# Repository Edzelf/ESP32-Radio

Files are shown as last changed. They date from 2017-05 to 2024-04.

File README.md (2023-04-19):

# Please use the V2 version of the ESP32-Radio.
# See https://github.com/Edzelf/ESP32Radio-V2
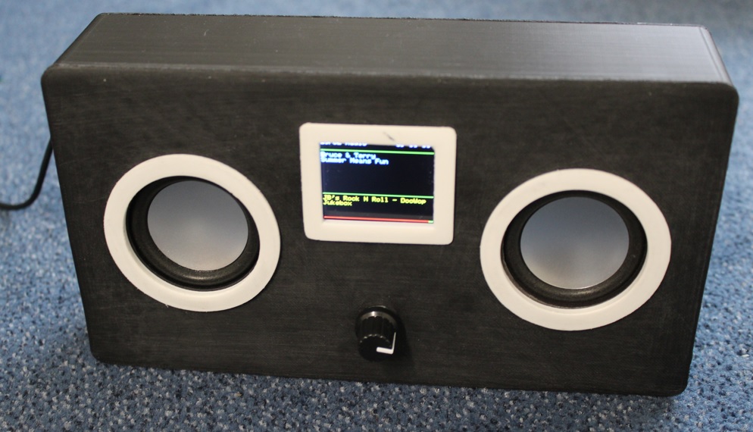
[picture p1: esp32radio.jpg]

Internet radio based on ESP32, VS1053 and a TFT screen.  Will compile in Arduino IDE.
See the review by Andreas Spiess at https://www.youtube.com/watch?v=hz65vfvbXMs.

Look for documentation and printdesign in the doc directory.

Features:
-	Can connect to thousands of Internet radio stations that broadcast MP3 or Ogg audio streams.
- Can connect to a standalone mp3 file on a server.
- Support for .m3u playlists.
- Can play mp3 tracks from SD card or USB stick (CH376).
-	Uses a minimal number of components; no Arduino required.
-	Handles bitrates up to 320 kbps.
-	Has a preset list of maximal 100 favorite radio stations in configuration file.
- Configuration (preferences) can be edited through web interface.
-	Can be controlled by a tablet or other device through a build-in webserver.
- Can be controlled over MQTT.
- Can be controlled over Serial Input.
- Can be controlled by IR.
-	Can be controlled by rotary switch encoder.
- Can be controlled by touch pins.
-	Up to 14 free input pins can be configured to control the radio.
-	The strongest available WiFi network is automatically selected.
-	Heavily commented source code, easy to add extra functionality.
-	Debug information through serial output.
-	Uses a 12 kB queue to provide smooth playback.
-	Software update over WiFi possible (OTA) through Arduino IDE or remote host.
-	Bass and treble control.
-	Saves volume, bass, treble and preset station over restart.
- Configuration also possible if no WiFi connection can be established.
- Can play iHeartRadio stations.
- Displays time of day on TFT.
- Optional display remaining battery capacity on screen.
- PCB available (see doc).
- 3D case available (see doc).

See documentation in doc/pdf-file.

Last changes:
- 28-jun-2021, Allow special characters in station name.
- 21-jun-2021, Display station name from preference if not in metadata.
- 29-apr-2021, Fixed SSD1309 bug.
- 25-apr-2021, Fixed SSD1309 bug, thanks to Juraj Liso.
- 19-feb-2021, More Oled models.
- 16-feb-2021, Give BBC stations some time to react. See issue 437.
- 15-feb-2021, Added earch page.
- 21-jan-2021, Added PlatformIO version.
- 14-oct-2020, Clear artist and song on display at new station connect.
- 18-oct-2020, Fixed LCD2004 error.
- 30-sep-2020, Ready for ch376msc library version 1.4.4.
- 14-jul-2020, Dynamic status display in web interface.
- 10-jul-2020, Support for USB drive (CH376).
- 23-mar-2020, Allow playlists  on SD card.
- 21-dec-2019, Check for right (VS1053) CHIP.
- 16-dec-2019, Better logging claimSPI for debug.
- 24-apr-2019, Better handling of gettim().
- 09-oct-2018, Bug fix xSemaphoreTake.
- 04-oct-2018, Fixed compile error OLED 64x128 display.
- 28-sep-2018, Support for NEXTION display.
- 06-aug-2018, Added playlistposition for MQTT.  Correction negative time offset. OTA update through remote host.
- 02-aug-2018, Added support for ILI9341 display.
- 01-aug-2018, Added debug info for timing of IR remote.
- 30-jul-2018, Added GPIO39 and inversed shutdown pin.  Thanks to fletche.
- 25-jul-2018, Correction touch pins.
- 15-jul-2018, Correction tftset().
- 25-may-2018, Limit read from stream to free queue space.
- 04-may-2018, Made handling of playlistdata more tolerant.
- 31-may-2018, Bugfix. Crashed if I2C was used, but no pins assigned.
- 30-may-2018, Bugfix. Assigned DRAM to global variables used in ISRs.
- 11-may-2018, Bugfix for incidental crash in rotary encoder function.
- 08-may-2018, Support for 1602 display (I2C).
- 30-apr-2018, Bugfix: crashed when no IR was configured.
- 25-apr-2018, Support for different display (OLED 128x64 for now).
- 20-apr-2018, Added (unfinished) diptrace printdesign.
- 16-apr-2018, Handle ID3 tags while playing from SD.
- 13-apr-2018, Guard against empty strings on TFT.
- 05-mar-2018, Improved interface for Rotary Encoder.
- 03-mar-2018, Correction bug IR pin number.
- 15-feb-2018, Correction writing wifi credentials to NVS.
- 13-feb-2018, Disable clock during write-back of preferences.
- 22-jan-2018, Added remaining battery capacity, default I/O pins.
- 02-jan-2018, Stop/resume is one command now.
- 15-dec-2017, Correction defaultprefs.h.
- 13-dec-2017, Correction LCD display.
- 08-dec-2017, Faster handling of config page, more items published by MQTT, added pin_shutdown.
- 01-dec-2017, Better handling of playlists.
- 30-nov-2017, Hide passwords in config screen.
- 27-nov-2017, Replaced ringbuffer by FreeRTOS queue, play function on second CPU,
               Included improved rotary switch routines supplied by fenyvesi,
               Better IR sensitivity.
- 11-nov-2017: Increases ringbuffer size. Print measured bitrate at "test"-command.
- 30-aug-2017: Limit number of retries foor MQTT connection. Added MDNS transponder.
- 28-aug-2017: Preferences for SPI bus, touch pins.
               Corrected bug in handling programmable pins.
               Handling of http redirections.
- 28-jul-2017: Added rotary swich encoder, flexible GPIO assignment.
- 19-jul-2017: Minor corrections.
- 18-jul-2017: Show time of day on TFT.
- 04-jul-2017: Correction MQTT subscription, keep playing during long oprerations.
- 03-jul-2017: Webinterface control page shows current settings.
- 30-jun-2017: Improved MP3 player.
- 28-jun-2017: Added IR interface.
- 31-may-2017: Experimental: play MP3 tracks from SD card.
- 26-may-2017: Correction Upper/Lower Case compare.
- 26-may-2017: Allow connection from single hidden AP.
- 23-may-2017: First release, derived from ESP8266 version.

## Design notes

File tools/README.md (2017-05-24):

- Esp32_radio_init.ino is a tool to set preferences like WiFi networks to the ESP32.
- prefbug.ino          is a tool to test the NVS library.

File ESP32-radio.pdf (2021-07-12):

### ESP32-radio

This document describes the realization of an Internet radio based on an ESP32 WiFi module.
The ESP32 is the successor of the ESP8266. For the ESP8266 an Internet radio was build and now the software is ported to the ESP32. The Internet radio described here uses the ESP32 as well as a VS1053 module to decode the MP3 stream. A 1.8 TFT color display to give some information about the radio station that’s playing. This display has also a SD card slot. Mp3 tracks on an SD card can be played by the ESP32-radio. Other types of display are also supported, including NEXTION.

### Features:

- Can connect to thousands of Internet radio stations that broadcast MP3 audio streams.
- Can connect to a standalone mp3-file on a server.
- mp3 playlists supported.
- Can play MP3 files from SD card or USB flash drive.
- Uses a minimal number of components.
- Has a preset list of a maximum of 100 favorite radio stations as preferences in flash.
- Can be controlled by a tablet or other device through the built-in webserver.
- Can be controlled by MQTT commands. Status info is published by using MQTT.
- Can be controlled by commands on the serial input.
- Can be controlled by IR.
- Can be controlled by rotary switch encoder.
- Up to 14 input ports can be configured as control buttons like volume, skip to the next/previous/first/favorite preset station.
- I/O pins for TFT, VS1053, IR and rotary encoder can be configured in preferences.
- The strongest available WiFi network is automatically selected. Passwords are kept as preferences in flash. Heavily commented source code, easy to add extra functionality.
- Debug information through serial output.
- 2

nd processor is used for smooth playback.
- Update of software over WiFi (OTA) through Arduino IDE or remote server.
- Parameters like WiFi information and presets can be edited in the web interface.
- Plays iHeartRadio streams.
- Preset, volume, bass and treble settings are saved in preferences.
- Displays time of day on TFT.
- Optional displays remaining battery charge.
- Bit-rates up to 320 kbps.
- Control of TFT back-light.
- PCB available.
- 3D printable box available.

### Software:

The software for the radio is supplied as an Arduino sketch that can be compiled for the ESP32 using the Arduino IDE version 1.8.5. No Arduino is required in this project.
The following libraries are used:
- WiFi – for establishing the communication with WiFI, part of ESP32 core library
- SPI – for communication with VS1053 and TFT display, part of ESP32 core library
- WiFiMulti - to select the strongest WiFi network
- Adafruit_ST7735– driver for the TFT screen (if configurated).
This driver works also for the red ST7735 display.
- ArduinoOTA for software update over WiFi.
- PubSubClient to handle MQTT messages, see:
https://github.com/knolleary/pubsubclient
- SD and FS for reading from SD card.
- The map with the ESP32-radio sketch must also contain the supplied headerfiles “index_html.h”, “favicon_ico.h”, “radio_css.h”, “config_html.h”, "defaultprefs.h", "mp3play_html.h" and “about_html.h”. These files are included for the webinterface in PROGMEM.
Furthermore the files “Dummytft.h”, “LCD1602”, “SSD1306.h”, “bluetft.h”, “ILI9341.h”, “NEXTION.h” must be included in this map for the different LCD/OLED displays.

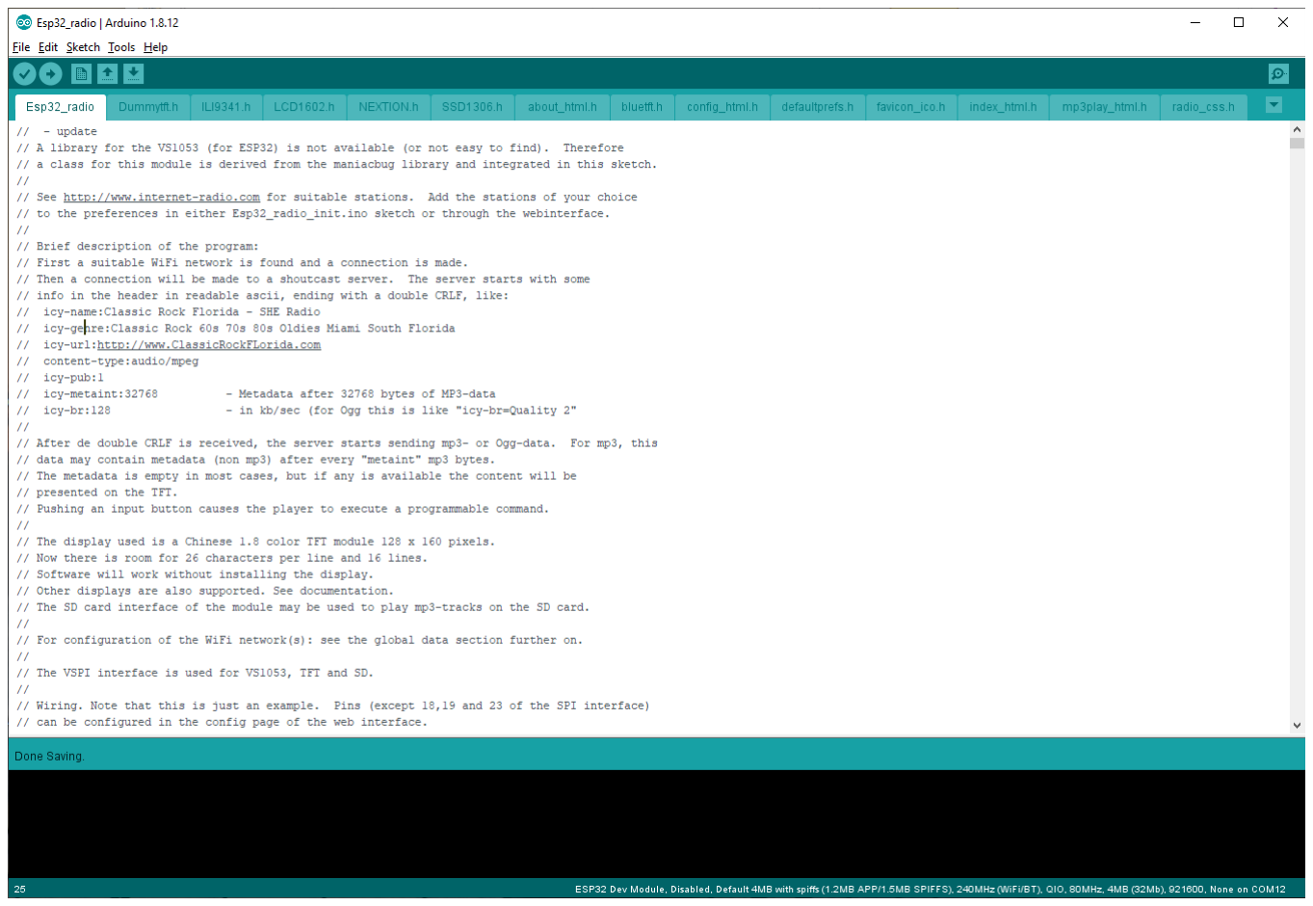
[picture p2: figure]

Preferences
Preferences for ESP32-Radio are kept in Flash memory (NVS).
You may change the contents of NVS with the “Config”-button in the web interface. An example of the contents is:
bat0 | = 2178 | # ADC for 0% battery capacity left
bat100 = 3256 | # ACD for 100% battery capacity
clk_dst = 1
clk_offset = -1
clk_server = pool.ntp.org
fs = USB
gpio_00 = uppreset = 1
gpio_12 = upvolume = 2
gpio_13 = downvolume = 2
ir_40BF = upvolume = 2
ir_C03F = downvolume = 2
mqttbroker = none
mqttpasswd = none
mqttport = 1883
mqttuser = carol
pin_enc_clk = 25 | # GPIO rotary encoder CLK
pin_enc_dt = 26 | # GPIO rotary encoder DT
pin_enc_sw = 27 | # GPIO rotary encoder SW
pin_ir = 35 | # GPIO IR receiver VS1838B
pin_sd_cs = 21 | # GPIO SD card CS
pin_tft_cs = 15 | # GPIO TFT CS
pin_tft_dc = 2 | # GPIO TFT DC
pin_vs_cs = 5 | # GPIO VS1053 CS
pin_vs_dcs = 16 | # GPIO VS1053 DCS
pin_vs_dreq = 4 | # GPIO VS1053 DREQ
preset = 4
preset_000 = 109.206.96.34:8100 | # 0 - NAXI LOVE RADIO, Belgrade, Serbia
preset_001 = airspectrum.cdnstream1.com:8114/1648_128 # 1 - Easy Hits Florida 128k preset_002 = airspectrum.cdnstream1.com:8142/1303_128 # 2 - CLASSIC ROCK MIAMI 256k preset_003 = airspectrum.cdnstream1.com:8000/1261_192 # 3 - Magic Oldies Florida
preset_004 = airspectrum.cdnstream1.com:8008/1604_128 # 4 - Magic 60s Florida 60s Classic Rock
preset_005 = 198.58.98.83:8258/stream | # 5 - Classic Rock Florida HD
preset_006 = icecast.omroep.nl:80/radio1-bb-mp3 | # 6 - Radio 1, NL
preset_007 = icecast.omroep.nl:80/radio2-bb-mp3 | # 7 - Radio 2, NL
preset_008 = skonto.ls.lv:8002/mp3 | # 8 - Skonto 128k
preset_009 = 94.23.66.155:8106 | # 9 - *ILR CHILL and GROOVE
preset_010 = ihr/IHR_IEDM | # 10 - iHeartRadio IHR_IEDM
preset_011 = ihr/IHR_TRAN | # 11 - iHeartRadio IHR_TRAN
toneha = 0
tonehf = 0
tonela = 0
tonelf = 0
volume = 72
wifi_00 = ADSL-11_plus/xxxxxx wifi_01 = NETGEAR-11/xxxxxx
wifi_02 = ADSL-11/xxxxxx

Not that the size of the NVS is limited to 20 kB.
Lines starting with “#” are comment lines and are ignored. Comments per line (after “#”) will also be ignored, except for the “preset_” lines. The comments on the “preset_” lines are used to identify the presets in the web interface. The maximum line length is 150 characters.
Note that the preset numbers ranges from 000 to 199. The range can be extended by the definition of MAXPRESETS. Note that there is also a limit on the NVS space. If the highest numbered station is reached, the next station will be 00 again. URLs with mp3 files or mp3 playlists (.m3u) are allowed.
Presets starting with "ihr/" are iHeartRadio stations.

Prteferences like "pin_ir", " pin_enc_clk", " pin_enc_dt", " pin_enc_sw", " pin_tft_cs", " pin_tft_dc", " pin_sd_cs", " pin_vs_cs", "pin_vs_dcs" and " pin_vs_dreq" specify the GPIO pins that are wired to the various devices. For a

FEATERBOARD you have to change some settings, especially for TFT and SD card. The pins for SPI default to SCK=18, MISO=19 and MOSI=23, but they may be configured by “pin_spi_sck”, “pin_spi_miso” and “pin_spi_mosi” respectively.
For an I2C display (OLED, LCD1602, LCD2004) there must be definitions for " pin_tft_scl" and " pin_tft_sda".
Remove the lines if a device is not connected.

“pin_shutdown” is the pin that will be set if the radio is not playing or the volume is set to zero. This output-pin can be used to shut down the amplifier.
“pin_shutdownx” has the same function. The output signal is inversed: the pin will be LOW to shut down the amplifier.

"pin_tft_bl" is the pin that controls the back light of a TFT display. The BL is disbled after some time if there is no activity. This helps to reduce power when running on batteries.
"pin_tft_blx" has the same function. The output signal is inversed (LOW to enable the BL pin).

The "gpio_" lines specify input pins and the command that is executed if the input pin goes from HIGH to LOW.

The "touch_" lines specify the GPIO input pins for this signal and the command that is executed if the input pin is activated.

The "ir_XXXX" lines specify IR-codes and the command that is executed if the IR-code is received. The code part is a hexadecimal number in upper-case characters.

The "clk_" lines are used for the display of the current time on the TFT. Please change the values for your timezone. The values in the example are valid for the Netherlands.

The “fs” line specifies the file system for MP3 player mode. The file system can be USB or SD for USB drive and SD card respectively. Note that the sketch must be compiled for USB or SD card support. See the defines for SDCARD and/or CH376.

The “bat0” and “bat100” lines are for displaying the remaining battery capacity on the display. See the details at the paragraph with optional features.

The preferences can be edited in the web interface. Changes will in some cases be effective after restart of the Espradio. If the list of preferences is empty (first start), you may use the default button. The list will show some default values which can be edited.

Using Winamp to find out the correct preset line for a station.

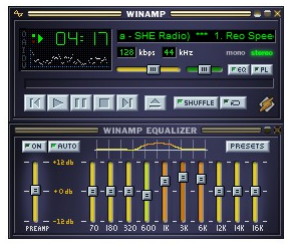
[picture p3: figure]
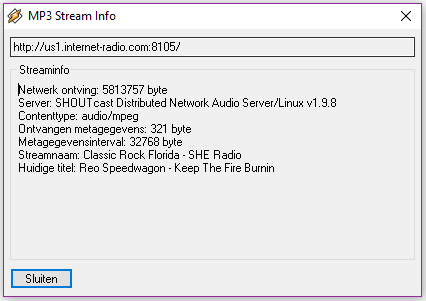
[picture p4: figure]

Press Alt-3 in the main window (left picture). You will see info for the playing station (right picture). The top line (with “http”) will contain the information for the preset, in this example:

“us1.internet-radio.com:8105”. The complete line for this station in the preferences would be:

preset_05 = us1.internet-radio.com:8105 | # 5 - Classic Rock Florida - SHE Radio

Optional features:

Digital control through input pins:
Normally the radio is controlled by the web interface. However, free digital inputs (GPIO) may be connected to buttons to control the radio. Their function can be programmed using the web interface.

You can assign commands to the digital inputs by adding lines in the configuration (Webinterface, "Config" page). Examples:

gpio_00 = uppreset = 1
gpio_12 = upvolume = 2
gpio_13 = downvolume = 2
gpio_14 = stop
gpio_17 = resume
gpio_21 = station = icecast.omroep.nl:80/radio1-bb-mp3

In this example the ESP32-Radio will execute the command "uppreset=1" if GPIO0 will go from HIGH to LOW. The commands are equal to the commands that are handled by the serial input or by the MQTT interface.

The same format can be used for the touch-inputs:

touch_04 = uppreset = 1
touch_13 = upvolume = 2
In this example the ESP32-Radio will execute the command "uppreset=1" if TOUCH0 (GPIO04) will be activated. The commands are equal to the commands that are handled by the serial input or by the MQTT interface.

IR Interface.
The radio can be controlled by an IR remote control like this:

To use this interface, the "out" pin of a VS1838B receiver must be connected to a GPIO pin of the ESP32:

Add the assigned GPIO pin to the preferences through the config page in the web interface. Example:
pin_ir = 35 | # GPIO Pin number for IR receiver VS1838B

VCC is connected to 3.3 Volt. A 220 µF capacitor should be connected between VCC and GND.
The software will read the raw code of the IR transmitter, making it possible to use virtually any remote control to be used. I tested it with the 21 button remote as well as with an LG TV remote.
To assign functions to the buttons, watch the debug log output while pressing a button. For example, press the +volume button. You will see something like:
D: IR code 807F received, but not found in preferences!
Now add the command:
ir_807F = upvolume = 2
to the preferences in the config page of the web interface. Likewise you can assign functions to all buttons, for example:
ir_8A31 = uppreset = 1
ir_719A = station = us1.internet-radio.com:8105
ir_1F6B = mute

Display remaining battery capacity:
The remaining battery capacity is computed by measuring the battery voltage on ping GPIO36 (ADC0).
The battery voltage must be supplied to ADC0 through a resistor voltage divider. The maximum voltage fort his input is 1.0 volt. I used 100 kΩ and 22 kΩ fort his purpose.
Furthermore you need to specify ADC value for both the full and the empty voltages. These values must be in the preferences like:
bat0 | = 2178 | # ADC for 0% battery capacity left
bat100 = 2690 | # ACD for 100% battery capacity

To calibrate the settings you may use the “TEST” command in the serial monitor. This will display the current reading of the ADC0 pin. Do this for a fully charge battery and for an (almost) empty one.
Note that it will take about 6 seconds before the reading is stable. This is a result of a filter in the measurement of the ADC.

The remaining capacity is displayed as a green/red bar near the top of the display.

### Hardware:

The radio is built with the following widely available hardware:
- An ESP-32 module. This is basically an ESP32 on a small print. I used a DOIT ESP32 Development Board. See figure 1 below. The ESP32 is running on 160 MHz. On Aliexpress: this. (https://www.aliexpress.com/item/Elecrow-Official-DOIT-ESP32S-esp32-Development-Board-WiFi-Bluetooth-Dual-Core-CPU-Low-Power-Consumption-DIY/32804562215.html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)
- A VS1053 module. See figure 2.
- A 1.8 inch color TFT display 160x128. Optional, see figure 3 and 4. On Aliexpress: this (https://www.aliexpress.com/item/1-8-Serial-128X160-SPI-TFT-LCD-Module-Display-PCB-Adapter-Power-IC-SD-Socket-R179/32602828489.html) or this. (https://www.aliexpress.com/item/Smart-Electronics-1-8-Inch-128-160-Serial-SPI-TFT-LCD-Module-Display-PCB-Adapter-Power/32597366825.html)
- A 1.44 inch color TFT display 128x128. Optional, see figure 9. On Aliexpress: this. (https://www.aliexpress.com/item/Replace-5110-LCD-1-44-Red-Serial-128X128-SPI-Color-TFT-LCD-Display-Module/32852197696.html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)
- An OLED 128x64 display. Optional, see figure 7. On Aliexpress: this. (https://www.aliexpress.com/item/1pcs-SAMIORE-ROBOT-0-96-white-blue-yellow-0-96-inch-128X64-OLED-Display-Module-0/32640136921.html)
- An 1602 LCD display with I2C backpack. Optional, see figure 8.
- An 2004 LCD display with I2C backpack. Optional, see figure 13.
- A NEXTION display. Optional, see figure 10. Tested with a NX3224T024_011.
- Two small speakers.
- A Class D stereo amplifier to drive the speakers. Best quality if powered by a separate power source.
- A rotary encoder switch. Optional, see figure 4.
- A IR receiver. Optional, see figure 6.
- Two audio transformers. Optional, see figure 11.
- Optional CH376 drive for USB stick, see figure 12.
Fig. 1 | Fig. 2 | Fig. 3

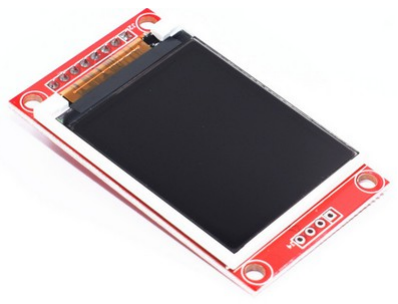
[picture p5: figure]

Fig. 4 | Fig. 5

Fig. 6

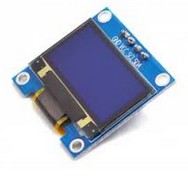
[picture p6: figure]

Fig. 7

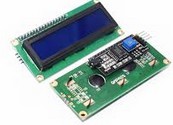
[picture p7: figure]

F

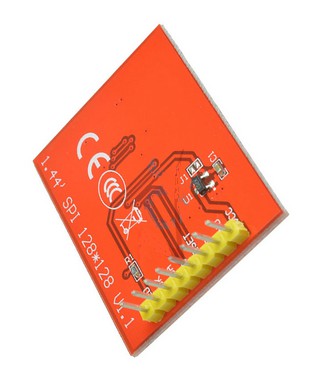
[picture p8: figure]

fig. 8 | Fig. 9

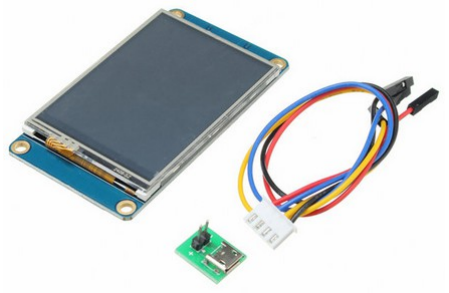
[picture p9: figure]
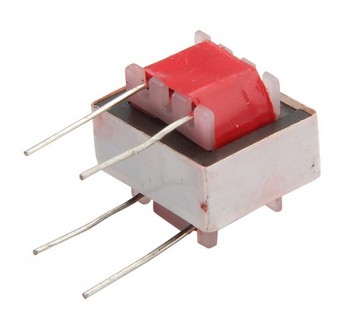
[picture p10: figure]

Fig. 10 | Fig. 11

Fig. 13

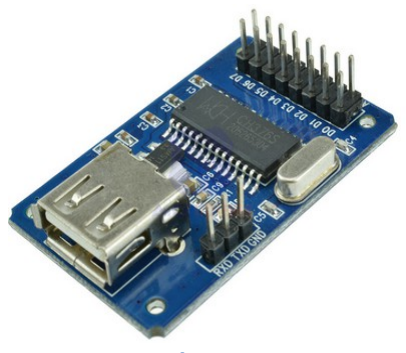
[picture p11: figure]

Fig. 12

Here is a picture of the radio in a test configuration. Only the VS1053 is connected.

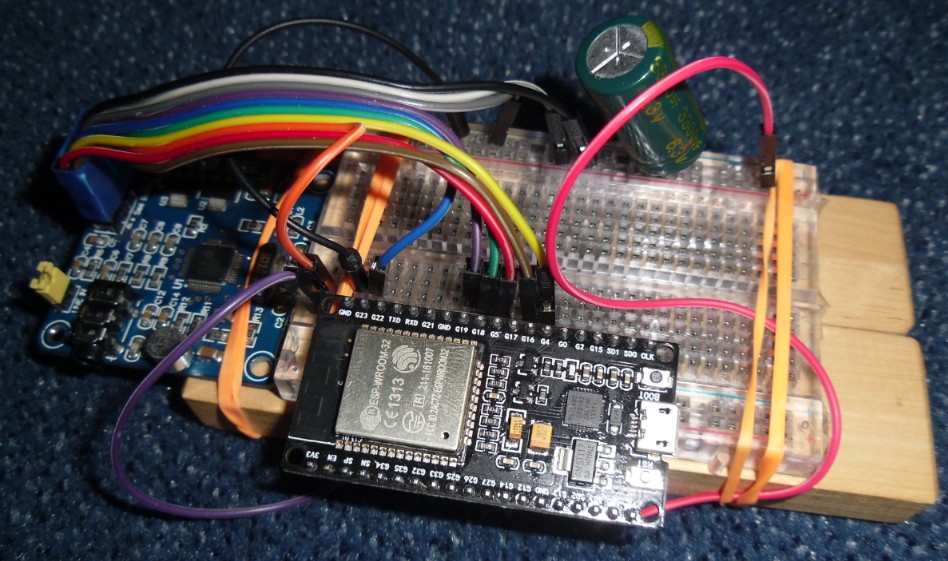
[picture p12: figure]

The module is not very breadboard friendly. The (hanging over) +5 Volt of the ESP32 is wired to the 5Volt rail of the breadboard. The big capacitor (3300 µF) is added to allow powering the module from USB. Without it, the USB has insufficient power to drive the ESP32.

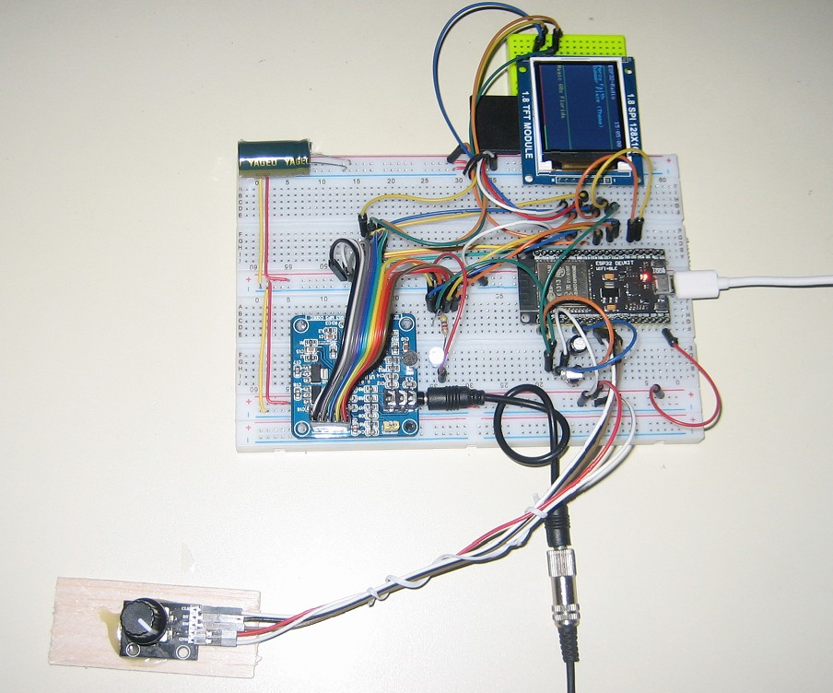
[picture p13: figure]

Another prototype. This time with SD-card, TFT, IR and rotary switch.

The radio may be powered by a 5 V adapter. The radio will function on single LiPo cell as well, so I added a small charge circuit powered by the 5 V input. The amplifier uses a separate LiPo cell to minimize noise caused by the ESP32. The TFT and VS1053 work on 3.8 to 5 Volt.

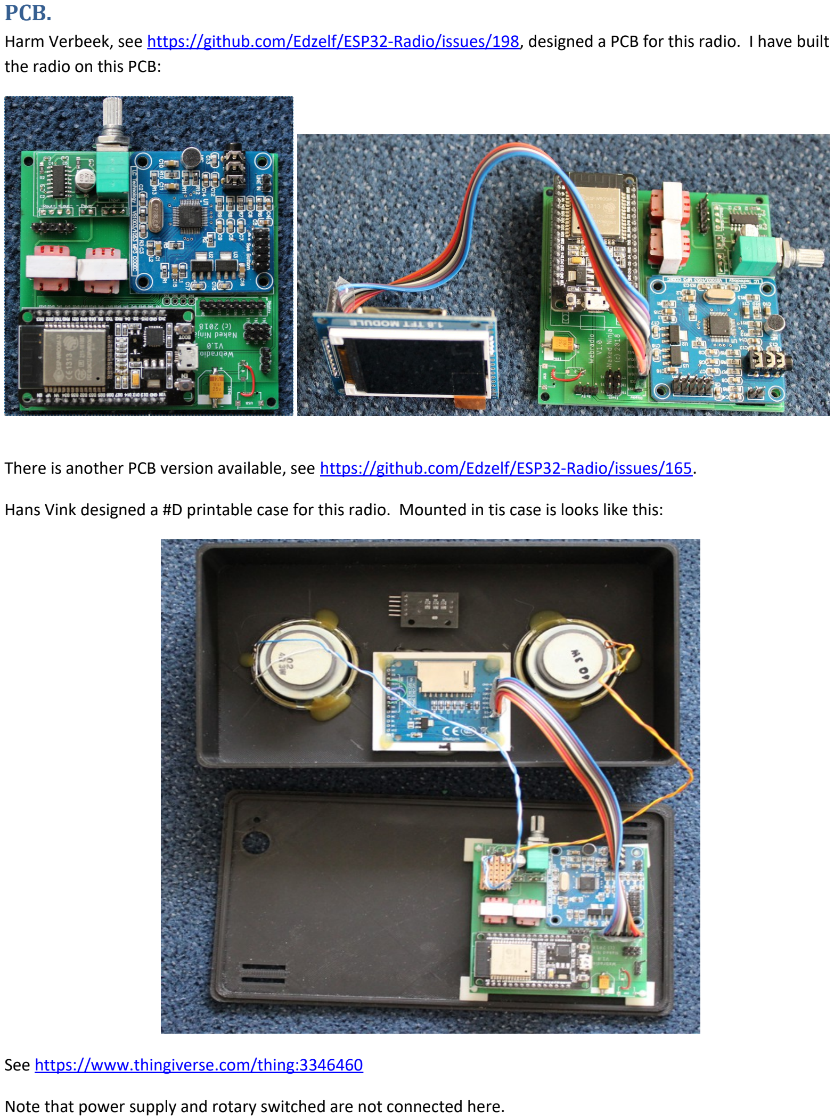
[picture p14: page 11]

PCB.
Harm Verbeek, see https://github.com/Edzelf/ESP32-Radio/issues/198, designed a PCB for this radio. I have built the radio on this PCB:

There is another PCB version available, see https://github.com/Edzelf/ESP32-Radio/issues/165.

Hans Vink designed a #D printable case for this radio. Mounted in tis case is looks like this:

See https://www.thingiverse.com/thing:3346460

Note that power supply and rotary switched are not connected here.

And playing:

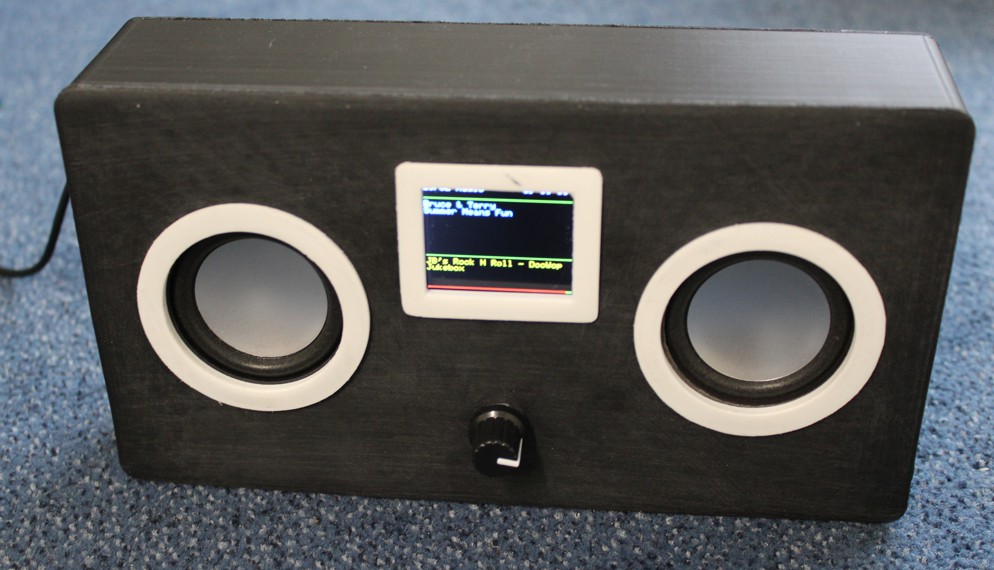
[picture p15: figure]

### Wiring:

The logic wiring in the table below. The analog amplifier and the speakers are not included.

Note that the GPIO pins are just an example. The assignment of GPIO pins is defined in the preferences that can be edited in the "config" page of the web interface.

ESP32dev Signal Wired to LCD | Wired to VS1053 | SDCARD | Wired to the rest
GPIO16 | | - | pin 1 XDCS | - | -
GPIO5 | | - | pin 2 XCS | - | -
GPIO4 | | - | pin 4 DREQ | - | -
GPIO2 | | pin 3 D/C or A0 | - | - | -
GPIO22 | | - | - | CS | -
GPIO21 | RXD2 | - | - | - | TX of NEXTION (if in use)
GPIO17 | TXD2 | - | - | - | RX of NEXTION (if in use)
GPIO18 | SCK | pin 5 CLK or SCK | pin 5 SCK | CLK | -
GPIO19 | MISO | - | pin 7 MISO | MISO | -
GPIO23 | MOSI | pin 4 DIN or SDA | pin 6 MOSI | MOSI | -
GPIO15 | | pin 2 CS | - | - | -
GPI03 | RXD0 | - | - | - | Reserved serial input
GPIO1 | TXD0 | - | - | - | Reserved serial output
GPIO34 | - | - | - | - | Optional pull-up resistor
GPIO35 | - | - | - | - | Infrared receiver VS1838B
GPIO25 | - | - | - | - | Rotary encoder CLK
GPIO26 | - | - | - | - | Rotary encoder DT
GPIO27 | - | - | - | - | Rotary encoder SW
GND | - | pin 8 GND | pin 8 GND | | Power supply GND
VCC 5 V - | pin 7 BL | - | Power supply
VCC 5 V - | pin 6 VCC | pin 9 5V | Power supply
EN | - | pin 1 RST | pin 3 XRST | | -
The wiring of the 1.8 inch TFT module is on the right side of the board.
If you use the SD-card on this module, you can wire MOSI and CLK (SPI signals) on the connector on the left side:

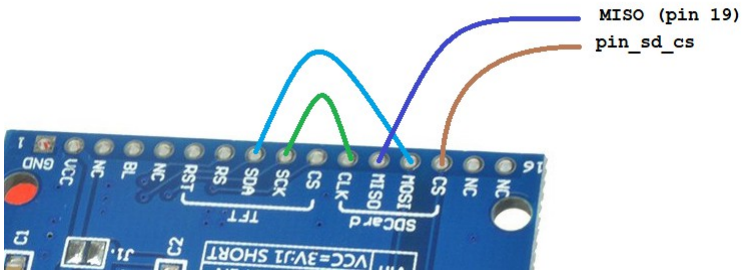
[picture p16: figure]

In this case, only 2 extra wires are needed for using the SD feature: The MISO signal (pin GPIO19 of the ESP32) and the Chip Select. CS in this example is pin GPIO21, but it can be defined by “pin_sd_cs” in the configuration page of the web interface.

If you want to connect an USB drive, you have to wire the CH376 module as follows:

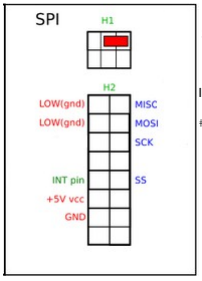
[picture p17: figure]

MISO, MOSI and SCK: wire to the SPI bus.
SS is the select pin, wire to the pin defined by “ch376_cs_pin”.
INT is the interrupt pin, wire to the pin defined by “ch376_int_pin”.

In the sketch you have to define “CH376” near line 166, like:

#define CH376 // For CXH376 support (reading files from USB stick)

Amplifier and power circuit.
The amplifier is a class D stereo amplifier. If the power is shared with the power supply of the radio, you will hear much noise. So I used a separate LiPo battery (Batt 2) for the amplifier.

During operation only Batt 1 will be charged. If the radio is switched off, both batteries will be recharged by the LiPo charger. S1a, S1b and S1c is a triple On-On switch.

Note that there may be high currents in the “off”-position if one of the batteries fully discharged. Use protected batteries only!

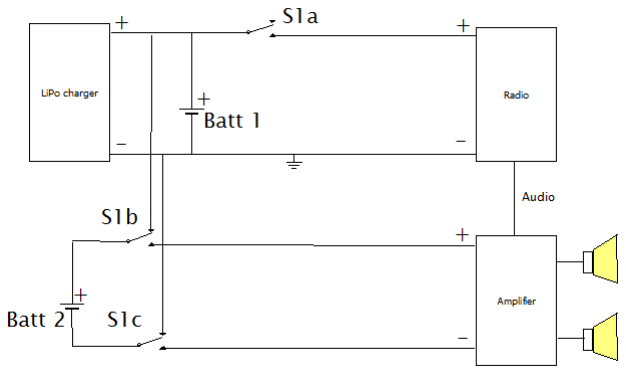
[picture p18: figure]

A better approach is to use 2 small audio transformers (Fout: Bron van verwijzing niet gevonden) to isolate the output of the VS1053 from the power circuit. This is used on the PCB made by Harm Verbeek.

Backlight control circuit.

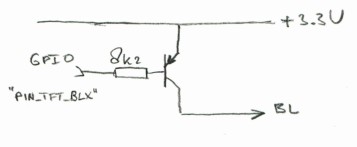
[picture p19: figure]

Web interface.
The web interface is simple and can be adapted to your needs. The basic idea is to have a html page with embedded javascript that displays an interface to the radio. Command to the radio can be sent to the http server on the ESP32. The IP address of the webserver will be displayed on the TFT during startup. The webpages are defined in
PROGMEM.

### Capabilities of the webserver:

Let’s assume that the IP of the ESP32-radio is 192.168.2.12. From your browser you can show a simple root page by entering the following URL: http://192.168.2.12. This will display the index_html.h page from the PROGMEM as well as favicon_ico.h.

If your computer is configured for mDNS, you can also use http://ESP32Radio.local (http://esp-radio.local/) in your browser.

The following simple web interface will be displayed:

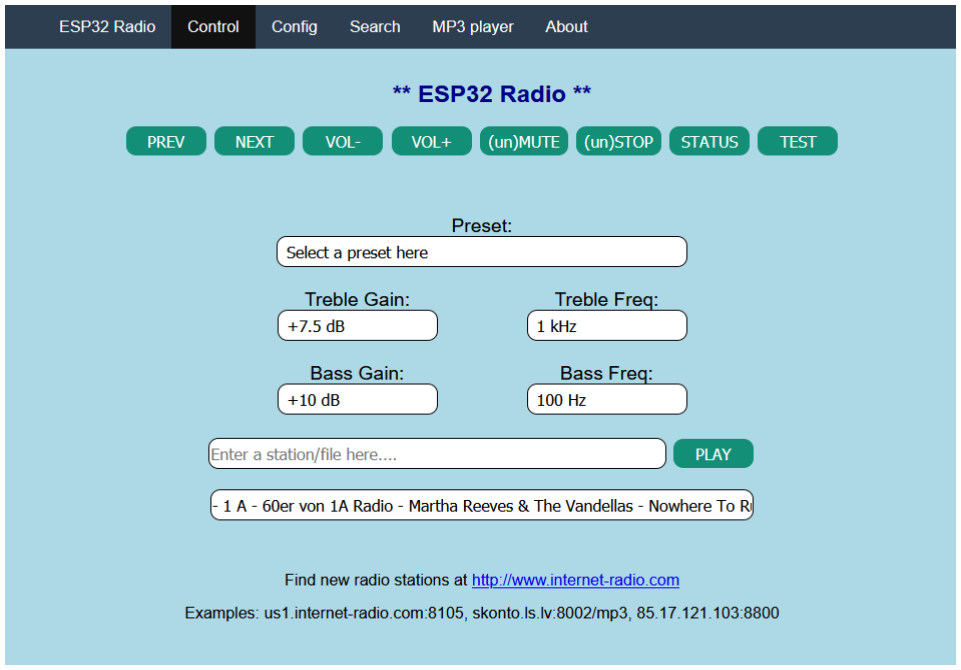
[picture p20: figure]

Clicking on one of the available buttons will control the ESP32-radio. The reply of the webserver will be visible in the status box below the buttons. A click will be translated into a command to the ESP32-radio in the form:

http://192.168.2.12/?<parameter>=<value>

For example: http://192.168.2.12/?upvolume=2

The “STATUS” and “TEST” buttons give some info about the playing stream/file. The “Search” menu option can be used to discover stations. The list of stations is maintained by Community Radio Browser. See https://www.radio-browser.info. (https://www.radio-browser.info/)

Not all functions are available as buttons in the web interface shown above. Commands may also come from MQTT or serial input. Not all commands are meaningful on MQTT or serial input. Working commands are:

preset | = 12 | Select start preset to connect to
preset_00 = <mp3 stream> | Specify station for a preset 00-max *)
volume | = 95 | Percentage between 0 and 100
upvolume | = 2 | Add percentage to current volume
downvolume = 2 | Subtract percentage from current volume
toneha | = <0..15> | Setting treble gain
tonehf | = <0..15> | Setting treble frequency
tonela | = <0..15> | Setting bass gain
tonelf | = <0..15> | Setting treble frequency
station | = <mp3 stream> | Select new station (will not be saved)
station | = <URL>.mp3 | Play standalone .mp3 file (not saved)
station | = <URL>.m3u | Select playlist (will not be saved)
stop | | Stop playing
resume | | Resume playing
mute | | Mute/unmute the music (toggle)
wifi_00 | = mySSID/mypassword | Set WiFi SSID and password *)
mqttbroker = mybroker.com | Set MQTT broker to use *)
mqttprefix = XP93g | Set MQTT broker to use
mqttport | = 1883 | Set MQTT port to use, default 1883 *)
mqttuser | = myuser | Set MQTT user for authentication *)
mqttpasswd = mypassword | Set MQTT password for authentication *)
clk_server = pool.ntp.org | Time server to be used *)
clk_offset = <-11..+14> | Offset with respect to UTC in hours *)
clk_dst | = <1..2> | Offset during dst in hours *)
mp3track | = <nodeID> | Play track from SD card, nodeID 0 = random
settings | | Returns setting like presets and tone
status | | Show current URL to play
test | | For test purposes
debug | = 0 or 1 | Switch debugging on or off
reset | | Restart the ESP32
bat0 | = 2318 | ADC value for an empty battery
bat100 | = 2916 | ADC value for a fully charged battery
fs | = USB or SD | Select local filesystem for MP# player mode.

Commands marked with "*)" are sensible during power-up only.

Station may also be of the form “skonto.ls.lv:8002/mp3”. The default port is 80.
Station may also point to an mp3 playlist. Example: “www.rockantenne.de/webradio/rockantenne.m3u”.
Station may be an .mp3-file on a remote server. Example: "www.stephaniequinn.com/Music/Rondeau.mp3". Station may also point to a local .mp3-file on SD card. Example: “localhost/friendly.mp3”.
It is allowed to have multiple (max 100) “preset_” lines. The number after the “_” will be used as the preset number. The comment part (after the “#”) will be shown in the web interface.

It is also allowed to have multiple “wifi_” lines. The strongest Wifi access point will be used.

### Configuration

The "Config" button will bring up a second screen. Here you can edit the preferences. The available Wifi networks are listed as well. The config screen will be shown automatically if the ESP32 cannot connect to one of the WiFi stations specified in the preferences. In that case the ESP32 will act as an accesspoint with the name “ESP32Radio”. You have to connect to this AP with password “ESP32Radio”. Then the ESP32-radio can be reached at http://192.168.4.1.
The configuration screen will be displayed and you have the opportunity to edit the preferences. A "default" button is available to fill the editbox with some example data. For a quick start, just fill in you WiFi network name and password and click "Save". Restart the radio afterwards.
Note that passwords are hidden in this screen to give some protection against abuses. You may however change them here. If unchanged, the original values are preserved.

After changing the contents of this page, it must be saved to the preferences by clicking the “Save” button. Changes will have effect on the next restart of the ESP-radio, so click the “Restart” button.

The “Update”-button can be used to get the latest version of the software by downloading it from http:smallenburg.nl/Arduino/ Esp32_radio.ino.bin.

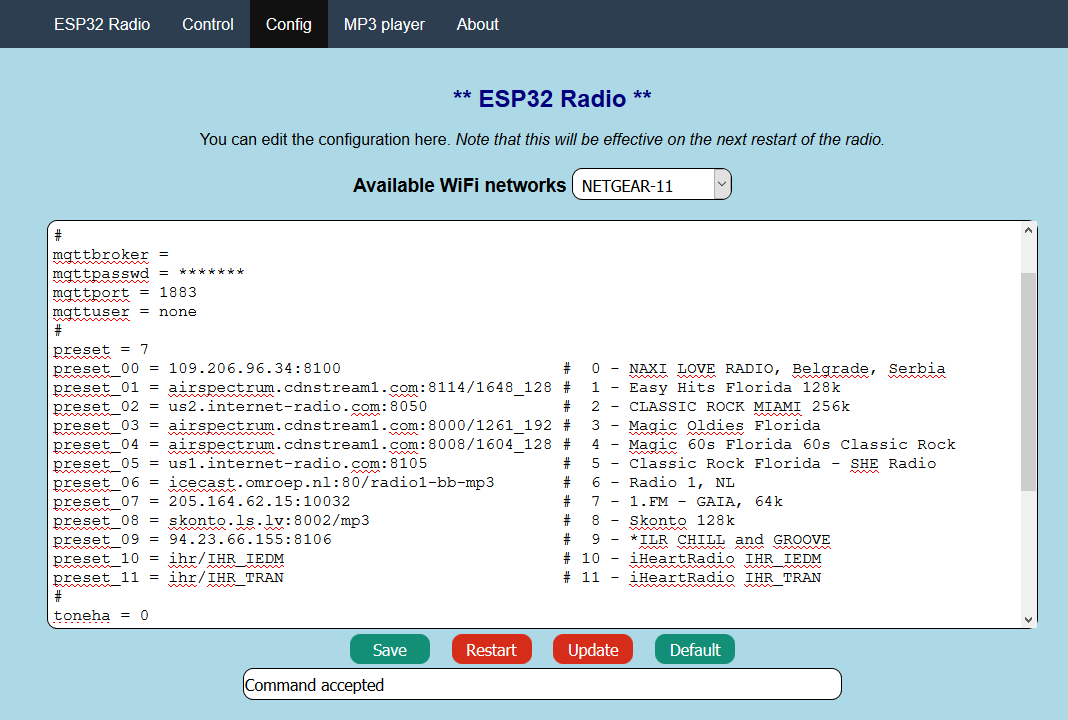
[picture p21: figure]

It may take some time to fill this screen.

MP3 player
ESP32-Radio can also be used as an mp3 player if an SD card interface is available. The screen will look like this:

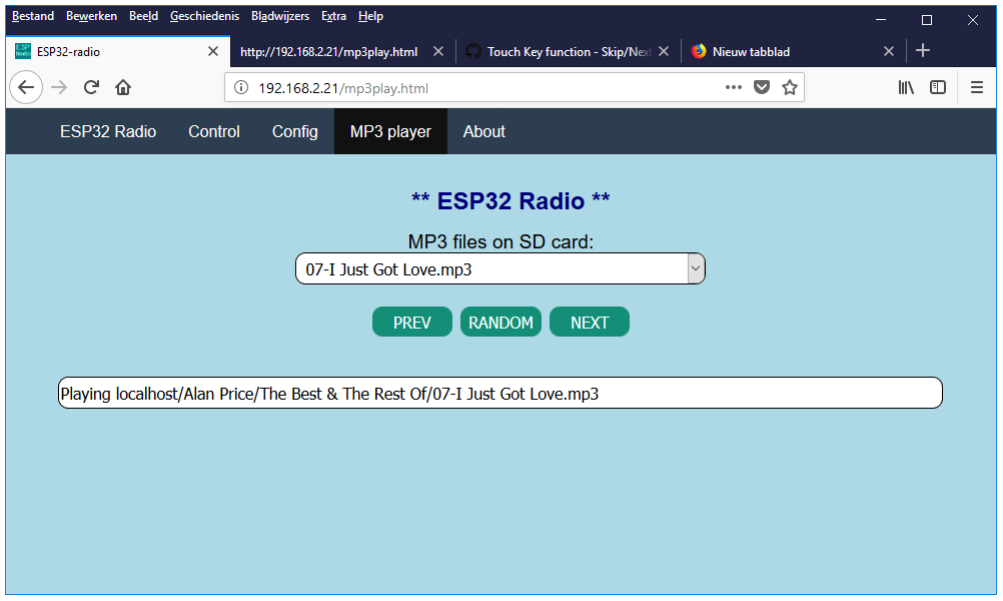
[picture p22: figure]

When this page is called for the first time, a search for all tracks on the SD card will be executed. This may take some time. All found tracks will be available in the drop-down list on the screen. You may pick a track and it will play. When the track has finished, the next track in the drop-down list will be played automatically.

The “PREV” and “NEXT” buttons will select the previous or next track to be played respectively. You may also click the "RANDOM" button and a random track will be played. If the track has finished a new random song will be selected. In “RANDOM” mode, the “PREV” and “NEXT” buttons will also select a random track.

It may take some time to fill this page because the directories on the SD card are searched for MP3 tracks.

Playlist.
You may use playlists for the MP3 player as well. Playlists have the “.m3u” extension and4 can reside on every sub-directory of the SD card. An example of a playlist (“playlist1.m3u” in the rootdirectory) with tracks pointing to subdirectories (MAP0, MAP4) may look like:

#EXTM3U

#EXTINF:124,01bachfugue.mp3 MAP0/bachfugue.mp3

#EXTINF:177,02gtr-nylon22.mp3 MAP0/gtr-nylon22.mp3

#EXTINF:207,03harpsi-cs.mp3 MAP0/harpsi-cs.mp3

#EXTINF:100,01viola2.mp3

MAP4/viola2.mp3
#EXTINF:101,02violin.mp3

MAP4/violin.mp3
#EXTINF:102.03vln-lin-cs.mp3 MAP4/vln-lin-cs.mp3

A preset to this playlist could be:

preset_008 = /localhost/playlist1.m3u
You may also start this playlist by entering “localhost/playlist1.m3u” in the “Play” box of the web interface.

Rotary encoder interface.
The rotary encoder switch can control some essential functions of the ESP32-radio. The "GND"- and "+"-pins must be connected to ground and 3.3 Volt pins of the ESP32 DEV module.

The default function is volume control. Turning the knob will result in lower or higher volume. Pressing the knob will mute/unmute the signal. The text “Mute” or “Unmute” will be shown on the TFT during 4 seconds.

A double click selects the preset-mode. Rotation of the switch will select one of the preset stations. The preset will be shown on the TFT. Once a preset is selected, you can activate this preset by a single click.
Without rotation, the next preset is selected.

A triple click will select the mp3-player (SD card required). Rotation of the switch will select one of the tracks on the SD card. The track will be displayed on the TFT. Once a track is selected, you can activate it by a single click. Without rotation, the next track is selected.
After the triple click the player stops, as reading filenames will overload the SD card I/O.

A long click ( longer than 1 second ) will start playing random tracks from SD card.

After an inactivity of 4 seconds the rotary encoder will return to its default function (VOLUME).

Supported displays.
The preferred display is a 1.8 inch TFT with 160x128 pixels. Other displays may also be used:
1. No display. Edit the sketch (around line 123), so that “DUMMYTFT” is defined and all other display types are commented out.
2. The preferred display 160x128 pixels. Define “BLUETFT” and comment out the other types.
3. An ILI9341 display, default 320x240 pixels. Define “ILI9341” and comment out the other types.
4. A 128x128 1.44 inch display. Edit bluetft.h (around line 58), use “INITR_144GREENTAB” and set dsp_getwidth() to 128.
5. A 128x64 OLED. Define “”OLED” and comment out the other types.
6. AN LCD 1602 display with I2C backpack. Define “LCD1602I2C” and comment out the other types. Note that this display is limited as it has only 32 characters.
7. AN LCD 2004 display with I2C backpack. Define “LCD2004I2C” and comment out the other types. Note that this display is limited as it has only 80 characters.
8. A NEXTON model NX#@@$T024_11 display connected to GPIO 16 and 17.

The OLED, 2004 and 1602 displays use the serial I2C bus. There must be definitions for this in the preferences, for example:

pin_tft_scl = 13 | # GPIO Pin number for SCL
pin_tft_sda = 14 | # GPIO Pin number for SDA

Th I2C address of the 2004 and 1602 displays is defined in the corresponding module.

MQTT interface.
The MQTT interface can handle the same commands as the web interface.
As publish command on a Linux system may look like:

$ mosquitto_pub -h broker.hivemq.com -t espradio -m volume=80

Note that broker.hivemq.com is heavily used, this may cause some delay. If you use your own broker the reaction on commands will be much better.
Remove the lines starting with “mqtt” if no MQTT is required or set mqttbroker to "none".

You can use an MQTT client like https://kamilfb.github.io/mqtt-spy/ to view the MQTT interface.

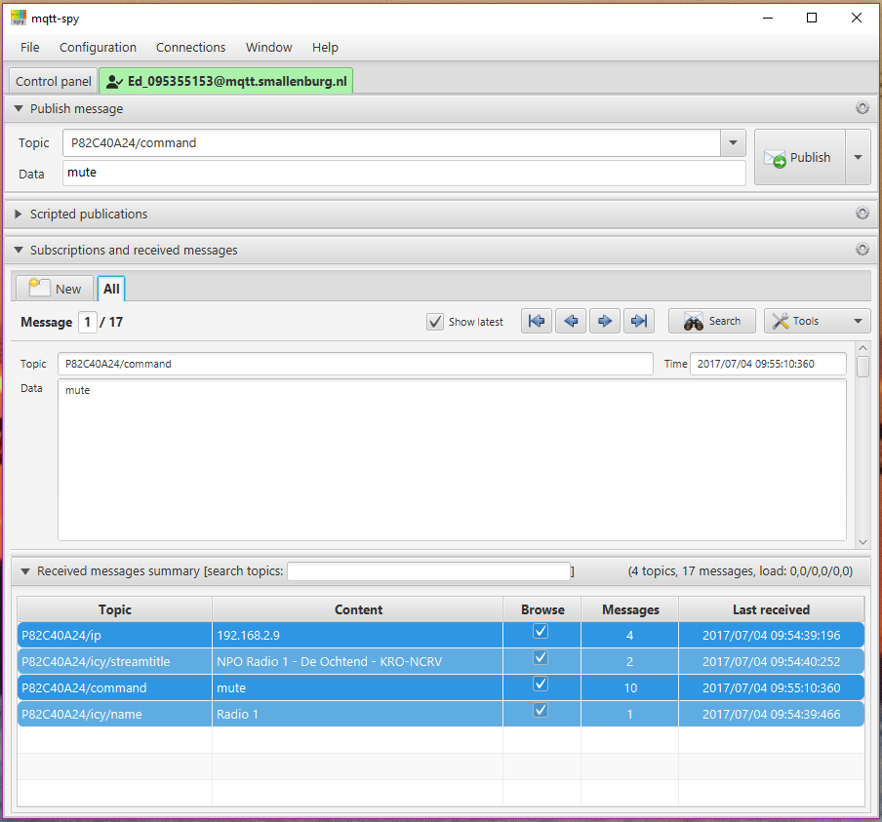
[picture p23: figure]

Subscribe to “P82C40A24/ip” and you will see the IP-address of your radio. You will see the IP address of your radio or the IP address of a different user. So be sure to use unique names for your topics. This can be accomplished by specifying a unique prefix in the preferences, see below.
The parameters in preferences for this example are:

# MQTT broker, credentials and topic to subscribe

mqttbroker = broker.hivemq.com | # Broker to connect with
mqttprefix = P82C40A24 | # Prefix for pub/sub. Default is part of MAC-address.
mqttport = 1883 | # Portnumber (1883 is default)
mqttuser = none | # (No) username for broker
mqttpasswd = none | # (No) password for broker

In this example I published the command “mute” to the radio. The radio published the IP-address 192.168.2.8 to the broker (once every 10 minutes).

MQTT PUB topics.
In this version 7 topics will be published to MQTT and can be subscribed to by an MQTT client:
prefix/ip | The IP-address of the ESP32-Radio
prefix/icy/name | The name of the station
prefix/icy/streamtitle | The name of the stream
prefix/nowplaying | Track information
prefix/preset | Preset currently plaing
prefix/volume | Current volume setting
prefix/playing | 1 if playing, 0 if stopped

Command to control the ESP32-Radio can be published to "prefix/command".

Alternative way of configuration.
An extra sketch "Esp32_radio_init" is supplied as an alternative to initialize the preferences (in Non-Voltile Storage of the ESP32). Just change lines 39 and 40 (the specs for WiFi networks) to match your network(s).

Upload and run the sketch once and then load the ESP32-Radio.

OTA update through remote server.
The software can be update by uploading the compiled project to the ESP32. There is also a build-in feature to load the latest version of the software from a remote server. The software for the NEXTION (if in use) will also be updated.

The update can be initiated by the “update”-command through the serial interface or the webinterface.

The update will fail if there is no new version available or if no connection can be made to the server.

The radio connects to the host “smallenburg.nl” and download the file “/Arduino/Esp32_radio/firmware.bin” and “/Arduino/ESP32-Radio.tft”. The binary file is flashed to the ESP32 and the NEXTION and will start the new version. The process may take some 2 to 3 minutes.

Compiler/upload output.

> Executing task in folder ESP32-Radio: C:\Users\hp\.platformio\penv\Scripts\platformio.exe run --target upload <

Processing esp32doit-devkit-v1 (platform: espressif32; board: esp32doit-devkit-v1; framework: arduino)
----------------------------Verbose mode can be enabled via `-v, --verbose` option CONFIGURATION: https://docs.platformio.org/page/boards/espressif32/esp32doit-devkit-v1.html PLATFORM: Espressif 32 (3.3.0) > DOIT ESP32 DEVKIT V1
HARDWARE: ESP32 240MHz, 320KB RAM, 4MB Flash
DEBUG: Current (esp-prog) External (esp-prog, iot-bus-jtag, jlink, minimodule, olimex-arm-usb-ocd, olimex-arm-usb-ocd-h, olimex-arm-usb-tiny-h, olimex-jtag-tiny, tumpa)
PACKAGES:
- framework-arduinoespressif32 3.10006.210326 (1.0.6)
- tool-esptoolpy 1.30100.210531 (3.1.0)
- tool-mkspiffs 2.230.0 (2.30)
- toolchain-xtensa32 2.50200.97 (5.2.0)
LDF: Library Dependency Finder -> http://bit.ly/configure-pio-ldf LDF Modes: Finder ~ chain, Compatibility ~ soft
Found 33 compatible libraries
Scanning dependencies...
Dependency Graph
|-- <Wire> 1.0.1
|-- <SD(esp32)> 1.0.5
| | |-- <FS> 1.0
| | |-- <SPI> 1.0
|-- <PubSubClient> 2.8.0
|-- <Adafruit ST7735 and ST7789 Library> 1.6.0
| | |-- <Adafruit GFX Library> 1.10.4
| | | | |-- <SPI> 1.0
| | | | |-- <Adafruit BusIO> 1.7.1
| | | | | | |-- <Wire> 1.0.1
| | | | | | |-- <SPI> 1.0
| | | | |-- <Wire> 1.0.1
| | |-- <SPI> 1.0
|-- <Adafruit BusIO> 1.7.1
| | |-- <Wire> 1.0.1
| | |-- <SPI> 1.0
|-- <Adafruit GFX Library> 1.10.4
| | |-- <SPI> 1.0
| | |-- <Adafruit BusIO> 1.7.1
| | | | |-- <Wire> 1.0.1
| | | | |-- <SPI> 1.0
| | |-- <Wire> 1.0.1
|-- <Ch376msc> 1.4.4
| |-- <SPI> 1.0
|-- <FS> 1.0
|-- <SPI> 1.0
|-- <ArduinoOTA> 1.0
| | |-- <Update> 1.0
| | |-- <WiFi> 1.0
| | |-- <ESPmDNS> 1.0
| | | | |-- <WiFi> 1.0
|-- <ESPmDNS> 1.0
| |-- <WiFi> 1.0
|-- <Update> 1.0
|-- <WiFi> 1.0
Building in release mode
Compiling .pio\build\esp32doit-devkit-v1\src\main.cpp.o Generating partitions .pio\build\esp32doit-devkit-v1\partitions.bin Compiling .pio\build\esp32doit-devkit-v1\lib674\Wire\Wire.cpp.o Compiling .pio\build\esp32doit-devkit-v1\lib5dd\FS\FS.cpp.o Compiling .pio\build\esp32doit-devkit-v1\lib5dd\FS\vfs_api.cpp.o Compiling .pio\build\esp32doit-devkit-v1\libb0c\SPI\SPI.cpp.o Compiling .pio\build\esp32doit-devkit-v1\lib4d3\SD\SD.cpp.o Compiling .pio\build\esp32doit-devkit-v1\lib4d3\SD\sd_diskio.cpp.o
Archiving .pio\build\esp32doit-devkit-v1\libb0c\libSPI.a
Compiling .pio\build\esp32doit-devkit-v1\lib4d3\SD\sd_diskio_crc.c.o
Compiling .pio\build\esp32doit-devkit-v1\lib19e\PubSubClient\PubSubClient.cpp.o
Compiling .pio\build\esp32doit-devkit-v1\lib297\Adafruit BusIO\Adafruit_BusIO_Register.cpp.o Archiving .pio\build\esp32doit-devkit-v1\lib674\libWire.a
Compiling .pio\build\esp32doit-devkit-v1\lib297\Adafruit BusIO\Adafruit_I2CDevice.cpp.o

Compiling .pio\build\esp32doit-devkit-v1\lib297\Adafruit BusIO\Adafruit_SPIDevice.cpp.o Archiving .pio\build\esp32doit-devkit-v1\lib5dd\libFS.a
Compiling .pio\build\esp32doit-devkit-v1\lib0ed\Adafruit GFX Library\Adafruit_GFX.cpp.o Compiling .pio\build\esp32doit-devkit-v1\lib0ed\Adafruit GFX Library\Adafruit_GrayOLED.cpp.o Archiving .pio\build\esp32doit-devkit-v1\lib4d3\libSD.a
Compiling .pio\build\esp32doit-devkit-v1\lib0ed\Adafruit GFX Library\Adafruit_SPITFT.cpp.o Compiling .pio\build\esp32doit-devkit-v1\lib0ed\Adafruit GFX Library\glcdfont.c.o Archiving .pio\build\esp32doit-devkit-v1\lib19e\libPubSubClient.a
Compiling .pio\build\esp32doit-devkit-v1\lib81f\Adafruit ST7735 and ST7789 Library\Adafruit_ST7735.cpp.o
Compiling .pio\build\esp32doit-devkit-v1\lib81f\Adafruit ST7735 and ST7789 Library\Adafruit_ST7789.cpp.o
Compiling .pio\build\esp32doit-devkit-v1\lib81f\Adafruit ST7735 and ST7789 Library\Adafruit_ST77xx.cpp.o
Archiving .pio\build\esp32doit-devkit-v1\lib297\libAdafruit BusIO.a Compiling .pio\build\esp32doit-devkit-v1\libb1e\Ch376msc\API.cpp.o Compiling .pio\build\esp32doit-devkit-v1\libb1e\Ch376msc\Ch376msc.cpp.o Compiling .pio\build\esp32doit-devkit-v1\libb1e\Ch376msc\Comm.cpp.o Compiling .pio\build\esp32doit-devkit-v1\libb1e\Ch376msc\Read.cpp.o
Compiling .pio\build\esp32doit-devkit-v1\libb1e\Ch376msc\SetGet.cpp.o
Compiling .pio\build\esp32doit-devkit-v1\libb1e\Ch376msc\Write.cpp.o
Archiving .pio\build\esp32doit-devkit-v1\lib81f\libAdafruit ST7735 and ST7789 Library.a Compiling .pio\build\esp32doit-devkit-v1\lib1b7\Update\HttpsOTAUpdate.cpp.o
Archiving .pio\build\esp32doit-devkit-v1\lib0ed\libAdafruit GFX Library.a
Compiling .pio\build\esp32doit-devkit-v1\lib1b7\Update\Updater.cpp.o
Compiling .pio\build\esp32doit-devkit-v1\lib160\WiFi\ETH.cpp.o
Compiling .pio\build\esp32doit-devkit-v1\lib160\WiFi\WiFi.cpp.o Compiling .pio\build\esp32doit-devkit-v1\lib160\WiFi\WiFiAP.cpp.o Compiling .pio\build\esp32doit-devkit-v1\lib160\WiFi\WiFiClient.cpp.o Compiling .pio\build\esp32doit-devkit-v1\lib160\WiFi\WiFiGeneric.cpp.o Archiving .pio\build\esp32doit-devkit-v1\libb1e\libCh376msc.a Compiling .pio\build\esp32doit-devkit-v1\lib160\WiFi\WiFiMulti.cpp.o Compiling .pio\build\esp32doit-devkit-v1\lib160\WiFi\WiFiSTA.cpp.o Archiving .pio\build\esp32doit-devkit-v1\lib1b7\libUpdate.a Compiling .pio\build\esp32doit-devkit-v1\lib160\WiFi\WiFiScan.cpp.o Compiling .pio\build\esp32doit-devkit-v1\lib160\WiFi\WiFiServer.cpp.o Compiling .pio\build\esp32doit-devkit-v1\lib160\WiFi\WiFiUdp.cpp.o Compiling .pio\build\esp32doit-devkit-v1\libbf8\ESPmDNS\ESPmDNS.cpp.o Compiling .pio\build\esp32doit-devkit-v1\lib8b7\ArduinoOTA\ArduinoOTA.cpp.o Archiving .pio\build\esp32doit-devkit-v1\libFrameworkArduinoVariant.a
Compiling .pio\build\esp32doit-devkit-v1\FrameworkArduino\Esp.cpp.o
Compiling .pio\build\esp32doit-devkit-v1\FrameworkArduino\FunctionalInterrupt.cpp.o Compiling .pio\build\esp32doit-devkit-v1\FrameworkArduino\HardwareSerial.cpp.o Compiling .pio\build\esp32doit-devkit-v1\FrameworkArduino\IPAddress.cpp.o Compiling .pio\build\esp32doit-devkit-v1\FrameworkArduino\IPv6Address.cpp.o Archiving .pio\build\esp32doit-devkit-v1\lib160\libWiFi.a
Compiling .pio\build\esp32doit-devkit-v1\FrameworkArduino\MD5Builder.cpp.o Compiling .pio\build\esp32doit-devkit-v1\FrameworkArduino\Print.cpp.o Archiving .pio\build\esp32doit-devkit-v1\libbf8\libESPmDNS.a
Compiling .pio\build\esp32doit-devkit-v1\FrameworkArduino\Stream.cpp.o Compiling .pio\build\esp32doit-devkit-v1\FrameworkArduino\StreamString.cpp.o Compiling .pio\build\esp32doit-devkit-v1\FrameworkArduino\WMath.cpp.o Archiving .pio\build\esp32doit-devkit-v1\lib8b7\libArduinoOTA.a
Compiling .pio\build\esp32doit-devkit-v1\FrameworkArduino\WString.cpp.o Compiling .pio\build\esp32doit-devkit-v1\FrameworkArduino\base64.cpp.o Compiling .pio\build\esp32doit-devkit-v1\FrameworkArduino\cbuf.cpp.o Compiling .pio\build\esp32doit-devkit-v1\FrameworkArduino\esp32-hal-adc.c.o Compiling .pio\build\esp32doit-devkit-v1\FrameworkArduino\esp32-hal-bt.c.o Compiling .pio\build\esp32doit-devkit-v1\FrameworkArduino\esp32-hal-cpu.c.o Compiling .pio\build\esp32doit-devkit-v1\FrameworkArduino\esp32-hal-dac.c.o Compiling .pio\build\esp32doit-devkit-v1\FrameworkArduino\esp32-hal-gpio.c.o Compiling .pio\build\esp32doit-devkit-v1\FrameworkArduino\esp32-hal-i2c.c.o Compiling .pio\build\esp32doit-devkit-v1\FrameworkArduino\esp32-hal-ledc.c.o Compiling .pio\build\esp32doit-devkit-v1\FrameworkArduino\esp32-hal-log.c.o Compiling .pio\build\esp32doit-devkit-v1\FrameworkArduino\esp32-hal-matrix.c.o Compiling .pio\build\esp32doit-devkit-v1\FrameworkArduino\esp32-hal-misc.c.o Compiling .pio\build\esp32doit-devkit-v1\FrameworkArduino\esp32-hal-psram.c.o Compiling .pio\build\esp32doit-devkit-v1\FrameworkArduino\esp32-hal-rmt.c.o Compiling .pio\build\esp32doit-devkit-v1\FrameworkArduino\esp32-hal-sigmadelta.c.o Compiling .pio\build\esp32doit-devkit-v1\FrameworkArduino\esp32-hal-spi.c.o Compiling .pio\build\esp32doit-devkit-v1\FrameworkArduino\esp32-hal-time.c.o Compiling .pio\build\esp32doit-devkit-v1\FrameworkArduino\esp32-hal-timer.c.o Compiling .pio\build\esp32doit-devkit-v1\FrameworkArduino\esp32-hal-touch.c.o Compiling .pio\build\esp32doit-devkit-v1\FrameworkArduino\esp32-hal-uart.c.o Compiling .pio\build\esp32doit-devkit-v1\FrameworkArduino\libb64\cdecode.c.o

C:\users\hp\.platformio\packages\framework-arduinoespressif32\cores\esp32\esp32-hal-spi.c: In function 'spiTransferBytesNL': C:\users\hp\.platformio\packages\framework-arduinoespressif32\cores\esp32\esp32-hal-spi.c:922:39: warning: initialization from incompatible pointer type [-Wincompatible-pointer-types]
uint8_t * last_out8 = &result[c_longs-1]; ^
C:\users\hp\.platformio\packages\framework-arduinoespressif32\cores\esp32\esp32-hal-spi.c:923:40: warning: initialization from incompatible pointer type [-Wincompatible-pointer-types]
uint8_t * last_data8 = &last_data; ^
Compiling .pio\build\esp32doit-devkit-v1\FrameworkArduino\libb64\cencode.c.o Compiling .pio\build\esp32doit-devkit-v1\FrameworkArduino\main.cpp.o Compiling .pio\build\esp32doit-devkit-v1\FrameworkArduino\stdlib_noniso.c.o Compiling .pio\build\esp32doit-devkit-v1\FrameworkArduino\wiring_pulse.c.o Compiling .pio\build\esp32doit-devkit-v1\FrameworkArduino\wiring_shift.c.o Archiving .pio\build\esp32doit-devkit-v1\libFrameworkArduino.a
Linking .pio\build\esp32doit-devkit-v1\firmware.elf
Retrieving maximum program size .pio\build\esp32doit-devkit-v1\firmware.elf Checking size .pio\build\esp32doit-devkit-v1\firmware.elf
Advanced Memory Usage is available via "PlatformIO Home > Project Inspect"
RAM: | [== | ] 18.6% (used 61092 bytes from 327680 bytes)
Flash: [======= | ] 66.5% (used 871018 bytes from 1310720 bytes)
Building .pio\build\esp32doit-devkit-v1\firmware.bin
esptool.py v3.1
Merged 1 ELF section
Configuring upload protocol...
AVAILABLE: esp-prog, espota, esptool, iot-bus-jtag, jlink, minimodule, olimex-arm-usb-ocd, olimex-arm-usb-ocd-h, olimex-arm-usb-tiny-h, olimex-jtag-tiny, tumpa
CURRENT: upload_protocol = esptool
Looking for upload port...
Use manually specified: COM4
Uploading .pio\build\esp32doit-devkit-v1\firmware.bin esptool.py v3.1
Serial port COM4
Connecting....
Chip is ESP32-D0WDQ6 (revision 1)
Features: WiFi, BT, Dual Core, 240MHz, VRef calibration in efuse, Coding Scheme None Crystal is 40MHz
MAC: 24:0a:c4:ae:84:48
Uploading stub...
Running stub...
Stub running...
Changing baud rate to 460800 Changed.
Configuring flash size...
Auto-detected Flash size: 4MB
Flash will be erased from 0x00001000 to 0x00005fff... Flash will be erased from 0x00008000 to 0x00008fff... Flash will be erased from 0x0000e000 to 0x0000ffff... Flash will be erased from 0x00010000 to 0x000e4fff...
Compressed 17104 bytes to 11191...
Writing at 0x00001000... (100 %)
Wrote 17104 bytes (11191 compressed) at 0x00001000 in 0.5 seconds (effective 260.5 kbit/s)... Hash of data verified.
Compressed 3072 bytes to 128...
Writing at 0x00008000... (100 %)
Wrote 3072 bytes (128 compressed) at 0x00008000 in 0.1 seconds (effective 365.0 kbit/s)... Hash of data verified.
Compressed 8192 bytes to 47...
Writing at 0x0000e000... (100 %)
Wrote 8192 bytes (47 compressed) at 0x0000e000 in 0.1 seconds (effective 552.0 kbit/s)... Hash of data verified.
Compressed 871120 bytes to 494819...
Writing at 0x0001c678... (6 %)
Writing at 0x00028a04... (9 %) Writing at 0x0003528e... (12 %) Writing at 0x0004b4fe... (16 %) Writing at 0x00050f18... (19 %) Writing at 0x00056b08... (22 %) Writing at 0x0005c483... (25 %) Writing at 0x00061f04... (29 %) Writing at 0x0006715a... (32 %) . . .

Writing at 0x000d7581... (93 %)
Writing at 0x000dd645... (96 %)
Writing at 0x000e3377... (100 %)
Wrote 871120 bytes (494819 compressed) at 0x00010000 in 12.0 seconds (effective 580.1 kbit/s)... Hash of data verified.

Leaving...
Hard resetting via RTS pin...
======================================= [SUCCESS] Took 42.10 seconds =======================================
Terminal will be reused by tasks, press any key to close it.

Debug (serial 115200 Baud) output.
This is an example of the debug output.

ets Jun 8 2016 00:22:57
rst:0x1 (POWERON_RESET),boot:0x13 (SPI_FAST_FLASH_BOOT)
configsip: 0, SPIWP:0xee
clk_drv:0x00,q_drv:0x00,d_drv:0x00,cs0_drv:0x00,hd_drv:0x00,wp_drv:0x00 mode:DIO, clock div:2
load:0x3fff0018,len:4
load:0x3fff001c,len:1044
load:0x40078000,len:10124
load:0x40080400,len:5828
entry 0x400806a8

D: Starting ESP32-radio running on CPU 1 at 240 MHz. Version Mon, 28 Jun 2021 12:40:00 GMT. Free memory 302164 D: Display type is BLUETFT
D: Partition nvs found, 20480 bytes
D: Read 51 keys from NVS
D: pin_ir set to 35
D: pin_enc_clk set to -1
D: pin_enc_dt set to -1
D: pin_enc_sw set to -1
D: pin_tft_cs set to 15
D: pin_tft_dc set to 2
D: pin_tft_scl set to 13
D: pin_tft_sda set to 14
D: pin_tft_bl set to -1
D: pin_tft_blx set to -1
D: pin_sd_cs set to 21
D: pin_ch376_cs set to 32
D: pin_ch376_int set to 33 D: pin_vs_cs set to 5
D: pin_vs_dcs set to 16
D: pin_vs_dreq set to 4
D: pin_shutdown set to -1
D: pin_shutdownx set to -1 D: pin_spi_sck set to 18
D: pin_spi_miso set to 19
D: pin_spi_mosi set to 23
D: GPIO0 is HIGH
D: GPIO2 is LOW, probably no PULL-UP D: GPIO4 is HIGH
D: GPIO5 is HIGH
D: GPIO12 is HIGH
D: GPIO13 is HIGH
D: GPIO14 is HIGH
D: GPIO15 is HIGH
D: GPIO16 is HIGH
D: GPIO17 is HIGH
D: GPIO18 is HIGH
D: GPIO19 is HIGH
D: GPIO21 is HIGH
D: GPIO22 is HIGH
D: GPIO23 is HIGH
D: GPIO25 is HIGH
D: GPIO26 is HIGH
D: GPIO27 is HIGH
D: GPIO32 is HIGH
D: GPIO33 is HIGH
D: GPIO34 is LOW, probably no PULL-UP D: GPIO35 is LOW, probably no PULL-UP D: GPIO39 is LOW, probably no PULL-UP
D: gpio_00 will execute uppreset = 1
D: gpio_12 will execute upvolume = 2
D: gpio_34 will execute station = icecast.omroep.nl:80/radio1-bb-mp3 D: Enable pin 35 for IR
D: Start display
D: Create list with acceptable WiFi networks
D: Added ADSL-11 to list of networks
D: Added SSID to list of networks
D: End adding networks
D: Scan Networks
D: Scan completed
D: Number of available networks: 7
D: 1 - ADSL-11 | Signal: -38 dBm, Encryption WPA2_PSK, Acceptable
D: 2 - ESP_A43E4F | Signal: -56 dBm, Encryption OPEN,
D: 3 - NETGEAR-11 | Signal: -64 dBm, Encryption WPA2_PSK,
D: 4 - Ziggo8571367 | Signal: -81 dBm, Encryption WPA2_PSK,
D: 5 - ADSL-11 | Signal: -81 dBm, Encryption WPA2_PSK, Acceptable
D: 6 - Ziggo | Signal: -83 dBm, Encryption ????,
D: 7 - ADSL-11 | Signal: -89 dBm, Encryption WPA_WPA2_PSK, Acceptable
D: End of list
D: Command: clk_dst with parameter 1
D: Command: clk_offset with parameter 1
D: Command: clk_server with parameter pool.ntp.org D: Command: gpio_00 with parameter uppreset = 1

D: Command: gpio_12 with parameter upvolume = 2
D: Command: gpio_13 with parameter downvolume = 2
D: Command: gpio_34 with parameter station = icecast.omroep.nl:80/radio1-bb-mp3 D: Command: ir_40bf with parameter upvolume = 2
D: Command: ir_c03f with parameter downvolume = 2
D: Command: lstmods with parameter Sun, 25 Apr 2021 12:45:21 GMT
D: Command: mqqprefix with parameter none
D: Command: mqttbroker with parameter none
D: Command: mqttpasswd with parameter *******
D: Command: mqttport with parameter 1883
D: Command: mqttuser with parameter none
D: Command: pin_ch376_cs with parameter 32 D: Command: pin_ch376_int with parameter 33 D: Command: pin_ir with parameter 35
D: Command: pin_sd_cs with parameter 21
D: Command: pin_tft_cs with parameter 15 D: Command: pin_tft_dc with parameter 2 D: Command: pin_tft_scl with parameter 13 D: Command: pin_tft_sda with parameter 14 D: Command: pin_vs_cs with parameter 5 D: Command: pin_vs_dcs with parameter 16
D: Command: pin_vs_dreq with parameter 4
D: Command: preset with parameter 16
D: Command: preset_000 with parameter 109.206.96.34:8100
D: Command: preset_001 with parameter airspectrum.cdnstream1.com:8114/1648_128 D: Command: preset_002 with parameter airspectrum.cdnstream1.com:8142/1303_128 D: Command: preset_003 with parameter airspectrum.cdnstream1.com:8000/1261_192 D: Command: preset_004 with parameter airspectrum.cdnstream1.com:8008/1604_128 D: Command: preset_005 with parameter us1.internet-radio.com:8105
D: Command: preset_006 with parameter icecast.omroep.nl:80/radio1-bb-mp3
D: Command: preset_007 with parameter icecast.omroep.nl:80/radio5-bb-mp3
D: Command: preset_008 with parameter icecast.omroep.nl:80/radio2-bb-mp3
D: Command: preset_009 with parameter streaming.hotmix-radio.net/hotmixradio-90-128.mp3
D: Command: preset_010 with parameter streams.radiobob.de/bob-80srock/mp3-192/streams.radiobob.de
D: Command: preset_011 with parameter wdr-edge-101d-dus-dtag-cdn.cast.addradio.de/wdr/diemaus/live/mp3/high D: Command: preset_012 with parameter stream.laut.fm/kinderlieder-123
D: Command: preset_013 with parameter bbcwssc.ic.llnwd.net/stream/bbcwssc_mp1_ws-eieuk
D: Command: preset_014 with parameter metafiles.gl-systemhaus.de/hr/hr1_2.m3u
D: Command: preset_015 with parameter cbcmp3.ic.llnwd.net/stream/cbcmp3_M-7QMTL0_MTL D: Command: preset_016 with parameter streamer.radio.co/sa7bf61271/listen
D: Command: toneha with parameter 5
D: Command: tonehf with parameter 1
D: Command: tonela with parameter 8
D: Command: tonelf with parameter 11
D: Command: volume with parameter 96
D: Slow SPI, Testing VS1053 read/write registers...
D: Fast SPI, Testing VS1053 read/write registers again... D: endFillByte is 0
D: Connect to WiFi
D: Connected to ADSL-11
D: IP = 192.168.2.25
D: Start server for commands
D: Network found. Starting mqtt and OTA D: MDNS responder started
D: Rotary encoder is disabled (-1/-1/-1) D: Sync TOD
D: Sync TOD, new value is 09:02:23
D: STOP requested
D: New preset/file requested (16/0) from streamer.radio.co/sa7bf61271/listen D: New station request
D: Connect to new host streamer.radio.co/sa7bf61271/listen
D: Connect to streamer.radio.co on port 80, extension /sa7bf61271/listen
D: Song stopped correctly after 0 msec
D: Connected to server
D: Switch to HEADER
D: Headerline: Content-Type: audio/mpeg
D: audio/mpeg seen.
D: Headerline: icy-br:192
D: Headerline: ice-audio-info: channels=2;samplerate=44100;bitrate=192 D: Headerline: icy-br:192
D: Headerline: icy-name:JB&#39;s Rock N Roll - DooWop Jukebox
D: Headerline: icy-pub:1
D: Headerline: icy-url:http://www.jbs-rocknroll-doowop-jukebox.com D: Headerline: Server: streamer-gravelines.radio.co
D: Headerline: Cache-Control: no-cache, no-store
D: Headerline: Access-Control-Allow-Origin: *
D: Headerline: Access-Control-Allow-Headers: Origin, Accept, X-Requested-With, Content-Type D: l-Allow-Headers: Origin, Accept, X-Requested-With, Content-Type seen.
D: Headerline: Access-Control-Allow-Methods: GET, OPTIONS, HEAD
D: Headerline: Connection: Close
D: Headerline: Expires: Mon, 26 Jul 1997 05:00:00 GMT
D: Headerline: icy-metaint:16000
D: Switch to DATA, bitrate is 192, metaint is 16000 D: Duration mp3loop 79
D: Metadata block 48 bytes
D: Streamtitle found, 45 bytes
D: StreamTitle='The Passions - I Only Want You';

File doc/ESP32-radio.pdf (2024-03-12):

# ESP32-radio V2.0

This document describes the realization of an Internet radio based on an ESP32 WiFi module.
For the ESP32 an Internet radio was build in 2017 using a VS1053 mp3 decoder. Now the software is updated to support I2S output. The latest version also supports SPDIF (Toslink) output.
A 1.8 TFT color display to give some information about the radio station that’s playing. Other types of display are also supported, including NEXTION.

In the simplest configuration, you can build an Internet radio with only 2 components.

## 1 Features:

- Can connect to thousands of Internet radio stations that broadcast MP3 or AAC audio streams.
- Output to VS1053, SPDIF, I2S¹⁾
- MP3 playlists supported.
- Uses a minimal number of components.
- Has a preset list of a maximum of 100 favorite radio stations as preferences in flash.
- Can be controlled by a tablet or other device through the built-in webserver.
- Can be controlled by MQTT commands. Status info is published by using MQTT.
- Can be controlled by commands on the serial input.
- Can be controlled by IR.
- Can be controlled by rotary switch encoder.
- Up to 14 input ports can be configured as control buttons like volume, skip to the next/previous/first/favorite preset station.
- I/O pins for TFT, VS1053, I2S, IR and rotary encoder can be configured in preferences.
- The strongest available WiFi network is automatically selected. Passwords are kept as preferences in flash. Heavily commented source code, easy to add extra functionality.
- Debug information through serial output.
- 2

nd processor is used for smooth playback.
- Update of software over WiFi (OTA) through PlatformIO IDE.
- Parameters like WiFi information and presets can be edited in the web interface.
- Preset, volume, bass and treble settings are saved in preferences.
- Displays time of day on TFT.
- Optional displays remaining battery charge.
- Bit-rates up to 320 kbps.
- Control of TFT back-light.
- PCB available through PCBWay.
- 3D printable box available.
1.1 Restrictions for I2S/SPDIF and internal DAC output.
1.1.1 | Restrictions for SPDIF output.

An external amplifier with SPDIF (Toslink) input is required. For headphone output only, you may use a simple spdif to analog converter.
1.1.2 | Restrictions for I2S output.

There is no tone control for I2S output. You have to use analog controls on the external amplifier.
1.1.3 | Restrictions for DAC output.

There is no tone control for internal DAC . You have to use analog controls on the external amplifier. The internal DAC uses only 8 bits for the digital to analog conversion. This effects the sound quality.

1 See restrictions for I2S output ESP32 Radio V2 -- page 1

1.2 Bluetooth output.

If I2S output is enabled and you are using a PCM5102 converter, you can connect a “Bluetooth 5.0 4.2 Receiver Transmitter”. See here. (https://www.aliexpress.com/item/4000305451750.html) Due to technical limits, it is not possible to use the internal ESP bluetooth.

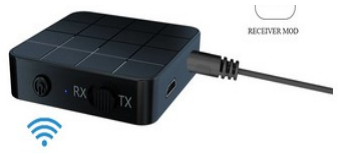
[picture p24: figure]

## 2 Software:

The software for the radio is supplied as a PlatformIO project using the Arduino platform. The following libraries are used:

- Wire - knolleary/PubSubClient@^2.8 - adafruit/Adafruit BusIO@^1.9.3 - adafruit/Adafruit GFX Library@^1.10.4 - adafruit/Adafruit ILI9341@^1.5.9 - adafruit/Adafruit ST7735 and ST7789 Library@^1.7.5 - me-no-dev/AsyncTCP@1.1.1 - me-no-dev/ESP Async WebServer@^1.2.3 - yveaux/AC101@^0.0.1 - djuseeq/Ch376msc @ ^1.4.4knolleary/PubSubClient@^2.8.0

The data directory of the project contains the files for the web interface: index.html, favicon.ico, style.css, search.html, config.html, defaultprefs.txt, (no)mp3play.html and about.html.
The directory structure of the project is developed for PlatformIO. If you want to build the project using the Arduino IDE, you should follow the instructions in chapter 17 of this document.

2.1 Configuration in config.h.

In order tor enable or disable various features the config.h file can be edited before compiling.
You can set a fixed WiFi network to simplify the initial setup, define the MP3 decoder, the display and the type of the rotary encoder.

### 2.2 Preferences

Preferences for ESP32-Radio are kept in Flash memory (NVS).
You may change the contents of NVS with the “Config”-button in the web interface. An example of the

### contents is:

bat0 | = 2178 | # ADC for 0% battery capacity left
bat100 = 3256 | # ACD for 100% battery capacity
clk_dst = 1 | # Offset during daylight saving time (hours)
clk_offset = 1 | # Offset with respect to UTC in hours
clk_server = pool.ntp.org | # Time server to be used
gpio_00 = uppreset = 1
gpio_12 = upvolume = 2
gpio_13 = downvolume = 2
gpio_14 = stop
gpio_17 = resume
ir_40BF = upvolume = 2
ir_C03F = downvolume = 2
mqttbroker = none
mqttpasswd = none
mqttport = 1883
mqttprefix = none
mqttuser = none
pin_i2s_bck = 27 | # I2S (UDA1334, PCM5102)
pin_i2s_din = 25
pin_i2s_lck = 26
pin_i2s_spdif = 15 | # SP/DIF output
preset = 9
preset_00 = 109.206.96.34:8100 | # 0 - NAXI LOVE RADIO, Belgrade, Serbia
preset_01 = airspectrum.cdnstream1.com:8114/1648_128 # 1 - Easy Hits Florida 128k
preset_02 = us2.internet-radio.com:8050 | # 2 - CLASSIC ROCK MIAMI 256k
preset_03 = airspectrum.cdnstream1.com:8000/1261_192 # 3 - Magic Oldies Florida
preset_04 = airspectrum.cdnstream1.com:8008/1604_128 # 4 - Magic 60s Florida 60s Classic Rock
preset_05 = us1.internet-radio.com:8105 | # 5 - Classic Rock Florida - SHE Radio
preset_06 = icecast.omroep.nl:80/radio1-bb-mp3 | # 6 - Radio 1, NL, 192k
preset_07 = 205.164.62.15:10032 | # 7 - 1.FM - GAIA, 64k
preset_08 = www.doowopradio.com:8000 | # 8 - Doo-Wop Radio, 96k
preset_09 = server-27.stream-server.nl:8192/stream | # 9 - 192 Radio Nederland, 320k
toneha = 0
tonehf = 0
tonela = 0
tonelf = 0
volume = 42
wifi_00 = ADSL-11/DEADC0DE11
wifi_01 = SSID2/PASSWD2

Note that the size of the NVS is limited to 20 kB.
Lines starting with “#” are comment lines and are ignored. Comments per line (after “#”) will also be ignored, except for the “preset_” lines. The comments on the “preset_” lines are used to identify the presets in the web interface.
The maximum line length is 150 characters.
Note that the preset numbers ranges from 000 to 199. The range can be extended by the definition of MAXPRESETS. Note that there is also a limit on the NVS space. If the highest numbered station is reached, the next station will be 00 again. URLs with mp3 files or mp3 playlists (.m3u) are allowed.

Preferences in the form "pin_xxxx" specify pin numbers for the various interfaces. For a FEATERBOARD you have to change some settings, especially for the display. The pins for SPI default to SCK=18, MISO=19 and MOSI=23, but they may be configured by “pin_spi_xxx” commands.

### The complete list of configurable interface pins is:

Configuration name | Function
pin_ir | Pin for IR sensor (VS1838B)
pin_enc_clk | Rotary encoder CLK pin
pin_enc_dt | Rotary encoder DT pin
pin_enc_up | ZIPPY B5 side switch up
pin_enc_dwn | ZIPPY B5 side switch down
pin_enc_sw | Rotary encoder switch down
pin_tft_cs | Display SPI version CS pin
pin_tft_dc | Display SPI version DC pin
pin_tft_scl | Display I2C version SCL. For OLED, LCD1602, LCD2004
pin_tft_sda | Display I2C version SDA For OLED, LCD1602, LCD2004
pin_tft_bl | Display back-light. The BL is disabled after some time if there is no activity. This helps to reduce power when running on batteries.
pin_tft_blx | Display back-light (inversed logic)
pin_nxt_rx | NEXTION (input from NEXTION)
pin_nxt_tx | NEXTION (output to NEXTION)
pin_sd_cs | SD card select
pin_sd_detect | SD detect inserted card (LOW is inserted)
pin_vs_cs | VS1053 CS pin
pin_vs_dcs | VS1053 DCS pin
pin_vs_dreq | VS1053 DREQ pin
pin_shutdown | Amplifier shutdown pin. Pin will be set if the radio is not playing or the volume is set to zero. This output-pin can be used to shut down the amplifier.
pin_shutdownx | Amplifier shutdown pin (inversed logic)
pin_i2s_bck | I2S BCK signal for I2S devices
pin_i2s_lck | I2S L(R)CK signal for I2S devices
pin_i2s_din | I2S DIN signal for I2S devices
pin_i2s_spdif | SP/DIF signal
pin_spi_sck | SPI bus SCK pin, default pin 18
pin_spi_miso | SPI bus MISO pin, default pin 19
pin_spi_mosi | SPI bus MOSI pin, default pin 16
pin_eth_mdc | For boards with Ethernet, MDC signal, default pin 23
pin_eth_mdio | For boards with Ethernet, MDIO signal, default pin 18
pin_eth_power | For boards with Ethernet, POWER signal, default pin 16

The "gpio_" lines specify input pins and the command that is executed if the input pin goes from HIGH to LOW.

The "touch_" lines specify the GPIO input pins for this signal and the command that is executed if the input pin is activated.

The "ir_XXXX" lines specify IR-codes and the command that is executed if the IR-code is received. The code part is a hexadecimal number in upper-case characters.

The "clk_" lines are used for the display of the current time on the TFT. Please change the values for your timezone. The values in the example are valid for the Netherlands.

The “bat0” and “bat100” lines are for displaying the remaining battery capacity on the display. See the details at the paragraph with optional features.

The preferences can be edited in the web interface. Changes will in some cases be effective after restart of the Esp-radio. If the list of preferences is empty (first start), you may use the default button. The list will show some default values which can be edited.

2.3 Using Winamp to find out the correct preset line for a station.

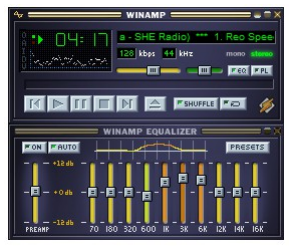
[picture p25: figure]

Press Alt-3 in the main window (left picture). You will see info for the playing station (right picture).
The top line (with “http”) will contain the information for the preset, in this example:
“us1.internet-radio.com:8105”. Remove the “http...”-part. The complete line for this station in the preferences would be:
preset_05 = us1.internet-radio.com:8105 | # 5 - Classic Rock Florida - SHE Radio

## Optional features:

2.3.1 | Digital control through input pins:
Normally the radio is controlled by the web interface. However, free digital inputs (GPIO) may be connected to buttons to control the radio. Their function can be programmed using the web interface.

You can assign commands to the digital inputs by adding lines in the configuration (Webinterface, "Config"

### page). Examples:

| gpio_00 = uppreset = 1 gpio_12 = upvolume = 2 gpio_13 = downvolume = 2 gpio_21 = station = icecast.omroep.nl:80/radio1-bb-mp3

In this example the ESP32-Radio will execute the command "uppreset=1" if GPIO0 will go from HIGH to LOW. The commands are equal to the commands that are handled by the serial input or by the MQTT interface.
The same format can be used for the touch-inputs:
| touch_04 = uppreset = 1 touch_13 = upvolume = 2

In this example the ESP32-Radio will execute the command "uppreset=1" if TOUCH0 (GPIO04) will be activated. The commands are equal to the commands that are handled by the serial input or by the MQTT interface.
2.3.2 | IR Interface.

### The radio can be controlled by an IR remote control like this:

To use this interface, the "out" pin of a VS1838B receiver must be connected to a GPIO pin of the ESP32:

Add the assigned GPIO pin to the preferences through the config page in the web interface. Example:
pin_ir = 35 | # GPIO Pin number for IR receiver VS1838B

VCC is connected to 3.3 Volt. A 220 µF capacitor should be connected between VCC and GND.
The software will read the raw code of the IR transmitter, making it possible to use virtually any remote control to be used. I tested it with the 21 button remote as well as with an LG TV remote.
To assign functions to the buttons, watch the debug log output while pressing a button. For example, press the

### +volume button. You will see something like:

D: IR code 807F received, but not found in preferences!

### Now add the command:

ir_807F = upvolume = 2
to the preferences in the config page of the web interface. Likewise you can assign functions to all buttons, for

### example:

ir_8A31 = uppreset = 1
ir_719A = station = us1.internet-radio.com:8105
ir_1F6B = mute
ir_661A = sleep

2.3.3 | | Display remaining battery capacity:

The remaining battery capacity is computed by measuring the battery voltage on ping GPIO36 (ADC0).
The battery voltage must be supplied to ADC0 through a resistor voltage divider. The maximum voltage fort his input is 1.0 volt. I used 100 kΩ and 22 kΩ fort his purpose.
Furthermore you need to specify ADC value for both the full and the empty voltages. These values must be in the preferences like:
bat0 | = 2178 | # ADC for 0% battery capacity left
bat100 = 2690 | # ACD for 100% battery capacity
To calibrate the settings you may use the “TEST” command in the serial monitor. This will display the current reading of the ADC0 pin. Do this for a fully charge battery and for an (almost) empty one.
Note that it will take about 6 seconds before the reading is stable. This is a result of a filter in the measurement of the ADC.

The remaining capacity is displayed as a green/red bar near the top of the display.

## 3 Hardware:

### The radio is built with the following widely available hardware:

- An ESP-32 module. This is basically an ESP32 on a small print. I used a DOIT ESP32 Development Board. See figure 1 below. The ESP32 is running on 160 MHz. On Aliexpress: this. (https://www.aliexpress.com/item/Elecrow-Official-DOIT-ESP32S-esp32-Development-Board-WiFi-Bluetooth-Dual-Core-CPU-Low-Power-Consumption-DIY/32804562215.html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)
- An optional VS1053 module. See figure 2.
- An optional PCM5102, 1334A or similar I2S to analog module. See figure 14.
- An optional SP/DIF transmitter. See figure 15.
- A 1.8 inch color TFT display 160x128. Optional, see figure 3 and 4. On Aliexpress: this (https://www.aliexpress.com/item/1-8-Serial-128X160-SPI-TFT-LCD-Module-Display-PCB-Adapter-Power-IC-SD-Socket-R179/32602828489.html) or this. (https://www.aliexpress.com/item/Smart-Electronics-1-8-Inch-128-160-Serial-SPI-TFT-LCD-Module-Display-PCB-Adapter-Power/32597366825.html)
- A 1.44 inch color TFT display 128x128. Optional, see figure 9. On Aliexpress: this. (https://www.aliexpress.com/item/Replace-5110-LCD-1-44-Red-Serial-128X128-SPI-Color-TFT-LCD-Display-Module/32852197696.html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)
- An OLED 128x64 display. Optional, see figure 7. On Aliexpress: this. (https://www.aliexpress.com/item/1pcs-SAMIORE-ROBOT-0-96-white-blue-yellow-0-96-inch-128X64-OLED-Display-Module-0/32640136921.html)
- An 1602 LCD display with I2C backpack. Optional, see figure 8.
- An 2004 LCD display with I2C backpack. Optional, see figure 13.
- A NEXTION display. Optional, see figure 10. Tested with a NX3224T024_011.
- Two small speakers.
- A Class D stereo amplifier to drive the speakers. Best quality if powered by a separate power source.
- A rotary encoder switch. Optional, see figure 5.
- A ZIPPY B5 side switch. Optional. This switch may replace the rotary decoder. Define “ZIPPYB5” in config.h and define “pin_enc_dwn” and “pin_enc_sw” in the config page of the webinterface. See figure 12.
- A IR receiver. Optional, see figure 6.
- Two audio transformers. Optional, see figure 11.
Fig. 1 | Fig. 2 | Fig. 3


Fig. 4 | Fig. 5

Fig. 6


Fig. 7 | Ffig. 8 | Fig. 9


Fig. 10 | Fig. 11
Fig. 12

Fig. 13


Fig. 14 | Fig. 15

Here is a picture of the radio in a test configuration with software MP3 decoding. Only the PCM5102 is connected. There is also a PAM8303 mounted under the ESP32-board to test internal DAC output.
Tip: connect the SCK pin of the PCM5102 to ground. This will protect against heavy noise.


4 PCB.

You can order a PCB for this radio here. (https://www.pcbway.com/project/shareproject/W652317AS2P1_Gerber_ESP32_Radio_PCB_ESP32_Radio_fab8a6d9.html)


Hans Vink designed a 3D printable case for this radio. See https://www.thingiverse.com/thing:3346460

It looks like this:


4.1 Another model.

Print and case by Simeon Kartalov from Bulgaria. It has headphone output and uses a Zippy B5 side switch for the rotary encoder.


## 5 Wiring:

The logic wiring in the table below. The analog amplifier and the speakers are not included.
Note that the GPIO pins are just an example. The assignment of GPIO pins is defined in the preferences that can be edited in the "config" page of the web interface.
ESP32dev Signal Wired to LCD | Wired to VS1053 | Wired to the rest
GPIO16 | | - | pin 1 XDCS | -
GPIO5 | | - | pin 2 XCS | -
GPIO4 | | - | pin 4 DREQ | -
GPIO2 | | pin 3 D/C or A0 | - | -
GPIO22 | | - | - | -
GPIO21 | RXD2 | - | - | TX of NEXTION (if in use)
GPIO17 | TXD2 | - | - | RX of NEXTION (if in use)
GPIO18 | SCK | pin 5 CLK or SCK | pin 5 SCK | -
GPIO19 | MISO | - | pin 7 MISO | -
GPIO23 | MOSI | pin 4 DIN or SDA | pin 6 MOSI | -
GPIO15 | | pin 2 CS | - | -
GPI03 | RXD0 | - | - | Reserved serial input
GPIO1 | TXD0 | - | - | Reserved serial output
GPIO34 | - | - | - | Optional pull-up resistor
GPIO35 | - | - | - | Infrared receiver VS1838B
GPIO25 | - | - | - | Rotary encoder CLK
GPIO26 | - | - | - | Rotary encoder DT
GPIO27 | - | - | - | Rotary encoder SW
GND | - | pin 8 GND | pin 8 GND | Power supply GND
VCC 5 V - | pin 7 BL | - | Power supply
VCC 5 V - | pin 6 VCC | pin 9 5V | Power supply
EN | - | pin 1 RST | pin 3 XRST | -

6 Uploading firmware and data.

Find out what COM-poort is used by the USB to Serial convertor on the ESP32 board. That should be visible in the Windows device manager. In PlatformIO, edit the COM port settings. Example for COM9:

monitor_port | = COM9
upload_port | = COM9
Then open a terminal in PlatformIO with this button:

Flash the firmware with PlatformIO. Use this command in the terminal:
pio run -t upload

Now upload the filesystem for the web interface from the data directory with the command: pio run -t uploadfs
Your data directory should look like this:


Start in PlatformIO the serial monitor with the button:

Press reset on the ESP32.
In the serial output you see lines like this:
D: Connect to WiFi
D: WiFi Failed! Trying to setup AP with name ESP32Radio and password ESP32Radio.
D: IP = 192.168.4.1
Connect to the access point “ESP32Radio” on your Windows machine. Password is “ESP32Radio”. Open in your web browser “http://192.168.4.1”. You should see the home page of the radio.
Go to the config tab and do some configuration.

7 Amplifier and power circuit (VS1053 version).

The amplifier is a class D stereo amplifier. If the power is shared with the power supply of the radio, you will hear much noise. So I used a separate LiPo battery (Batt 2) for the amplifier.
During operation only Batt 1 will be charged. If the radio is switched off, both batteries will be recharged by the LiPo charger. S1a, S1b and S1c is a triple On-On switch.
Note that there may be high currents in the “off”-position if one of the batteries fully discharged. Use protected batteries only!


A better approach is to use 2 small audio transformers to isolate the output of the VS1053 from the power circuit. This is used on the PCB mentioned before.
8 Backlight control circuit.


9 SD card.

As soon as a new SD is detected in the (optional) SD card slot, the radio starts to index all MP3 tracks on the card. The tracks (compressed filenames) are stored in a file called “tracklist.dat” on the card. If the tracklist is already on the card, no new file will be generated, but the tracks in the file are read in order to count the number of available tracks.
If you add new tracks to the card, you should remove the file “tracklist.dat” in the rot directory of the SD card. The next time you insert the card into the radio, a new index will be generated.
You may choose a tracktitle in the MP3-player page of the webinterface.
10 Web interface.

The web interface is simple and can be adapted to your needs. The basic idea is to have a html page with embedded javascript that displays an interface to the radio. Command to the radio can be sent to the http server on the ESP32. The IP address of the webserver will be displayed on the TFT during startup. The webpages are defined in the data directory.

### 10.1 Capabilities of the webserver:

Let’s assume that the IP of the ESP32-radio is 192.168.2.12. From your browser you can show a simple root page by entering the following URL: http://192.168.2.12. This will display the index.html page from the ESP32 as well as favicon.ico.
If your computer is configured for mDNS, you can also use http://ESP32Radio.local (http://esp-radio.local/) in your browser.
The following simple web interface will be displayed (VS1053 version):


Clicking on one of the available buttons will control the ESP32-radio. The reply of the webserver will be visible in the status box below the buttons. A click will be translated into a command to the ESP32-radio in the form: http://192.168.2.12/?<parameter>=<value>
For example: http://192.168.2.12/?upvolume=2

The “STATUS” and “TEST” buttons give some info about the playing stream/file. The “Search” menu option can be used to discover stations. The list of stations is maintained by Community Radio Browser. See https://www.radio-browser.info.

The “SLEEP” button puts the ESP32 into sleep mode. Only the reset button can wake-up the radio; a reset is necessary.

Not all functions are available as buttons in the web interface shown above. Commands may also come from MQTT or serial input. Not all commands are meaningful on MQTT or serial input. Working commands are:

preset | = 12 | Select start preset to connect to
preset_00 = <mp3 stream> | Specify station for a preset 00-max *)
volume | = 95 | Percentage between 0 and 100
upvolume | = 2 | Add percentage to current volume
downvolume = 2 | Subtract percentage from current volume
toneha | = <0..15> | Setting treble gain
tonehf | = <0..15> | Setting treble frequency
tonela | = <0..15> | Setting bass gain
tonelf | = <0..15> | Setting treble frequency
station | = <mp3 stream> | Select new station (will not be saved)
station | = <URL>.mp3 | Play standalone .mp3 file (not saved)
station | = <URL>.m3u | Select playlist (will not be saved)
(un)mute | | Mute/unmute the music
wifi_00 | = mySSID/mypassword | Set WiFi SSID and password *)
mqttbroker = mybroker.com | Set MQTT broker to use *)
mqttprefix = XP93g | Set MQTT broker to use
mqttport | = 1883 | Set MQTT port to use, default 1883 *)
mqttuser | = myuser | Set MQTT user for authentication *)
mqttpasswd = mypassword | Set MQTT password for authentication *)
mqttrefresh | | Request to refresh all MQTT items
clk_server = pool.ntp.org | Time server to be used *)
clk_offset = <-11..+14> | Offset with respect to UTC in hours *)
clk_dst | = <1..2> | Offset during dst in hours *)
sleep | | Put radio into deep sleep mode. Wake-up by reset only.
settings | | Returns setting like presets and tone
status | | Show current URL to play
test | | For test purposes
debug | = 0 or 1 | Switch debugging on or off
reset | | Restart the ESP32
bat0 | = 2318 | ADC value for an empty battery
bat100 | = 2916 | ADC value for a fully charged battery

Commands marked with "*)" are sensible during power-up only.

Station may also be of the form “skonto.ls.lv:8002/mp3”. The default port is 80.
Station may also point to an mp3 playlist. Example: “stream.laut.fm/radioparty.m3u”.
Station may be an .mp3-file on a remote server. Example: "samples-files.com/samples/Audio/mp3/sample-file-1.mp3".
It is allowed to have multiple (max 200) “preset_” lines. The number after the “_” will be used as the preset number. The comment part (after the “#”) will be shown in the web interface.

It is also allowed to have multiple “wifi_” lines. The strongest WiFi access point will be used.

## 11 Configuration

The "Config" button will bring up a second screen. Here you can edit the preferences. The config screen will be shown automatically if the ESP32 cannot connect to one of the WiFi stations specified in the preferences. In that case the ESP32 will act as an access point with the name “ESP32-Radio”. You have to connect to this AP with password “ESP32-Radio”. Then the ESP32-radio can be reached at http://192.168.4.1.
The configuration screen will be displayed and you have the opportunity to edit the preferences. A "default" button is available to fill the edit-box with some example data. For a quick start, just fill in you WiFi network name and password and click "Save". Restart the radio “Restart” button.

After changing the contents of this page, it must be saved to the preferences by clicking the “Save” button. Changes will have effect on the next restart of the ESP-radio, so click the “Restart” button.


12 Rotary encoder interface.

The rotary encoder switch can control some essential functions of the ESP32-radio. The "GND"- pin must be connected to ground. Some encoders have a “VCC” pin. In that case, connect it to the 3.3 Volt pin of the ESP32 DEV module.
12.1 Rotary encoder volume control.

The default function is volume control. Turning the knob will result in lower or higher volume. Pressing the knob will mute/unmute the signal. The text “Mute” or “Unmute” will be shown on the TFT during 4 seconds.
12.2 Rotary encoder preset mode.

A double click selects the preset-mode. Rotation of the switch will select one of the preset stations. The preset will be shown on the TFT. Once a preset is selected, you can activate this preset by a single click.
Without rotation, the next preset is selected.
After an inactivity of 4 seconds the rotary encoder will return to its default function (VOLUME).
12.3 Rotary encoder SD track select.

A triple click will select SD mode. Rotate to scroll through the list of tracks and press the knob to play the track.
12.4 Rotary encoder stop player.

A long click will stop the radio/mp3player.

13 Supported displays.

The preferred display is a 1.8 inch TFT with 160x128 pixels. Other displays may also be used:
- No display. Edit the config.h file (around line 35), so that “DUMMYTFT” is defined and all other display types are commented out.
- The preferred display 160x128 pixels. Define “BLUETFT” and comment out the other types.
- An ILI9341 display, default 320x240 pixels. Define “ILI9341” and comment out the other types.
- A 128x128 1.44 inch display. Edit bluetft.h (around line 58), use “INITR_144GREENTAB” and set dsp_getwidth() to 128.
- A ST7789 240 x 240 display. Define “ST7789 “ and comment out the other types.
- A 128x64 OLED. Define “”OLED” and comment out the other types.
- An LCD 1602 display with I2C backpack. Define “LCD1602I2C” and comment out the other types. Note that this display is limited as it has only 32 characters.
- An LCD 2004 display with I2C backpack. Define “LCD2004I2C” and comment out the other types. Note that this display is limited as it has only 80 characters.
- A NEXTON model NX#@@$T024_11 display connected to GPIO 16 and 17.

The OLED, 2004 and 1602 displays use the serial I2C bus. There must be definitions for this in the preferences, for example:

pin_tft_scl = 13 | # GPIO Pin number for SCL
pin_tft_sda = 14 | # GPIO Pin number for SDA

Th I2C address of the 2004 and 1602 displays is defined in the corresponding module.

14 Wired (ethernet) version.

A wired version of the radio is also possible. For testing I used a WT32-ETH01 module that has a built-in LAN8720 ethernet controller. The number of free pins is therefore limited. With the VS1053 and the BLUETFT display I used the following pin setting in the configuration page of the web interface:

pin_vs_cs = 2 | # GPIO VS1053 CS
pin_vs_dcs = 12 | # GPIO VS1053 DCS
pin_vs_dreq = 4 | # GPIO VS1053 DREQ
pin_spi_sck = 5 | # GPIO SPI SCK
pin_spi_miso = 33 | # GPIO SPI MISO
pin_spi_mosi = 17 | # GPIO SPI MOSI
pin_tft_cs = 15 | # GPIO BLUETFT CS
pin_tft_dc = 14 | # GPIO BLUETFT A0

This module has also been tested with I2S output. The pins used above for the VS1053 were used for the 3 I2S signals.

15 AI Thinker Audio kit V2.1.

This board has an I2S DAC on-board and there are speaker outputs as well as an output for headphones.
The number of free GPIOs is limited. The internal DAC is a AC101. Note that later versions of this board may have a different DAC. The software works for the AC101 only!
GPIOs that are used internally are 2, 4, 13, 14, 15, 25, 26, 27, 32, 33, 34.
GPIOs that are free and available at the 12 pin header are 21, 22, 19, 23, 18, 5.
If you want to use the KEYs, only 21 and 22 are free.
Since there are only a few GPIO pins are available, the best option for the human interface is probably a NEXTION display. For testing I used “pin_nxt_rx = 18” and “pin_nxt_tx = 5” in de config page of the web interface.

### The GPIO configuration in the web interface should contain the following lines:

pin_i2s_bck = 27 | # AI GPIO Pin for I2S "BCK"
pin_i2s_din = 25 | # AI GPIO Pin for I2S "DIN"
pin_i2s_lck = 26 | # AI GPIO Pin for I2S "L(R)CK"
pin_nxt_rx = 18 | # NEXTION serial input
pin_nxt_tx = 5 | # NEXTION serial output
pin_sd_cs = 13 | # AI GPIO Pin for Chip select SD card
pin_sd_detect = 34 | # AI GPIO Pin for CD inserted
pin_spi_miso = 2 | # AI GPIO Pin for SPI MISO
pin_spi_mosi = 15 | # AI GPIO Pin for SPI MOSI
pin_spi_sck = 14 | # AI GPIO Pin for SPI SCK

### Before compilation, change the config.h file like this:

### Section “..MP3/AAC decoder”:

#define | DEC_HELIX_AI | // Software decoder for AI Audio kip (AC101)

### Section “..display..”:

#define | NEXTION | // Nextion display

16 MQTT interface.

The MQTT interface can handle the same commands as the web interface.
As publish command on a Linux system may look like:
$ mosquitto_pub -h broker.hivemq.com -t espradio -m volume=80
Note that broker.hivemq.com is heavily used, this may cause some delay. If you use your own broker the reaction on commands will be much better.
Remove the lines starting with “mqtt” if no MQTT is required or set mqttbroker to "none".
You can use an MQTT client like https://kamilfb.github.io/mqtt-spy/ to view the MQTT interface.


Subscribe to “P82C40A24/ip” and you will see the IP-address of your radio. You will see the IP address of your radio or the IP address of a different user. So be sure to use unique names for your topics. This can be accomplished by specifying a unique prefix in the preferences, see below.
The parameters in preferences for this example are:

# MQTT broker, credentials and topic to subscribe

mqttbroker = broker.hivemq.com | # Broker to connect with
mqttprefix = P82C40A24 | # Prefix for pub/sub. Default is part of MAC-address.
mqttport = 1883 | # Portnumber (1883 is default)
mqttuser = none | # (No) username for broker
mqttpasswd = none | # (No) password for broker

In this example I published the command “mute” to the radio. The radio published the IP-address 192.168.2.8 to the broker (once every 10 minutes).
16.1.1 MQTT PUB topics.

In this version 7 topics will be published to MQTT and can be subscribed to by an MQTT client:
prefix/ip | The IP-address of the ESP32-Radio
prefix/icy/name | The name of the station
prefix/icy/streamtitle | The name of the stream

prefix/nowplaying | Track information
prefix/preset | Preset currently plaing
prefix/volume | Current volume setting
prefix/playing | 1 if playing, 0 if stopped

Command to control the ESP32-Radio can be published to "prefix/command".
16.1.2 Alternative way of configuration.

An extra sketch "Esp32_radio_init.ino" is supplied as an alternative to initialize the preferences (in Non-Voltile Storage of the ESP32). Just change lines 39 and 40 (the specs for WiFi networks) to match your network(s).
Upload and run the sketch once and then load the ESP32-Radio.

17 Compiling with Arduino IDE.

The preferred way to compile this project is to using PlatformIO. For the ArduinoIDE (version 2.3.2), some extra steps must be taken:
- Download the project from github (https://github.com/Edzelf/ESP32Radio-V2/archive/refs/heads/main.zip). Store the zip file in any directory.
- Go to this directory and unzip the zip file. This will produce a directory with the name “ESP32Radio-V2-main”.
- Rename “ESP32Radio-V2-main” to “ESP32Radio”. That will be your work directory. Got to this directory. It will look like this:


- Remove ”doc”, ”tools”, ”ESP32-Radio.code-workspace”, ”LICENCE”, ”platformio.ini” and ”README.md”
- Move the 3 files in “src” to your work directory. And remove the (now empty) “src” directory.
- Move all files from “include” to your work directory and remove the “include” directory.
- Edit the file config.h to meet your configuration (display, codec, ..). Edit your WiFi credentials in “FIXEDWIFI” and uncomment this line.
- Move the files in “lib/codecs/src” to your work directory. If you use VS1053, you may skip the aac* and mp3* files.
- Depending on your type of display, move the files in “lib/ILI9341/src” to your work directory,
or move the files in “lib/LCD1602/src” to your work directory,
or move the files in “lib/LCD2004/src” to your work directory,
or move the files in “lib/NEXTION/src” to your work directory,
or move the files in “lib/bluetft/src” to your work directory,
or move the files in “lib/dummytft/src” to your work directory, or move the files in “lib/OLED/src” to your work directory,
or move the files in “lib/ST7789/src” to your work directory.
- Remove the “lib” directory if you want to save some diskspace.
- Rename the file “main.cpp” to “ESP32Radio.ino”.
- Your work directory will now contain “data”, “nextion”, the source files and maybe “lib”.
- Start the Arduino IDE by double clicking “ESP32Radio.ino”.
- Connect the USB serial port of your ESP32 to your computer.
- You may need to install “esp32 by Espressif” in the “BOARDS MANAGER”.
- Select the right board (ESP32 Dev Module) in Tools->Board and set the right Port.
- Enable debug output in Tools->Core Debug Level. Set it to “Info”.
- You can now verify the sketch. You probably have to install some libraries.

Some of the libraries used (depends on configuration):

WiFi at version 2.0.0
PubSubClient at version 2.8
ESPmDNS at version 2.0.0
SPI at version 2.0.0
ArduinoOTA at version 2.0.0
Update at version 2.0.0
ESPAsyncWebServer-master at version 1.2.0 FS at version 2.0.0
AsyncTCP-master at version 1.0.3
SPIFFS at version 2.0.0
Adafruit_ST7735_and_ST7789_Library at version 1.7.4

Adafruit_GFX_Library at version 1.10.12 Adafruit_BusIO at version 1.9.3
Wire at version 2.0.0

18 Compiler/upload output.

18.1 Software upload.

Processing esp32 (platform: espressif32; board: esp32doit-devkit-v1; framework: arduino) ----------------------------------------------------------------------------------------------------Verbose mode can be enabled via `-v, --verbose` option
CONFIGURATION: https://docs.platformio.org/page/boards/espressif32/esp32doit-devkit-v1.html PLATFORM: Espressif 32 (3.5.0) > DOIT ESP32 DEVKIT V1
HARDWARE: ESP32 240MHz, 320KB RAM, 4MB Flash
DEBUG: Current (esp-prog) External (esp-prog, iot-bus-jtag, jlink, minimodule, olimex-arm-usb-ocd, olimex-arm-usb-ocd-h, olimex-arm-usb-tiny-h, olimex-jtag-tiny, tumpa)
PACKAGES:
- framework-arduinoespressif32 3.10006.210326 (1.0.6)
- tool-esptoolpy 1.30100.210531 (3.1.0)
- tool-mkspiffs 2.230.0 (2.30)
- toolchain-xtensa32 2.50200.97 (5.2.0)
LDF: Library Dependency Finder -> https://bit.ly/configure-pio-ldf LDF Modes: Finder ~ chain, Compatibility ~ soft
Found 46 compatible libraries
Scanning dependencies...
Dependency Graph
|-- <Wire> 1.0.1
|-- <SD(esp32)> 1.0.5
| | |-- <FS> 1.0
| | |-- <SPI> 1.0
|-- <PubSubClient> 2.8.0
|-- <Adafruit BusIO> 1.11.3
| | |-- <Wire> 1.0.1
| | |-- <SPI> 1.0
|-- <Adafruit GFX Library> 1.10.14
| | |-- <SPI> 1.0
| | |-- <Adafruit BusIO> 1.11.3
| | | | |-- <Wire> 1.0.1
| | | | |-- <SPI> 1.0
| | |-- <Wire> 1.0.1
|-- <Adafruit ILI9341> 1.5.10
| | |-- <Adafruit GFX Library> 1.10.14
| | | | |-- <SPI> 1.0
| | | | |-- <Adafruit BusIO> 1.11.3
| | | | | | |-- <Wire> 1.0.1
| | | | | | |-- <SPI> 1.0
| | | | |-- <Wire> 1.0.1
| | |-- <SPI> 1.0
|-- <Adafruit ST7735 and ST7789 Library> 1.9.3
| | |-- <Adafruit GFX Library> 1.10.14
| | | | |-- <SPI> 1.0
| | | | |-- <Adafruit BusIO> 1.11.3
| | | | | | |-- <Wire> 1.0.1
| | | | | | |-- <SPI> 1.0
| | | | |-- <Wire> 1.0.1
| | |-- <SPI> 1.0
|-- <ESP Async WebServer> 1.2.3
| | |-- <AsyncTCP> 1.1.1
| | |-- <FS> 1.0
| | |-- <WiFi> 1.0
|-- <AsyncTCP> 1.1.1
|-- <codecs>
| |-- <SPI> 1.0
|-- <bluetft>
| | |-- <Adafruit ST7735 and ST7789 Library> 1.9.3
| | | | |-- <Adafruit GFX Library> 1.10.14
| | | | | | |-- <SPI> 1.0
| | | | | | |-- <Adafruit BusIO> 1.11.3
| | | | | | | | |-- <Wire> 1.0.1
| | | | | | | | |-- <SPI> 1.0
| | | | | | |-- <Wire> 1.0.1
| | | | |-- <SPI> 1.0
|-- <dummytft>
|-- <ILI9341>
| | |-- <Adafruit ILI9341> 1.5.10
| | | | |-- <Adafruit GFX Library> 1.10.14
| | | | | | |-- <SPI> 1.0
| | | | | | |-- <Adafruit BusIO> 1.11.3

| | | | | | | | |-- <Wire> 1.0.1
| | | | | | | | |-- <SPI> 1.0
| | | | | | |-- <Wire> 1.0.1
| | | | |-- <SPI> 1.0
|-- <LCD1602>
|-- <LCD2004>
|-- <NEXTION>
|-- <OLED>
|-- <ST7789>
| | |-- <Adafruit ST7735 and ST7789 Library> 1.9.3
| | | | |-- <Adafruit GFX Library> 1.10.14
| | | | | | |-- <SPI> 1.0
| | | | | | |-- <Adafruit BusIO> 1.11.3
| | | | | | | | |-- <Wire> 1.0.1
| | | | | | | | |-- <SPI> 1.0
| | | | | | |-- <Wire> 1.0.1
| | | | |-- <SPI> 1.0
|-- <ArduinoOTA> 1.0
| | |-- <Update> 1.0
| | |-- <WiFi> 1.0
| | |-- <ESPmDNS> 1.0
| | | | |-- <WiFi> 1.0
|-- <ESPmDNS> 1.0
| |-- <WiFi> 1.0
|-- <SPI> 1.0
|-- <SPIFFS> 1.0
| |-- <FS> 1.0
|-- <WiFi> 1.0
|-- <FS> 1.0
Building in release mode
Compiling .pio\build\esp32\src\main.cpp.o
Linking .pio\build\esp32\firmware.elf
Retrieving maximum program size .pio\build\esp32\firmware.elf
Checking size .pio\build\esp32\firmware.elf
Advanced Memory Usage is available via "PlatformIO Home > Project Inspect"
RAM: | | [== | | ] 18.0% (used 58932 bytes from 327680 bytes)
Flash: [========= ] 85.5% (used 1120346 bytes from 1310720 bytes) Building .pio\build\esp32\firmware.bin
esptool.py v3.1
Merged 1 ELF section
Configuring upload protocol...
AVAILABLE: esp-prog, espota, esptool, iot-bus-jtag, jlink, minimodule, olimex-arm-usb-ocd, olimex-arm-usb-ocd-h, olimex-arm-usb-tiny-h, olimex-jtag-tiny, tumpa
CURRENT: upload_protocol = esptool
Looking for upload port...
Use manually specified: COM3
Uploading .pio\build\esp32\firmware.bin esptool.py v3.1
Serial port COM3
Connecting........_____....._____....
Chip is ESP32-D0WDQ6 (revision 1)
Features: WiFi, BT, Dual Core, 240MHz, VRef calibration in efuse, Coding Scheme None Crystal is 40MHz
MAC: cc:50:e3:95:88:90
Uploading stub...
Running stub...
Stub running...
Changing baud rate to 460800 Changed.
Configuring flash size...
Auto-detected Flash size: 4MB
Flash will be erased from 0x00001000 to 0x00005fff... Flash will be erased from 0x00008000 to 0x00008fff... Flash will be erased from 0x0000e000 to 0x0000ffff... Flash will be erased from 0x00010000 to 0x00121fff...
Compressed 17104 bytes to 11191...
Writing at 0x00001000... (100 %)
Wrote 17104 bytes (11191 compressed) at 0x00001000 in 0.6 seconds (effective 234.7 kbit/s)... Hash of data verified.
Compressed 3072 bytes to 128...
Writing at 0x00008000... (100 %)
Wrote 3072 bytes (128 compressed) at 0x00008000 in 0.1 seconds (effective 394.0 kbit/s)... Hash of data verified.
Compressed 8192 bytes to 47...
Writing at 0x0000e000... (100 %)
Wrote 8192 bytes (47 compressed) at 0x0000e000 in 0.1 seconds (effective 478.3 kbit/s)...

Hash of data verified.
Compressed 1120448 bytes to 644211... Writing at 0x00010000... (2 %) Writing at 0x0001a3c4... (5 %) Writing at 0x00027b54... (7 %) Writing at 0x00032214... (10 %) ..
Writing at 0x00113ca2... (95 %)
Writing at 0x00119941... (97 %)
Writing at 0x0011f4c0... (100 %)
Wrote 1120448 bytes (644211 compressed) at 0x00010000 in 15.5 seconds (effective 576.9 kbit/s)... Hash of data verified.

Leaving...
Hard resetting via RTS pin...
18.2 Filesystem upload.

PS D:\docs\PlatformIO\Projects\ESP32-Radio> pio run -t uploadfs
Processing esp32doit-devkit-v1 (platform: espressif32; board: esp32doit-devkit-v1; framework: arduino) -----------------------------------------------------------------------------------------------------------------------------Verbose mode can be enabled via `-v, --verbose` option
CONFIGURATION: https://docs.platformio.org/page/boards/espressif32/esp32doit-devkit-v1.html
PLATFORM: Espressif 32 (3.3.2) > DOIT ESP32 DEVKIT V1
HARDWARE: ESP32 240MHz, 320KB RAM, 4MB Flash
DEBUG: Current (esp-prog) External (esp-prog, iot-bus-jtag, jlink, minimodule, olimex-arm-usb-ocd, olimex-arm-usb-ocd-h, olimex-arm-usb-tiny-h, olimex-jtag-tiny, tumpa)
PACKAGES:
- framework-arduinoespressif32 3.10006.210326 (1.0.6)
- tool-esptoolpy 1.30100.210531 (3.1.0)
- tool-mkspiffs 2.230.0 (2.30)
- toolchain-xtensa32 2.50200.97 (5.2.0)
LDF: Library Dependency Finder -> http://bit.ly/configure-pio-ldf LDF Modes: Finder ~ chain, Compatibility ~ soft
Found 47 compatible libraries
Scanning dependencies...
Dependency Graph
|-- <Wire> 1.0.1
|-- <SD(esp32)> 1.0.5
| | |-- <FS> 1.0
| | |-- <SPI> 1.0
|-- <PubSubClient> 2.8.0
|-- <Adafruit ST7735 and ST7789 Library> 1.7.4
| | |-- <Adafruit GFX Library> 1.10.12
| | | | |-- <SPI> 1.0
| | | | |-- <Adafruit BusIO> 1.9.3
| | | | | | |-- <Wire> 1.0.1
| | | | | | |-- <SPI> 1.0
| | | | |-- <Wire> 1.0.1
| | |-- <SPI> 1.0
|-- <Adafruit BusIO> 1.9.3
| | |-- <Wire> 1.0.1
| | |-- <SPI> 1.0
|-- <Adafruit GFX Library> 1.10.12
| | |-- <SPI> 1.0
| | |-- <Adafruit BusIO> 1.9.3
| | | | |-- <Wire> 1.0.1
| | | | |-- <SPI> 1.0
| | |-- <Wire> 1.0.1
|-- <Adafruit ILI9341> 1.5.9
| | |-- <Adafruit GFX Library> 1.10.12
| | | | |-- <SPI> 1.0
| | | | |-- <Adafruit BusIO> 1.9.3
| | | | | | |-- <Wire> 1.0.1
| | | | | | |-- <SPI> 1.0
| | | | |-- <Wire> 1.0.1
| | |-- <SPI> 1.0
|-- <ESP Async WebServer> 1.2.3
| | |-- <AsyncTCP> 1.1.1
| | |-- <FS> 1.0
| | |-- <WiFi> 1.0
|-- <AsyncTCP> 1.1.1
|-- <codecs>
| |-- <SPI> 1.0
|-- <bluetft>
| | |-- <Adafruit ST7735 and ST7789 Library> 1.7.4
| | | | |-- <Adafruit GFX Library> 1.10.12
| | | | | | |-- <SPI> 1.0
| | | | | | |-- <Adafruit BusIO> 1.9.3
| | | | | | | | |-- <Wire> 1.0.1
| | | | | | | | |-- <SPI> 1.0
| | | | | | |-- <Wire> 1.0.1

| | | | |-- <SPI> 1.0
|-- <dummytft>
|-- <ILI9341>
| | |-- <Adafruit ILI9341> 1.5.9
| | | | |-- <Adafruit GFX Library> 1.10.12
| | | | | | |-- <SPI> 1.0
| | | | | | |-- <Adafruit BusIO> 1.9.3
| | | | | | | | |-- <Wire> 1.0.1
| | | | | | | | |-- <SPI> 1.0
| | | | | | |-- <Wire> 1.0.1
| | | | |-- <SPI> 1.0
|-- <LCD1602>
|-- <LCD2004>
|-- <NEXTION>
|-- <ArduinoOTA> 1.0
| | |-- <Update> 1.0
| | |-- <WiFi> 1.0
| | |-- <ESPmDNS> 1.0
| | | | |-- <WiFi> 1.0
|-- <ESPmDNS> 1.0
| |-- <WiFi> 1.0
|-- <SPI> 1.0
|-- <SPIFFS> 1.0
| |-- <FS> 1.0
|-- <WiFi> 1.0
Building in release mode
Building SPIFFS image from 'data' directory to .pio\build\esp32doit-devkit-v1\spiffs.bin /about.html
/config.html
/defaultprefs.txt
/favicon.ico
/index.html
/search.html
/style.css
Looking for upload port...
Use manually specified: COM4
Uploading .pio\build\esp32doit-devkit-v1\spiffs.bin esptool.py v3.1
Serial port COM4
Connecting....
Chip is ESP32-D0WDQ6 (revision 1)
Features: WiFi, BT, Dual Core, 240MHz, VRef calibration in efuse, Coding Scheme None Crystal is 40MHz
MAC: 24:6f:28:b0:7b:e0
Uploading stub...
Running stub...
Stub running...
Changing baud rate to 460800 Changed.
Configuring flash size...
Auto-detected Flash size: 4MB
Flash will be erased from 0x00290000 to 0x003fffff...
Compressed 1507328 bytes to 12150...
Writing at 0x00290000... (100 %)
Wrote 1507328 bytes (12150 compressed) at 0x00290000 in 8.0 seconds (effective 1505.9 kbit/s)... Hash of data verified.

Leaving...
Hard resetting via RTS pin...

19 Debug (serial 115200 Baud) output.

This is an example of the debug output. Note that the debug level (CORE_DEBUG_LEVEL in platformio.ini) is set to 5.

rst:0xc (SW_CPU_RESET),boot:0x13 (SPI_FAST_FLASH_BOOT)
configsip: 0, SPIWP:0xee
clk_drv:0x00,q_drv:0x00,d_drv:0x00,cs0_drv:0x00,hd_drv:0x00,wp_drv:0x00 mode:DIO, clock div:2
load:0x3fff0030,len:1184
load:0x40078000,len:13232
load:0x40080400,len:3028
entry 0x400805e4
[ 34][D][esp32-hal-cpu.c:244] setCpuFrequencyMhz(): PLL: 480 / 2 = 240 Mhz, APB: 80000000 Hz
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

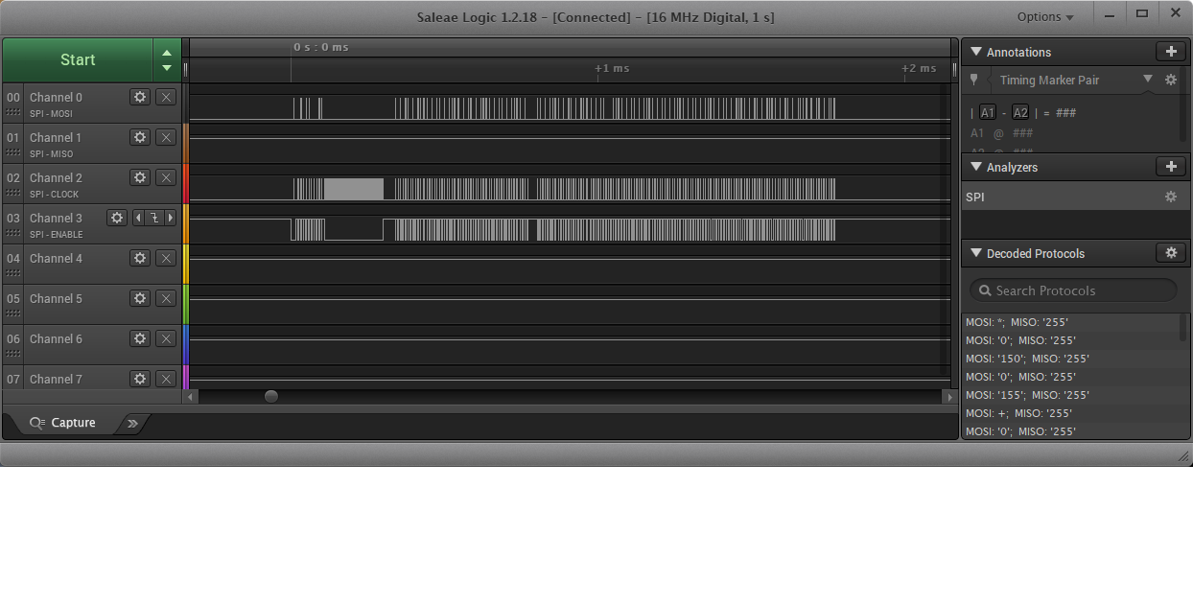
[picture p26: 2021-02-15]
doc/TFT signa analysis.png

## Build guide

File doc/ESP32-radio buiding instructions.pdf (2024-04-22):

# ESP32-radio building instructions

This document describes the building instruction of ESP32 Internet radio. It is assumed that the PCB for this radio, available through PCBWay, (https://www.pcbway.com/project/shareproject/W652317AS2P1_Gerber_ESP32_Radio_PCB_ESP32_Radio_fab8a6d9.html) is used.
The PCB can be used for several configurations of the hardware. For every variety a chapter is included in this document.
The 3 varieties are:
1. Radio with software MP3 decoding and SPDIF (optical) output only.
2. Radio with software MP3 decoding and line output.
3. Radio with software MP3 decoding, amplifier and speaker output.
4. Radio with hardware MP3 decoding and line output.
5. Radio with hardware MP3 decoding, amplifier and speaker output.

Within these varieties, there are option like a TFT display and a rotary encoder. See chapter 6. The print (top side) looks like this:

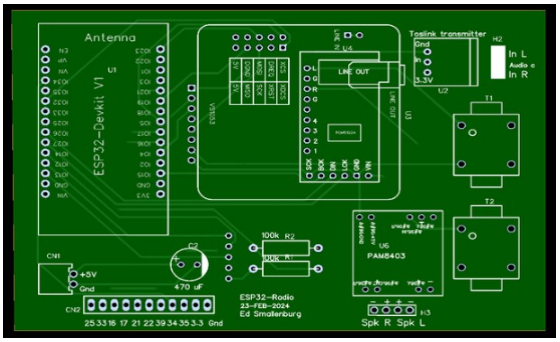
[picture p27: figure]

There is a small error in the print. The texts near the 3 holes of the Toslink transmitter (U2) are wrong. “In” should be “3.3V” and “3.3V” should be “In”.

The bottom side of the print looks like this:

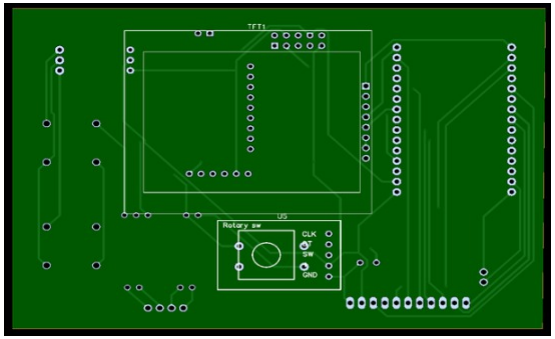
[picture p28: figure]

The display and/or the rotary encoder should be mounted here.

ESP32 Radio building instructions -- page 1

1 Radio with software MP3 decoding and SPDIF (optical) output only.

This is the simplest version. In fact there are only 2 active parts: the ESP32 and a Toslink optical transmitter. There is no tone control. You need an external stereo amplifier with a optical (Toslink) input. The software can only decode MP3 and AAC data streams, but they are most commonly used.
1.1 Used components.
1. PBC. Available through PCBway. (https://www.pcbway.com/project/shareproject/W652317AS2P1_Gerber_ESP32_Radio_PCB_ESP32_Radio_fab8a6d9.html)
2. ESP32 devkit V1. Available here. (https://nl.aliexpress.com/item/1005006450124383.html)

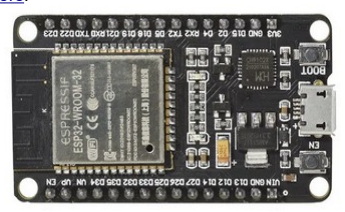
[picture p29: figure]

3. Note that the pin layout must correspond with the picture above.
4. A Toslink transmitter. Available here. (https://nl.aliexpress.com/item/1005004748833405.html) You may also need a Toslink cable to your amplifier.
5. An electrolytic capacitor, 470 µF (220 µF or 100 µF will also work).
6. A 2 pin connector witch cable to your 5 Volt power supply. For example this. (https://nl.aliexpress.com/item/1005005961786030.html) Note that the distance between the pins is 2.54 mm.
The pins for +5 (red) and ground (black) may be reversed. Use a sharp pin to modify if necessary.
You may also directly solder the power lines to the print of course.
7. Female headers to mount the ESP32. 2 headers of 15 pins are needed. You may also use a 40 pin header and cut it into 2 x 15 pins. See here. (https://nl.aliexpress.com/item/4000873858801.html)
8. 2 x 100 k resistors. Not needed if you are not interested in reading the battery voltage.
9. Optional: a TFT display and or a rotary encoder. See chapter 6.

1.2 Mounting instructions.

1. Prepare 2 15 pins female headers and solder them to the top side of the PCB. The position is marked with “ESP32-Devkit V1”. It helps if you put the headers on the ESP32 first in order to make the perfect alignment.
2. Mount the capacitor on the top side of the PCB. The position is marked “C2”. Align the minus side of the capacitor, marked with a white band to the right. The PCB is also marked on the right side.
3. Mount the power cable (and connector) on the top side of the PCB in the lower left corner. The position is marked “CN1”.
4. The print will now look like this:

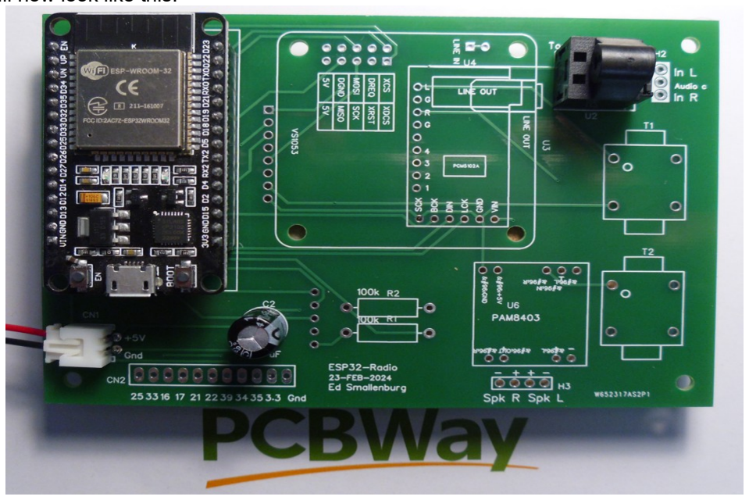
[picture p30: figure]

5. Optional: add a TFT display and/or a rotary encoder. See chapter 6.
1.3 Testing.

Edit the config.h file. Set FIXEDWIFI (near line 17) to your SSID/PASSWORD of your WiFi network.
Define “DEC_HELIX” near line 24, out-comment the other “DEC_xxxx” definitions.
If the display is mounted, define “BLUETFT” (near line 31) and out-comment the other display definitions. Otherwise, define “DUMMYTFT” and out-comment the other display definitions.

Upload the data directory to SPIFFS using “Upload Filesystem Image” in the PlatformIO menu:
and upload the compiled program using “Upload” in the same menu.

Activate the serial monitor and reset the ESP32. Observe the debug output. Make a note of the IP address (search for line containing “IP:”), for example “192.168.2.33”. Start your Internet browser and go to this address.
Go to the configuration page and press the “Default” button. Edit the configuration here, make sure that “pin_i2s_spdif = 15” is defined.
If the display is connected: make sure the lines with “pin_tft_cs = 2” and “pin_tft_dc = 4” are defined.
If the rotary encoder is mounted: make sure the lines with “pin_enc_clk = 12”, “pin_enc_dt = 14” and “pin_enc_sw = 13” are defined.

Press the “Save” button and after that press the “Restart” button”.
The red light of the LED should be visible all the time. Connect the radio to an external amplifier using a Toslink cable.

2 Radio with software MP3 decoding and line output.

The MP3 conversion is done by software in the ESP32. A Digital to analog converter is used to deliver the analog output to a headphone or to an external amplifier. There is no tone control. The software can only decode MP3 and AAC data streams, but they are most commonly used.
2.1 Used components.
1. PBC. Available through PCBway.
2. ESP32 devkit V1. Available here. (https://nl.aliexpress.com/item/1005006450124383.html)
3. Note that the pin layout must correspond with the picture above.
4. PCM5102A module. Available here. (https://nl.aliexpress.com/item/1005002898278583.html)

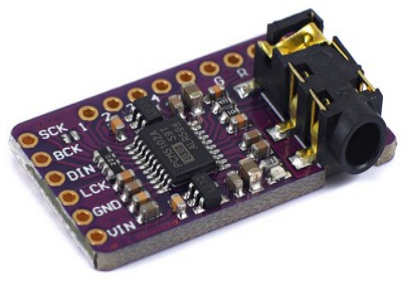
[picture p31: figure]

5. An electrolytic capacitor, 470 µF (220 µF or 100 µF will also work).
6. A 2 pin connector witch cable to your 5 Volt power supply. For example this. (https://nl.aliexpress.com/item/1005005961786030.html) Note that the distance between the pins is 2.54 mm.
The pins for +5 (red) and ground (black) may be reversed. Use a sharp pin to modify if necessary.
You may also directly solder the power lines to the print of course.
7. Female headers to mount the ESP32. 2 headers of 15 pins are needed. You may also use a 40 pin header and cut it into 2 x 15 pins. See here. (https://nl.aliexpress.com/item/4000873858801.html)
8. Male headers to mount the PCM5102A. 15 pins are needed. You may use a 40 pin header and cut it into fitting pieces. See here. (https://nl.aliexpress.com/item/4000873858801.html)
9. 2 x 100 k resistors. Not needed if you are not interested in reading the battery voltage.
10. Optional: add a TFT display and/or a rotary encoder switch. See chapter 6.

2.2 Mounting instructions.

1. Prepare 2 15 pins female headers and solder them to the top side of the PCB. The position is marked with “ESP32-Devkit V1”. It helps if you put the headers on the ESP32 first in order to make the perfect alignment.
2. Mount the capacitor on the top side of the PCB. The position is marked “C2”. Align the minus side of the capacitor, marked with a white band to the right. The PCB is also marked on the right side.
3. Mount the power cable (and connector) on the top side of the PCB in the lower left corner. The position is marked “CN1”.
4. Mount the PCM5102A on the top side of the PCB. The position is marked “PCM5102A”. Use female headers (6 and 9 pins) on the side of the PCB and male headers on the side of the PCM5102A.. It helps to put the headers on the module first in order to make the perfect alignment.
5. The print will now look like this:

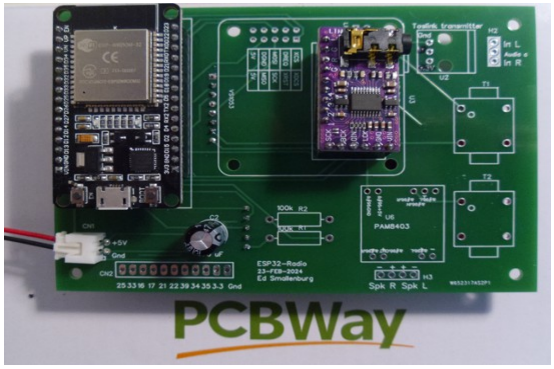
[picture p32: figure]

6. Optional: add a TFT display and/or a rotary encoder. See chapter 6.
7. Important note: In some cases, pin 3 of the PCM5102A module may not be left floating. The effect is that there will be no sound or very choopy. So it is advised to make a small modifications to the PCM5102A module if not already present. Connect the pin “3” on the back side of the module to “H”. See the picture:

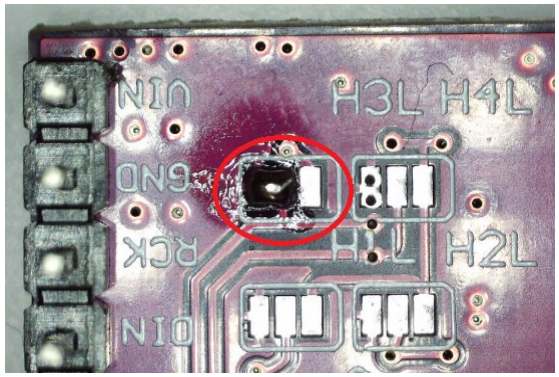
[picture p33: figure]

2.3 Testing.

Edit the config.h file. Set FIXEDWIFI (near line 17) to your SSID/PASSWORD of your WiFi network.
Define “DEC_HELIX” near line 25, out-comment the other “DEC_xxxx” definitions.
If the display is mounted, define “BLUETFT” (near line 31) and out-comment the other display definitions. Otherwise, define “DUMMYTFT” and out-comment the other display definitions.
Upload the data directory to SPIFFS using “Upload Filesystem Image” in the PlatformIO menu:
and upload the compiled program using “Upload” in the same menu.
Activate the serial monitor and reset the ESP32. Observe the debug output. Make a note of the IP address (search for line containing “IP:”), for example “192.168.2.33”. Start your Internet browser and go to this address.
Go to the configuration page and press the “Default” button. Edit the configuration here, make sure that “pin_i2s_spdif = 15” is defined.

If the display is connected: make sure the lines with “pin_tft_cs = 2” and “pin_tft_dc = 4” are defined.
If the rotary encoder is mounted: make sure the lines with “pin_enc_clk = 12”, “pin_enc_dt = 14” and “pin_enc_sw = 13” are defined.
Press the “Save” button and after that press the “Restart” button”.

3 Radio with software MP3 decoding, amplifier and speaker output.

The MP3 conversion is done by software in the ESP32. A Digital to analog converter is used to deliver the analog output to a headphone or to an external amplifier. There is no tone control. The software can only decode MP3 and AAC data streams, but they are most commonly used.
3.1 Used components.
1. PBC. Available through PCBway.
2. ESP32 devkit V1. Available here. (https://nl.aliexpress.com/item/1005006450124383.html)

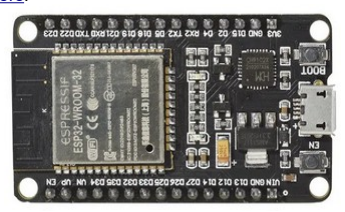
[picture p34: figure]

3. Note that the pin layout must correspond with the picture above.
4. A PCM5102A module. Available here. (https://nl.aliexpress.com/item/1005002898278583.html)
5. A PAM8403 amplifier and 2 audio transformers (600/600 Ohm). Available here (https://nl.aliexpress.com/item/1005005750019298.html) and here. (https://aliexpress.com/item/32862222914.html)

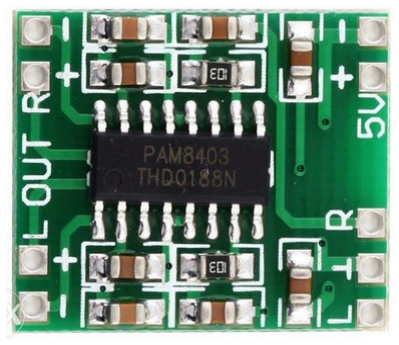
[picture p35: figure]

6. An electrolytic capacitor, 470 µF (220 µF or 100 µF will also work).
7. A 2 pin connector witch cable to your 5 Volt power supply. For example this. (https://nl.aliexpress.com/item/1005005961786030.html) Note that the distance between the pins is 2.54 mm.
The wires for +5 (red) and ground (black) may be reversed. Use a sharp pin to modify if necessary.
You may also directly solder the power lines to the print of course.
8. Female headers to mount the ESP32. 2 headers of 15 pins are needed. You may also use a 40 pin header and cut it into 2 x 15 pins. See here. (https://nl.aliexpress.com/item/4000873858801.html)
9. Male headers to mount the PCM5102A. 15 pins are needed. You may use a 40 pin header and cut it into fitting pieces. See here. (https://nl.aliexpress.com/item/4000873858801.html)
10. 2 x 100 k resistors. Not needed if you are not interested in reading the battery voltage.
11. Optional: a TFT display and/or a rotary encoder switch. See chapter 6.

3.2 Mounting instructions.

1. Prepare 2 15 pins female headers and solder them to the top side of the PCB. The position is marked with “ESP32-Devkit V1”. It helps if you put the headers on the ESP32 first in order to make the perfect alignment.
2. Mount the capacitor on the top side of the PCB. The position is marked “C2”. Align the minus side of the capacitor, marked with a white band to the right. The PCB is also marked on the right side.
3. Mount the power cable (and connector) on the top side of the PCB in the lower left corner. The position is marked “CN1”.
4. Mount the PCM5102A on the top side of the PCB. The position is marked “PCM5102A”. Use female headers (6 and 9 pins) on the side of the PCB and male headers on the side of the PCM5102A.. It helps to put the headers on the module first in order to make the perfect alignment.
5. Mount the PAM8403 module. The position on the print is marked “PAM8403”. The print will look like this

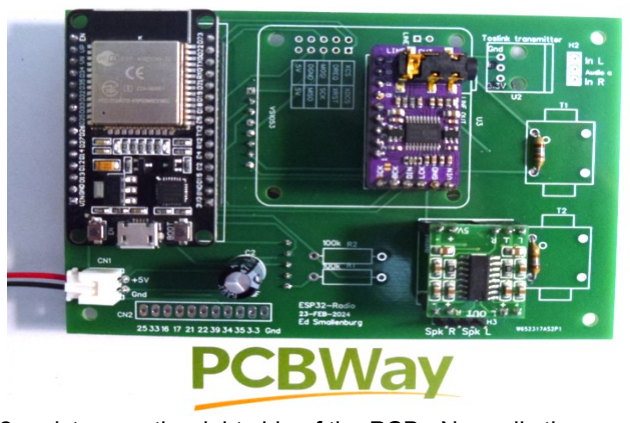
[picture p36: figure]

6. Note the 2 resistors on the right side of the PCB. Normally these are not required, but when the output volume is too high (distorsion), you can decrease it by placing 2 x180 Ohm resistors on the secondary side of T1 and T2.
7. Optional: Add a TFT display and/or a rotary encoder. See chapter 6.
8. Important note: In some cases, pin 3 of the PCM5102A module may not be left floating. So it is advised to make a small modifications to the PCM5102A module. Connect the pin “3” on the back side of the module to “H” and the other 3 pins to “L”. See the picture:

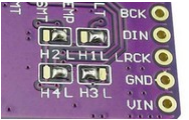
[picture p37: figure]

3.3 Testing.

Edit the config.h file. Set FIXEDWIFI (near line 17) to your SSID/PASSWORD of your WiFi network.
Define “DEC_HELIX” near line 25, out-comment the other “DEC_xxxx” definitions.
If the display is mounted, define “BLUETFT” (near line 31) and out-comment the other display definitions. Otherwise, define “DUMMYTFT” and out-comment the other display definitions.

Upload the data directory to SPIFFS using “Upload Filesystem Image” in the PlatformIO menu:
and upload the compiled program using “Upload” in the same menu.

Activate the serial monitor and reset the ESP32. Observe the debug output. Make a note of the IP address (search for line containing “IP:”), for example “192.168.2.33”. Start your Internet browser and go to this address.
Go to the configuration page and press the “Default” button. Edit the configuration here, set “pin_i2s_bck = 15”, “pin_i2s_din = 26” and “pin_i2s_lck”.

If the display is connected: make sure the lines with “pin_tft_cs = 2” and “pin_tft_dc = 4” are defined.
If the rotary encoder is mounted: make sure the lines with “pin_enc_clk = 12”, “pin_enc_dt = 14” and “pin_enc_sw = 13” are defined.

Press the “Save” button and after that press the “Restart” button”.

The output level of the PCM5102A may be a bit too high for a PAM5102. Solder 2 resistors of 12 Ohm on the PCM5102A module, one resistor between pin “G” and pin “L” and one between pin “G” and “R”.

4 Radio with hardware MP3 decoding and line output.

The MP3 conversion is done by hardware. A VS1053 module is used to deliver the analog output to a headphone or to an external amplifier.
4.1 Used components.
1. PBC. Available through PCBway.
2. ESP32 devkit V1. Available here. (https://nl.aliexpress.com/item/1005006450124383.html)

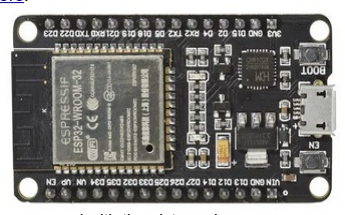
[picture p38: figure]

3. Note that the pin layout must correspond with the picture above.
4. A VS1053 module. Available here. (https://aliexpress.com/item/1005003081105203.html)

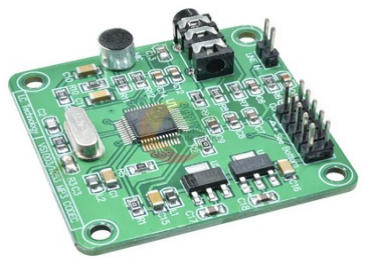
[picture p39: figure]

5. An electrolytic capacitor, 470 µF (220 µF or 100 µF will also work).
6. A 2 pin connector witch cable to your 5 Volt power supply. For example this. (https://nl.aliexpress.com/item/1005005961786030.html) Note that the distance between the pins is 2.54 mm.
The pins for +5 (red) and ground (black) may be reversed. Use a sharp pin to modify if necessary.
You may also directly solder the power lines to the print of course.
7. Female headers to mount the ESP32 and the VS1053. You may use 40 pin headers and cut them to be fitted. See here. (https://nl.aliexpress.com/item/4000873858801.html)
8. 2 x 100 k resistors. Not needed if you are not interested in reading the battery voltage.
9. Optional: a TFT display and/or a rotary encoder switch. See chapter 6.

4.2 Mounting instructions.

1. Prepare 2 15 pins female headers and solder them to the top side of the PCB. The position is marked with “ESP32-Devkit V1”. It helps if you put the headers on the ESP32 first in order to make the perfect alignment.
2. Mount the capacitor on the top side of the PCB. The position is marked “C2”. Align the minus side of the capacitor, marked with a white band to the right. The PCB is also marked on the right side.
3. Mount the power cable (and connector) on the top side of the PCB in the lower left corner. The position is marked “CN1”.
4. Mount the VS1053 upside down on the top side of the PCB. The position is marked “VS1053”. Use female headers (2 x 5 pins and one 2 pin header) on the side of the PCB. It helps to put the headers on the module first in order to make the perfect alignment.
5. The print will now look like this:
6.

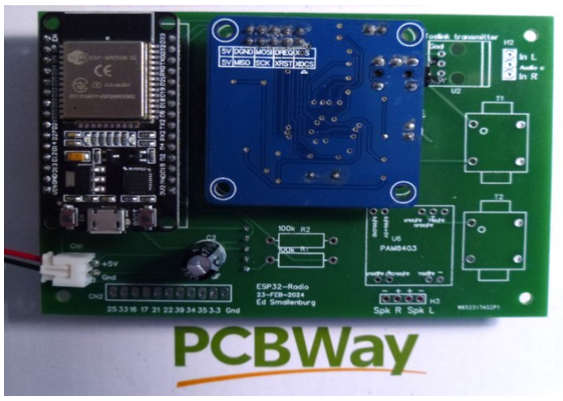
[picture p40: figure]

7. Optional: mount a TFT display and/or a rotary encoder. See chapter 6.
4.3 Testing.

Edit the config.h file. Set FIXEDWIFI (near line 17) to your SSID/PASSWORD of your WiFi network.
Define “DEC_VS1053” near line 22, out-comment the other “DEC_xxxx” definitions.
If the display is mounted, define “BLUETFT” (near line 31) and out-comment the other display definitions. Otherwise, define “DUMMYTFT” and out-comment the other display definitions.

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

Activate the serial monitor and reset the ESP32. Observe the debug output. Make a note of the IP address (search for line containing “IP:”), for example “192.168.2.33”. Start your Internet browser and go to this address.
Go to the configuration page and press the “Default” button. Edit the configuration here, make sure that “pin_i2s_spdif = 15” is defined.

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

Press the “Save” button and after that press the “Restart” button”.

5 Radio with hardware MP3 decoding, amplifier and speaker output.

The MP3 conversion is done by hardware. A VS1053 module is used to deliver the analog output to a headphone or to an external amplifier.
5.1 Used components.
1. PBC. Available through PCBway.
2. ESP32 devkit V1. Available here. (https://nl.aliexpress.com/item/1005006450124383.html)
3. Note that the pin layout must correspond with the picture above.
4. A VS1053 module. Available here. (https://aliexpress.com/item/1005003081105203.html)
5. A PAM8403 amplifier and 2 audio transformers (600/600 Ohm). Available here (https://nl.aliexpress.com/item/1005005750019298.html) and here. (https://aliexpress.com/item/32862222914.html)

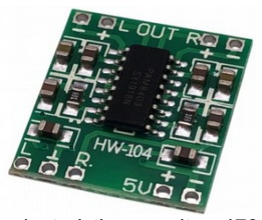
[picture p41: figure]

6. An electrolytic capacitor, 470 µF (220 µF or 100 µF will also work).
7. A 2 pin connector witch cable to your 5 Volt power supply. For example this. (https://nl.aliexpress.com/item/1005005961786030.html) Note that the distance between the pins is 2.54 mm.
The pins for +5 (red) and ground (black) may be reversed. Use a sharp pin to modify if necessary.
You may also directly solder the power lines to the print of course.
8. Female headers to mount the ESP32 and the VS1053. You may use 40 pin headers and cut them to be fitted. See here. (https://nl.aliexpress.com/item/4000873858801.html)
9. 2 x 100 k resistors. Not needed if you are not interested in reading the battery voltage.
10. Optional: a TFT display and/or a rotary encoder. See chapter 6.

5.2 Mounting instructions.

1. Prepare 2 15 pins female headers and solder them to the top side of the PCB. The position is marked with “ESP32-Devkit V1”. It helps if you put the headers on the ESP32 first in order to make the perfect alignment.
2. Mount the capacitor on the top side of the PCB. The position is marked “C2”. Align the minus side of the capacitor, marked with a white band to the right. The PCB is also marked on the right side.
3. Mount the power cable (and connector) on the top side of the PCB in the lower left corner. The position is marked “CN1”.
4. Mount the VS1053 upside down on the top side of the PCB. The position is marked “VS1053”. Use female headers (2 x 5 pins and one 2 pin header) on the side of the PCB. It helps to put the headers on the module first in order to make the perfect alignment.
5. Mount the PAM8403 and the 2 audio transformers on the top side of the print. The transformers are necessary because the audio common of the VS1053 is not at ground level.
6. The print will now look like this:

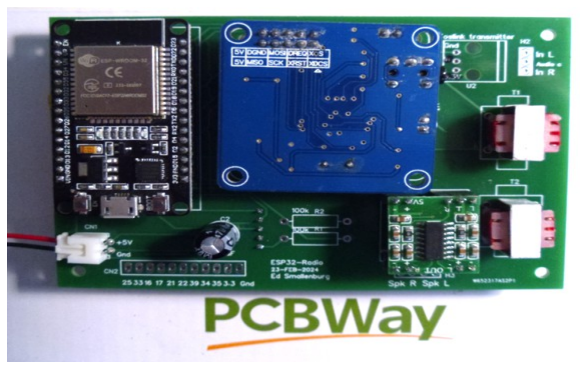
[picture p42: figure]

7. Prepare a cable with a 3.5 audio connector like this:

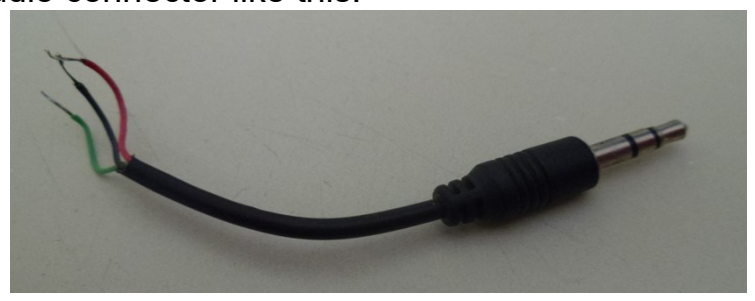
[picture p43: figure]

8. Solder the cable to the top side of the print, position is marked “H2”. The common wire is usually black and should be connected to “Audio c”. The audio plug must be put in the 3.5 mm of the VS1053.
9. Optionally mount the TFT display and/or the rotary switch. See chapter 6.
10. The print looks like this:
11.

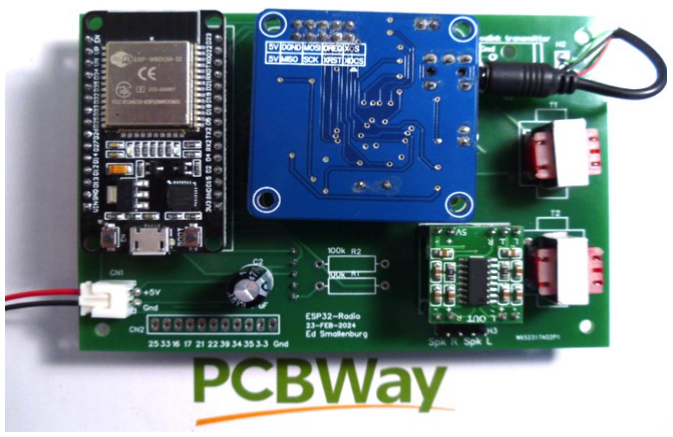
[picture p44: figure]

5.3 Testing.

Edit the config.h file. Set FIXEDWIFI (near line 17) to your SSID/PASSWORD of your WiFi network.
Define “DEC_VS1053” near line 22, out-comment the other “DEC_xxxx” definitions.
If the display is mounted, define “BLUETFT” (near line 31) and out-comment the other display definitions. Otherwise, define “DUMMYTFT” and out-comment the other display definitions.

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

Press the “Save” button and after that press the “Restart” button”.

6 Optional components.

6.1 Optional TFT display.

The TFT display is available here. (https://nl.aliexpress.com/item/1005005933459704.html) The PCB is designed for this display. If you want to use a different one, you may use extension wires to connect it. Use an 8 pin female header. Mount the display at the back side of the print. The position is marked “TFT1”. Use an 8 pin female header. Also mount the 2 100k resistors marked “R1” and “R2”. This allows to measure the input voltage and display the result on the display.
6.2 Optional rotary encoder.

A rotary encoder switch, type KY-040 is available here. (https://nl.aliexpress.com/item/4001115444623.html) The 5 pins are not very handy if you want to mount the decoder on the print. You may want to replace them with straight male pins and mount them on the other side of the encoder module. Mount the encoder on the back side of the print using a 5 pin female header. You may want to use extension wires like this (https://nl.aliexpress.com/item/1005005945668553.html) if you want to mount the encoder in a different position.
Without the rotary switch, the radio can be controlled by web interface and/or MQTT only.

After these 2 steps, the back side of the print looks like this:

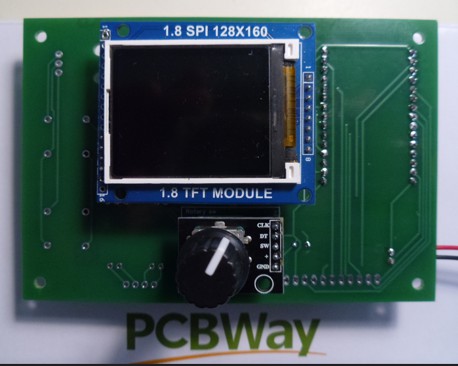
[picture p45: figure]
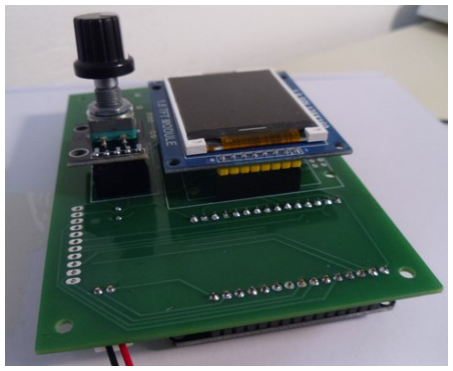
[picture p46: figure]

Note: On the rotary encoder module, there are 3 pull-up resistors. These are not necessary as the 3 ESP32 inputs already have a pull-up. In fact, the resistors may introduce some problems during program upload. So it may be better to remove them from the module.

6.3 Optional IR receiver.

With an IR receiver, the radio can be controlled by almost any IR remote controller. You have link the IR codes to radio functions in the config page of the web interface. You can find the codes in the serial debug output when you press a key on your remote control.
An IR receiver, type VS1838B can be found here. (https://nl.aliexpress.com/item/1744421410.html)
Prepare the VS1838B and a 3 pins female header like this:

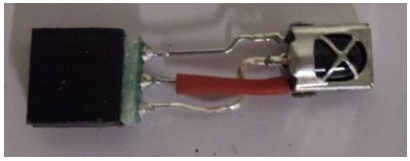
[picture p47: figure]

Mount this module on the top side of the print:

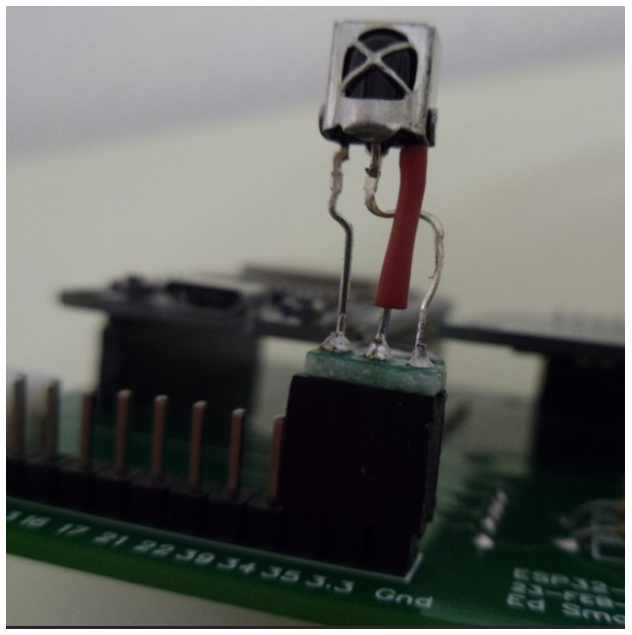
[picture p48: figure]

In this case pin 35 is used for the signal line of the receiver. Be sure that “pin_ir = 35” is defined in the config page of the web interface.

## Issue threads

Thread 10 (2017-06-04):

Button connection

lonelyjack, 2017-06-04:
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
is it right?

Edzelf, 2017-06-04:
There is no pull-up required for GPIO12.  At least not on a standard Dev Board.  A switch to GND is sufficient.  A pull-up does not harm either.

lonelyjack, 2017-06-04:
Out of the resistor, the diagram is right?

Edzelf, 2017-06-05:
Yes, try it and look at the debug logging at the serial output.

lonelyjack, 2017-06-08:
What about other GPIOs? 13,14,17,22,25,26,27,32,33? Is there no pull-up required?

Edzelf, 2017-06-08:
Try it, or read the documentation.

lonelyjack, 2017-06-08:
There's an empty fields in your overview for these pins

lonelyjack, 2017-06-13:
Well, it's rebooting without pull-ups

Edzelf, 2017-06-13:
Now, take a wire and ground pins 13, 14,17,.... one by one.  Watch the logging.

Edzelf, 2017-06-13:
If you mean "it keeps rebooting", then you have a weak power supply.  Add a big capacitor like 3300 microFarad between 5 Volt and ground.

Closed 2017-06-13.

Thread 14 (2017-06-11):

How to power without powerbank?

lonelyjack, 2017-06-11:
That's a great project, but when I power it with powerbank - it's ok, but when i try power it with samsung charger or ac/dc modules like these:
https://ru.aliexpress.com/item/AC-DC-5V-700mA-3-5W-Power-Supply-Buck-Converter-Step-Down-Module-for-Arduino/32395148959.html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
https://ru.aliexpress.com/item/Free-Shipping-1pcs-lot-HLK-PM01-AC-DC-220V-to-5V-mini-power-supply-module-intelligent/32408565688.html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
there's a big trouble. There's no sound or it's squashing

koskee, 2017-06-11:
What does your setup look like? I've had good results placing a mid to large sized electrolytic capacitor (~1000uF+, I use a 2200uF) across the power rails (5v and ground pins, observe polarity).
 The esp8266 was notoriously power hungry and would cause large spikes on the supply voltage/current, which would cause all kinds of weird behaviour in practice. I'm not sure if these chips are the same way, but a stable source of power can only be a good thing in terms of stability & clean output.

Also, Ive found that if the voltage level on the XRST pin of the 1053 board is not kept fairly stable, you'll start to get mpeg compression glitches showing up in the output. So, if the above doesn't help, if the output is still dodgy, try putting a capacitor between the EN/XRST pins and ground. I currently have a 4.7uF electrolytic that I'm using, but probably almost any value would be beneficial as there shouldn't be much fluctuation on these pins. My only advice here would be to keep it fairly small, maybe between 1uF and 47uF maximum. You may also see benefit in the sub uF range as well, you'll have to see what works for you

koskee, 2017-06-12:
Also, the charger specs shouldn't matter all that much, as I can run mine reliably from a computer usb port (usb is 500ma max) and this is shared between a few different peripherals (although I have noticed that mine will change to the next preset if I plug a flash drive into my computer while it's running on the USBs power so it's obviously not a lot of headroom)

lonelyjack, 2017-06-12:
koskee, I have not esp8266, I have esp32. I've placed 4700uf 10v electrolytic capacitor across the power rails of esp32 devboard, and the same one across the power rails of vs1053.  These capacicators don't cross with each other, because I'm powering these boards from different ports of powerbank.

koskee, 2017-06-13:
> koskee, I have not esp8266, I have esp32.

No, I understand, I was just saying that the esp32 could have a big appetite for power, depending whether espressif has done anything to change the fact.

I would suggest connecting the ground of the esp32 to the ground of the vs1053, however it's likely that the two separate powerbank  ports have a common ground internally. That is,  unless youre using more than one powerbank..

Based on your description of "squishing" the output, it sounds a lot like the same issue I was having. The only thing that actually seemed to work was placing a (smaller.. 1~100uF) capacitor between  the XRST pin on the vs1053 board -> ground. This will cause the voltage on this pin to stabilize as well as filter out some of the noise/fluctuations,  which essentially solved all of my issues. Im fairly confident it should work for you as well.

lonelyjack, 2017-06-14:
Thank you, I'll try. Capacicator between xsrt and ground should be electrolitic?

koskee, 2017-06-14:
Yeah,  that's what I'm using,  4.7uF electrolytic.

I'm guessing that just about any sort of cap would do the trick in this case, as all we're trying to do is to store a bit of power for the moments when the supply voltage takes a dive. The cap helps to hold that line @5V over any voltage sags (not for very long mind you, but that's all it should need for better output.)

Make sure to observe the correct polarity when using electrolytics though or they can pop and all the goop inside will leak out everywhere..

Let me know how it goes.

zajaklis, 2017-06-15:
dont use those rubbish power supplies, they cannot deliver more than 250ma

lonelyjack, 2017-06-17:
Koskee, thank you again. I've connected cap between xrst and gnd - all works fine. At first I used 4,7 uF, there was a little squash sometimes. Then I used 47uF - all is good.

arlaor, 2017-06-17:
Hi  @lonelyjack, @koskee, @Edzelf, @zajaklis
Can you please confirm if this project on the esp32 model is stable compared to the esp8266 module or have the same performance?

Edzelf, 2017-06-17:
Better stability.  Better performance.  More features.

koskee, 2017-06-18:
@arlaor
See here:  #https://github.com/Edzelf/Esp-radio/issues/92 (last comment at bottom)
The difference will absolutely amaze you. You'll likely wonder why you even bothered with the other version.

arlaor, 2017-06-18:
thanks @Edzelf  @koskee
I'm waiting for the arrival of a pair of wemos lolin.
This is a Excellent Project.

Closed 2017-06-19.

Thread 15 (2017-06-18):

On via vol+ after reset

ilioss, 2017-06-18:
Hi Ed,

Finnaly the TFT received and connected.
Meanwhile the 8266 replaced by the ESP32 changed  the software for the latest version.
Indeed the 32 looks like more stable. The 8266 I actualy didn,t get it working after all in combunation with the geeetech shield.( lots of so called "glitching" ) there is a signal and data but not understandeble.
In the same time I placed the capacitors across the 5 Vcc -gnd and betweeh XRST-gnd hopefully will this prevent problems with the power supply spikes.
During my playing/testing I noticed that after a reset from the config page I had to give vol+ a push to get sound again. Is this a known bug?
Also after I received my TFT I didn,t get it working. Connect as discribed and tested again. I changed the TFT_ILI963C.cpp file on line 1096/7
No result. Than the blue 1.8 SPI 128x160 board type I realy do not understand this Most problaby this is the key to get my display working. Do you have a clue?
Further more I realy enjoy this project and like to learn a lot not only from the esp32 also from networking etc. A realy nice step further than just arduino.
Greeting
Theo

Edzelf, 2017-06-18:
Your config should cantain something like "volume=76" and NOT "mute."
Try to get your display working without the vs1053 connected.

ilioss, 2017-06-18:
Hi,Ed thanks for your dwift anser.I will test the display without the 1053.Let you know.Regards,TheoOp 18 jun. 2017 6:37 p.m. schreef Ed Smallenburg <notifications@github.com>:Your config should cantain something like "volume=76" and NOT "mute."
Try to get your display working without the vs1053 connected.

—You are receiving this because you authored the thread.Reply to this email directly, view it on GitHub, or mute the thread.

ilioss, 2017-06-18:
Hi, All must be,

I tested the TFT display with the benchmark file as found in the ILI9163c zip and it works on a NANO.
A small stroke was not used!
Than I connect the display again to my radio and disconnect fully the VS1053( Alientek) no picture at all a clear white screen. Double checked the connections.
Compaired to the both files the benchmark.ino and the ESP32Radio.ino there is some slide difference in defining the CS and DC
 #define TFT_CS 15
#define TFT_DC 2  ESPRadio.ino ( yours so to say )

#define __CS 10
#define __DC 6   benchmark.ino

I.am not meaning the i/o number.

Can this make the difference?
What exactely you mean with the "bleu 1.8 SPI 128x160 board"  in your documentation?
I can only found a red or black board

I,am cont. to have my display working.
Your advise is highly appreciated.

Kind regards,
Theo

Edzelf, 2017-06-18:
I used this one: [https://www.aliexpress.com/item/Smart-Electronics-1-8-Inch-128-160-Serial-SPI-TFT-LCD-Module-Display-PCB-Adapter-Power/32597366825.html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](TFT).

Make sure your power supply is strong enough.  The ESP32 is very sensitive on this.
The GPIO pins are correct in the ESP32-Radio sketch.

ilioss, 2017-06-19:
Hi, all

Succes. I must admit it is fully my fault. As "penny wise pond foolish". I used a experiment pcb from a former project and some copper traces where still open D15 among them. This solved and tested my set-up and display gives nice data in full collor.
Now I have to find out if the power supply is 100% relaiable in combination with sufficient voltage and current, I,am using a 6 volt 400mA power supply 3.3 volts by a LD33VC 1amp, also related to the used capaciters.
I also have to check the volume setting as default mute is not the meaning.
Ed, many thanks for your support.
As far as I can check I have the same display as mentioned.
Kind regards,
Theo

So far So good I,am realy trilled by this project.

Closed 2017-06-26.

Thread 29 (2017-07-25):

Hick-up revision 19th July

ilioss, 2017-07-25:
Hi Ed,

Already long time not contacted. The radio play,s very well.( we only suffer from a really slow internet) as soon as we surf on the internet the radio looses some bits. Not the problem of the radio KPN lack,s "buitengebied"interest.
This evening I checked the site and sow a new revision dated 19th July.
So I installed and tested it. I must say I have the impression it became less stable. And starts up quit a bit slower.
Now my experience,
The operational error direct noticed was the channel operation.
On my system I have gpio13 vol+ gpio14 vol- , gpio26 channel+, gpio27 channel-, and gpio25 preset6
It is not possible to operate the channel via the pushbuttons once you have channel for instance 5 it is not possible to lower the channel. It looks like the only way is up and remains there.
After some tests I noticed that only after you pressed the "control" on the html page banner it will lower the channel.
An other thing. OTA seems not working on my system.
I tested it with the arduino basic OTA script and this is working.
So with the radio script it is not?
Not a big deal but I would like to feel the luxure to program the radio over the air while the radio and the esp32 is build in in a nice case.( no external possibility for the usb connector.)
The time indicater is a nice feature. Howe ever it looks like it is not always shown on the display.
The lower indicater banner showed preset 8 but I have only 0 till 7 programmed?? This is 8 but still.

The serial monitor gives the following: after I pressed the gpio27 for request lower channel
( it has worked perfectly )

push gpio27   I did.
Serial monitor showed,
GPIO27  is now low , executed down preset  =-1
command downpreset with parameter -1
preset is now 3
Stop request
Stopping client

( is it necessary to note  -1  for downpreset?  Volume is not like that it is just 2 for both up or down?
Like to hear.
ps. The radio is in our living-room operational. If the wife likes it it is ok. But if it has some unlogical hick-ups she will complain and I have to go to the shop I,am afraid.
We will see.
Kind regards,
Theo

ilioss, 2017-08-12:
Hi Ed,

Sorry no respond on my measage above. Still things are going on.
Hopefully I do not bther you with my issue's?
Due to bad weather I started to assamble my 2nd radio. All parts recieved.
Initially test fails. No display.
So what to do?
Again I checked all connections and so forth. Looks ok to me.
Loaded a previous version and now it worked all.
Not surprisingly while the 28-July version didn.t work on my system as well.
I installed also the rotary switch om 3.3 v ( I keep the radio at 3.3Volt true out in order to avoid mistakes somewhere some how. Look to me logic.)
The switch didn,t function on my new radio with the sw revision of 28-07.
So, I have my first radio running on the previous sw version not the latest.
My new radio loaded with the 28-07 version.
Status:
see serial print out.
First what seems to me looks strange is direct on top of the list I see that parameters are with pin set to xxx -1???  What can course that?
My programmed buttons for vol+ and vol- and preset  station are working.
What still not will work is the SD card and the display:
The vs1053 woorks pretty well.

Ed my new radio I would like to use as MP3 player as well to be able to insert the SD card I must rotate the display. No problem parameter from 3 to 1 looks logical to me and so I did and with succes the display is 180 dgr. rotated. But the offset from the originated point seems to be wrong the text start not exact at the beginning of the display but some where 30 or so pixels from the left??
Any ideer where to adjust this one?
I already had a look in the FTFXXX.setting.h file and the lib but no succes.

Hope to have some responce.
Kind regards,
Theo

ps. I will have a look in the other SD card issue

rst:0x10 (RTCWDT_RTC_RESET),boot:0x17 (SPI_FAST_FLASH_BOOT)
configsip: 0, SPIWP:0x00
clk_drv:0x00,q_drv:0x00,d_drv:0x00,cs0_drv:0x00,hd_drv:0x00,wp_drv:0x00
mode:DIO, clock div:1
load:0x3fff0008,len:8
load:0x3fff0010,len:160
load:0x40078000,len:10632
load:0x40080000,len:252
entry 0x40080034

D: Starting ESP32-radio Version Fri, 28 Jul 2017 12:05:00 GMT...  Free memory 194940
D: ir_pin pin set to -1
D: enc_clk pin set to -1
D: enc_dt pin set to -1
D: enc_sw pin set to -1
D: tft_cs pin set to -1
D: tft_dc pin set to -1
D: sd_cs pin set to -1
D: vs_cs pin set to -1
D: vs_dcs pin set to -1
D: vs_dreq pin set to -1
D: GPIO0 is HIGH
D: GPIO1 is HIGH
D: GPIO2 is LOW, probably no PULL-UP
D: GPIO3 is HIGH
D: GPIO4 is HIGH
D: GPIO5 is HIGH
D: GPIO12 is HIGH
D: GPIO13 is HIGH
D: GPIO14 is HIGH
D: GPIO15 is HIGH
D: GPIO16 is HIGH
D: GPIO21 is HIGH
D: GPIO22 is HIGH
D: GPIO25 is HIGH
D: GPIO26 is HIGH
D: GPIO27 is HIGH
D: GPIO32 is HIGH
D: GPIO33 is HIGH
D: GPIO34 is LOW, probably no PULL-UP
D: GPIO35 is LOW, probably no PULL-UP
D: GPIO12 will execute enc_sw
D: GPIO13 will execute upvolume = 2
D: GPIO14 will execute downvolume = 2
D: GPIO25 will execute preset = 6
D: GPIO26 will execute uppreset = 1
D: GPIO27 will execute downpreset = 1
D: GPIO32 will execute enc_dt
D: GPIO33 will execute enc_clk
D: SD Card Mount Failed!
D: Added Leeuwarderweg29wifi to list of networks
D: Added Leeuwarderweg29 to list of networks
D: Scan Networks
D: Scan completed
D: Number of available networks: 2
D:  1 - Leeuwarderweg29           Signal: -46 dBm, Encryption WPA_WPA2_PSK, Acceptable
D:  2 - Leeuwarderweg29wifi       Signal: -74 dBm, Encryption WPA_PSK, Acceptable
D: End of list
D: Command: mqttbroker with parameter none
D: Command: mqttport with parameter 1883
D: Command: mqttuser with parameter none
D: Command: mqttpasswd with parameter ******
D: Command: volume with parameter 72
D: Command: toneha with parameter 4
D: Command: tonehf with parameter 7
D: Command: tonela with parameter 11
D: Command: tonelf with parameter 13
D: Command: preset with parameter 6
D: Command: clk_server with parameter pool.ntp.org
D: Command: clk_offset with parameter 1
D: Command: clk_dst with parameter 1
D: Slow SPI, Testing VS1053 read/write registers...
D: Fast SPI, Testing VS1053 read/write registers again...
D: endFillByte is 0
D: Connect to WiFi
D: Connected to Leeuwarderweg29
D: IP = 192.168.2.15
D: Start server for commands
D: Rotary encoder is enabled
D: STOP requested
D: Song stopped correctly after 0 msec
D: New preset/file requested (6/0) from icecast.omroep.nl/radio6-bb-mp3
D: Connect to new host icecast.omroep.nl/radio6-bb-mp3
D: Connect to icecast.omroep.nl on port 80, extension /radio6-bb-mp3
D: Connected to server
D: Switch to HEADER
D: Server: Icecast 2.4.2
D: Content-Type: audio/mpeg
D: audio/mpeg seen.
D: Cache-Control: no-cache
D: Expires: Mon, 26 Jul 1997 05:00:00 GMT
D: Pragma: no-cache
D: icy-br:192
D: ice-audio-info: samplerate=48000;channels=2;bitrate=192
D: icy-br:192
D: icy-genre:Soul & Jazz
D: icy-metadata:1
D: icy-name:NPO Soul&Jazz
D: icy-pub:0
D: icy-url:http://www.nposoulenjazz.nl/
D: icy-metaint:16000
D: Switch to DATA, bitrate is 192, metaint is 16000
D: First chunk:
D: D3 86 1E 22 61 4B 6A 7A
D: 65 E5 3A 55 9D 77 38 4E
D: E1 2D 59 FB 2F A8 0D A5
D: 8E 18 E8 8A 0D A1 BF C9
D: Metadata block 64 bytes
D: Streamtitle found, 48 bytes
D: StreamTitle='NPO Soul & Jazz - Non-stop - VPRO';

Edzelf, 2017-08-12:
In the new version you have to provide the pinnumber that you use for TFT, VS105, etc.  in the preverences.  See the documentation and the new default settings in the web interface.  I will check the 180 degrees display later.

Edzelf, 2017-08-12:
In the new version of the software, you have to provide the pinnumbers for TFT, VS1053, ... in the preferences like this:
```
vs_cs = 5                                            # GPIO Pin number for VS1053 "CS"
vs_dcs = 16                                          # GPIO Pin number for VS1053 "DCS"
vs_dreq = 4                                          # GPIO Pin number for VS1053 "DREQ"
```
Read the documentation.  I will look into the 180 degrees rotation of the TFT.

Edzelf, 2017-08-12:
180 degrees works perfect on my hardware.  I quess you are using an unpatched version of the TFT library.  Read the documentation under "TFT library patches".

ilioss, 2017-08-12:
Hi Ed,

Thanks for your swift reply.
Yes, I will check the preference list.
In the mean time I was able to have some SD card function. It appeared that I get the music files from the sd card. How ever no song names. In the html page from inderx I get the songnames by pressing the status.
So it looks like there is some progres.
I keep you informed.
Kind regards,
Theo

Thanks again very preciated.

Edzelf, 2017-08-12:
The only info for mp3-files on SD is the filename.

ilioss, 2017-08-12:
Hi Ed,

Thanks for your answer.
I patched up the preferences and the lines at the start of the list ( serial printout ) are now corresponding the gpio. Thats fixed.
I get the radio working to start it I had to push several times on the switch from the rotary encoder.
The SD is also giving his secrets to me the songs name is given and also the number of songs.
I made really nice progress.
Question the SD was resently under revision by ladyada where is the new sd lib. to find. Also the patch for the TFT?
Like to hear.
Kind regards

Theo

Edzelf, 2017-08-13:
Just copy the last version of the ESP32 Arduino Core libraries to your PC.  The patch for the TFT is decribed in the documentation of ESP32-Radio.

ilioss, 2017-08-16:
Hi All,
Most issues solved.
Due to support from Ed.
So case closed.
Kind regards.
Theo

Closed 2017-08-16.

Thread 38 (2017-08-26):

Using D-duino32, Wemos 32 with built-in LCD

fenyvesi, 2017-08-26:
I tried the ESP8266 version also, it is excellent.
I'd use the ESP32 verison now and I have some modules with built-in I2C OLED.
I have this one:
[https://www.aliexpress.com/snapshot/0.html?productId=32807483723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](url)

Unfortunately the number of exposed pins is minimal and stupid a bit. The PINs you used for SPI are not exposed.

The question: Can I use another set of SPI PINs (not the standard VSPI)  in Arduino?
I tried:
SPI.begin(12,13,14); without success.

I checked the connections, seems to be OK.
Do you have any idea/advice?

Thank you.

George
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

Edzelf, 2017-08-26:
SPI should work with different pins.
The header file shows:
void begin(int8_t sck=SCK, int8_t miso=MISO, int8_t mosi=MOSI, int8_t ss=-1);

fenyvesi, 2017-08-26:
Yeah. I checked myself there.
The result:
D: Slow SPI, Testing VS1053 read/write registers...
D: VS1053 error retry SB:0000 R1:0773 R2:E730
D: VS1053 error retry SB:012C R1:0000 R2:0000
D: VS1053 error retry SB:0258 R1:0000 R2:FFFF
D: VS1053 error retry SB:0384 R1:0000 R2:0000
D: VS1053 error retry SB:04B0 R1:0000 R2:0003
.....

fenyvesi, 2017-08-28:
Just for the records, a working setup:

vs_sck  = 14                                         # GPIO Pin number for VS1053 SCK
vs_miso	= 12                                     # GPIO Pin number for VS1053 MISO
vs_mosi	= 13                                     # GPIO Pin number for VS1053 MOSI
vs_cs = 15                                            # GPIO Pin number for VS1053 "CS"
vs_dcs = 16                                          # GPIO Pin number for VS1053 "DCS"
vs_dreq = 2                                          # GPIO Pin number for VS1053 "DREQ"

SPI.begin(vs_sck,vs_miso,vs_mosi);

Edzelf, 2017-08-28:
SPI pins are now configurable in the preferences.

fenyvesi, 2017-08-29:
Thank you.

In oreder to modify the program because of the different OLED scrren, PINs etc. I had to look through it.
I must say that the richness of functionality, the clear structure, the comments, in one word the quality is admirable.

I can't even estimate the effort you took.

Thank you once more.

George

fenyvesi, 2017-08-29:
One more additon: I included mDNS responder in order not to check the IP on the screen.

fenyvesi, 2017-08-31:
Just a question. You use a different VS1053 module as mine. Can you connect
the amplifier directly or did you use a separate driving?

<http://www.avg.com/email-signature?utm_medium=email&utm_source=link&utm_campaign=sig-email&utm_content=webmail>
Mentes
a vírusoktól. www.avg.com
<http://www.avg.com/email-signature?utm_medium=email&utm_source=link&utm_campaign=sig-email&utm_content=webmail>
<#DAB4FAD8-2DD7-40BB-A1B8-4E2AA1F9FDF2>

On Mon, Aug 28, 2017 at 7:54 PM, Ed Smallenburg <notifications@github.com>
wrote:

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

Edzelf, 2017-08-31:
I do not know what kind of module you have.  But disconnect the amplifier and meassure the voltage on the 3 pins of the audio connector with respect to GND.  If this is not 0 Volt (I expect 1.25 V), then you cannot connect an amplifier that shares the GND with the VS1053 circuit.  A separate power supply for the amplifier is necessarary.  See the amplifier circuit in the documentation.

fenyvesi, 2017-08-31:
I’ve already checked and this is the bare „floating” ground of VS1053. I need a passive driving circuit.
The module you use is dirrerent and I see on Aliexpress that it is called line-out several times.
So the question that do you connect the output of your module directly to the amplifier?
( Does your module consist of the driving circuit for line-in?)

George

Küldte a Windows 10 Posta

Feladó: Ed Smallenburg
Elküldve: 2017. augusztus 31., csütörtök 13:51
Címzett: Edzelf/ESP32-Radio
Másolatot kap: George Fenyvesi; State change
Tárgy: Re: [Edzelf/ESP32-Radio] Using D-duino32, Wemos 32 with built-in LCD(#38)

I do not know what kind of module you have. But disconnect the amplifier and meassure the voltage on the 3 pins of the audio connector with respect to GND. If this is not 0 Volt (I expect 1.25 V), then you cannot connect an amplifier that shares the GND with the VS1053 circuit. A separate power supply for the amplifier is necessarary. See the amplifier circuit in the documentation.
—
You are receiving this because you modified the open/close state.
Reply to this email directly, view it on GitHub, or mute the thread.

---
Az e-mailen az AVG vĂ­rusellenĹ‘rzĂ©st vĂ©gzett.
http://www.avg.com

Edzelf, 2017-08-31:
Yes, connect the 3 lines of the ouput connector to:
Common - ground of the amplifier and the ground of the 2nd power supply.
L - to the amplifiers left input
R - to the amplifier right input

Closed 2017-08-30.

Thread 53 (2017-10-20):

Sound Distortion

MMSchneider, 2017-10-20:
Hello,

I am facing distortion on some radio stations. I am not sure if this is because of cabeling (other stations work fine), the station itself or the bitrate. An example stream which causes trouble is: swr-swr3-live.cast.addradio.de/swr/swr3/live/mp3/128/stream.mp3

Here a excerpt of the log:

D: New preset/file requested (12/0) from swr-swr3-live.cast.addradio.de/swr/swr3/live/mp3/128/stream.mp3
D: Connect to new host swr-swr3-live.cast.addradio.de/swr/swr3/live/mp3/128/stream.mp3
D: Connect to swr-swr3-live.cast.addradio.de on port 80, extension /swr/swr3/live/mp3/128/stream.mp3
D: Connected to server
D: Switch to HEADER
D: Headerline: Content-Type: audio/mpeg
D: audio/mpeg seen.
D: Headerline: icy-description:Mehr Hits. Mehr Kicks. Einfach SWR3
D: Headerline: icy-genre:Pop Music
D: Headerline: icy-name:SWR3
D: Headerline: icy-pub:1
D: Headerline: icy-url:http://www.swr3.de
D: Headerline: Server: dg-swr-http_dus-dtag_edge_1c578a1c46f2c8ca01cf246adf834ac5
D: Headerline: Cache-Control: no-cache, no-store
D: Headerline: Access-Control-Allow-Origin: *
D: Headerline: Access-Control-Allow-Headers: Origin, Accept, X-Requested-With, Content-Type
D: l-Allow-Headers: Origin, Accept, X-Requested-With, Content-Type seen.
D: Headerline: Access-Control-Allow-Methods: GET, OPTIONS, HEAD
D: Headerline: Connection: Close
D: Headerline: Expires: Mon, 26 Jul 1997 05:00:00 GMT
D: Headerline: icy-metaint:16000
D: Switch to DATA, bitrate is 0, metaint is 16000
D: First chunk:
D: FF FB 94 60 C2 80 03 0E
D: 40 5B CB 0B 1A EA 43 61
D: AB 8D 2D 2B 37 0E 71 33
D: 69 2C 3D 0D A9 22 19 AE
D: Metadata block 48 bytes
D: Streamtitle found, 35 bytes

I can see that there is no icy-br:XXX at all. Can that cause the distortion?

Thanks in advance
Mike

derpicknicker1, 2017-10-20:
Works fine for me.

Edzelf, 2017-10-20:
Sound quality is good, but I do hear some short breaks (average about 2 per minute).  @Mike: is that the distortion you experience?
This can be heard during the handling of the "streamtitle" in the data stream.  The streamtitles is included in the datas tream very often for this station.  In my setup this streamtitle is transmitted to my mqtt server, which also takes some time to handle.
I changed the configuration (mqttbroker = none).  That makes no difference.
Then I changed the configuration to "no TFT".  That also makes no difference.
The conclusion sofar is that there must be some code error in the handling of the streamtitle.
I will test this later.

MMSchneider, 2017-10-21:
@Edzelf not quite. It is really like over-amplified and like saturation. But since @derpicknicker1 does not have this issue, I sense that it may come from the ESP32 <--> VS1053 SPI connection. Maybe I do not get enough throughput. Interestingly 64kBit Streams do not have this issue. I will replace cables and make them shorter. Lets see.

AND: @Edzelf -> Thanks for this outstanding piece of Code!

koskee, 2017-10-31:
Sounds pretty good to me too, but like Ed said, the stream has a few hiccups once in a while...

Another thing you might want to look into is noise on your power supply. Sharing a supply with other devices has caused me issues similar to what you're describing in the past.
I've noticed that if I am powering from the USB bus on my laptop, and I plug in another device alongside the radio, I have on occasion got a volume spike/over saturated sound which lasts until manually rebooting the device. After that it is no problem.

You could try beefing up your power supply filter, either by adding more uF (maybe try doubling it) or by adding small ceramic capacitors of various values (for example, 1nF, 10nF, 100nF, 1uF and anything in between. The more, the better) The small ceramic caps serve to filter out specific frequencies, so if you can hit the correct value for any noise you may be encountering, it should filter it out. There's a formula you can use if you know the frequency, but you'd need an oscilloscope to quantify it.

A much simpler approach might be to try a different PS, one rated for a at least 1A, and only attach the radio (if you had other things connected).

Just some food for thought.

MMSchneider, 2018-01-21:
SOLVED - Just want to mention that the distortion has gone after replacing the wires between ESP32 and VS1053. Seems that a good connection is key.
Thanks for all the help.

Closed 2018-01-21.

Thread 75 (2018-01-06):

VS1053 not properly installed!

AST-esp-rasp, 2018-01-06:
Hello after checking twice the connection and using a second VS1003/1053 Module i stil get the error message "VS1053 not properly installed!"
Is there any known reason?
Do i have to pull up / down some of the GPIO ports connected to the Decoder module?
k.r.
Andreas

Edzelf, 2018-01-06:
Is the reset  line high?

AST-esp-rasp, 2018-01-06:
found the problem at least the program is running now.

was due to missing settings for the
#define VS1053_CS     5
#define VS1053_DCS    16
#define VS1053_DREQ   4
because i have used the esp32_radio_init.ino before and my preferences there did not set the definitions
Is this esp32_radio_init.ino still necessary? or does the normal program working without previously using it?
But now i get some noise out of my headphones but it sounds shredded

Edzelf, 2018-01-06:
The init sketch is only necessary to allow the webinterface to work.  The pins must be set in the preferences.

AST-esp-rasp, 2018-01-06:
okay found it was a broken gnd cable everything works now

some89, 2018-11-06:
hi, any other posibilitis for this fault? I have chcked every connection and rebuild it 3 times.

I have only the vs1053 connected nothing else. the reset pin is at 3.8V

the wifi also does not connect, does it connect after verifing the vs1053 board?

D: Slow SPI, Testing VS1053 read/write registers...
D: VS1053 not properly installed!
D: Connect to WiFi
Guru Meditation Error: Core  1 panic'ed (LoadProhibited). Exception was unhandled.
Core 1 register dump:
PC      : 0x400e080f  PS      : 0x00060630  A0      : 0x800d2c06  A1      : 0x3ffb1e50
A2      : 0x0000001c  A3      : 0x3f401317  A4      : 0x3ffca3a8  A5      : 0x3ffb1e8c
A6      : 0x00000000  A7      : 0x00000000  A8      : 0x800e080f  A9      : 0x3ffb1e10
A10     : 0x0000001b  A11     : 0x0000001c  A12     : 0x3f401317  A13     : 0x3ffb1ed0
A14     : 0x3ffb1e50  A15     : 0x00000008  SAR     : 0x00000008  EXCCAUSE: 0x0000001c
EXCVADDR: 0x00000000  LBEG    : 0x400014fd  LEND    : 0x4000150d  LCOUNT  : 0xfffffffb

Backtrace: 0x400e080f:0x3ffb1e50 0x400d2c03:0x3ffb1ef0 0x400d3ac9:0x3ffb1f10 0x400da06c:0x3ffb1f30 0x4013bffb:0x3ffb1fa0

Rebooting...

Edzelf, 2018-11-06:
Try to run without any wites attached.  It should connect to WiFi then.  Show me the logging.

some89, 2018-11-06:
No luck

this is just the uploaded  ESP32 radio skatch, the init skatch was left untouched. I have added my wifi login under defultprefs.

this is esp32 without anything

Rebooting...
ets Jun  8 2016 00:22:57

rst:0xc (SW_CPU_RESET),boot:0x13 (SPI_FAST_FLASH_BOOT)
configsip: 0, SPIWP:0xee
clk_drv:0x00,q_drv:0x00,d_drv:0x00,cs0_drv:0x00,hd_drv:0x00,wp_drv:0x00
mode:DIO, clock div:1
load:0x3fff0018,len:4
load:0x3fff001c,len:952
load:0x40078000,len:6084
load:0x40080000,len:7936
entry 0x40080310

D: Starting ESP32-radio running on CPU 1 at 240 MHz.  Version Thu, 04 Oct 2018 07:22:32 GMT.  Free memory 233608
D: Display type is NEXTION
D: Partition nvs found, 20480 bytes
D: Read 31 keys from NVS
D: pin_ir set to -1
D: pin_enc_clk set to -1
D: pin_enc_dt set to -1
D: pin_enc_sw set to -1
D: pin_tft_cs set to -1
D: pin_tft_dc set to -1
D: pin_tft_scl set to -1
D: pin_tft_sda set to -1
D: pin_tft_bl set to -1
D: pin_tft_blx set to -1
D: pin_sd_cs set to -1
D: pin_vs_cs set to -1
D: pin_vs_dcs set to -1
D: pin_vs_dreq set to -1
D: pin_shutdown set to -1
D: pin_shutdownx set to -1
D: pin_spi_sck set to 18
D: pin_spi_miso set to 19
D: pin_spi_mosi set to 23
D: GPIO0 is HIGH
D: GPIO2 is HIGH
D: GPIO4 is HIGH
D: GPIO5 is HIGH
D: GPIO12 is HIGH
D: GPIO13 is HIGH
D: GPIO14 is HIGH
D: GPIO15 is HIGH
D: GPIO16 is HIGH
D: GPIO17 is HIGH
D: GPIO18 is LOW, probably no PULL-UP
D: GPIO19 is HIGH
D: GPIO21 is HIGH
D: GPIO22 is HIGH
D: GPIO23 is HIGH
D: GPIO25 is HIGH
D: GPIO26 is HIGH
D: GPIO27 is HIGH
D: GPIO32 is HIGH
D: GPIO33 is HIGH
D: GPIO34 is LOW, probably no PULL-UP
D: GPIO35 is LOW, probably no PULL-UP
D: GPIO39 is LOW, probably no PULL-UP
D: gpio_00 will execute uppreset = 1
D: gpio_12 will execute upvolume = 2
D: gpio_13 will execute downvolume = 2
D: Create list with acceptable WiFi networks
D: Added XUK5 to list of networks
D: Added ADSL to list of networks
D: End adding networks
D: Scan Networks
D: Scan completed
D: Number of available networks: 2
D:  1 - T-2_40cb2b                Signal: -55 dBm, Encryption WPA_WPA2_PSK,
D:  2 - XUK5                      Signal: -70 dBm, Encryption WPA2_PSK, Acceptable    **this is the added network wifi_00**
D: End of list
D: Command: clk_dst with parameter 1
D: Command: clk_offset with parameter 1
D: Command: clk_server with parameter pool.ntp.org
D: Command: gpio_00 with parameter uppreset = 1
D: Command: gpio_12 with parameter upvolume = 2
D: Command: gpio_13 with parameter downvolume = 2
D: Command: mqttbroker with parameter none
D: Command: mqttpasswd with parameter *******
D: Command: mqttport with parameter 1883
D: Command: mqtttpreset with parameter none
D: Command: mqttuser with parameter none
D: Command: preset with parameter 6
D: Command: preset_00 with parameter 109.206.96.34:8100
D: Command: preset_01 with parameter airspectrum.cdnstream1.com:8114/1648_128
D: Command: preset_02 with parameter us2.internet-radio.com:8050
D: Command: preset_03 with parameter airspectrum.cdnstream1.com:8000/1261_192
D: Command: preset_04 with parameter airspectrum.cdnstream1.com:8008/1604_128
D: Command: preset_05 with parameter us1.internet-radio.com:8105
D: Command: preset_06 with parameter icecast.omroep.nl:80/radio1-bb-mp3
D: Command: preset_07 with parameter 205.164.62.15:10032
D: Command: preset_08 with parameter skonto.ls.lv:8002/mp3
D: Command: preset_09 with parameter 94.23.66.155:8106
D: Command: preset_10 with parameter ihr/IHR_IEDM
D: Command: preset_11 with parameter ihr/IHR_TRAN
D: Command: toneha with parameter 0
D: Command: tonehf with parameter 0
D: Command: tonela with parameter 0
D: Command: tonelf with parameter 0
D: Command: volume with parameter 72
D: Slow SPI, Testing VS1053 read/write registers...
D: VS1053 not properly installed!
D: Connect to WiFi
Guru Meditation Error: Core  1 panic'ed (LoadProhibited). Exception was unhandled.
Core 1 register dump:
PC      : 0x400e080f  PS      : 0x00060630  A0      : 0x800d2c06  A1      : 0x3ffb1e50
A2      : 0x0000001c  A3      : 0x3f401317  A4      : 0x3ffca3a8  A5      : 0x3ffb1e8c
A6      : 0x00000000  A7      : 0x00000000  A8      : 0x800e080f  A9      : 0x3ffb1e10
A10     : 0x0000001b  A11     : 0x0000001c  A12     : 0x3f401317  A13     : 0x3ffb1ed0
A14     : 0x3ffb1e50  A15     : 0x00000008  SAR     : 0x00000008  EXCCAUSE: 0x0000001c
EXCVADDR: 0x00000000  LBEG    : 0x400014fd  LEND    : 0x4000150d  LCOUNT  : 0xfffffffb

Backtrace: 0x400e080f:0x3ffb1e50 0x400d2c03:0x3ffb1ef0 0x400d3ac9:0x3ffb1f10 0x400da06c:0x3ffb1f30 0x4013bffb:0x3ffb1fa0

Rebooting...

Edzelf, 2018-11-06:
Add your wifi credentials to the init-sketch and run it once.
Changing defaultpresf has no effect at this stage.  It is only used in the config page of the webinterface.

trombose009, 2020-09-03:
I have this issue:
`
D: Scan Networks
D: Scan completed
D: Number of available networks: 2
D:  1 - dampfmaschine2            Signal: -73 dBm, Encryption WPA2_PSK,
D:  2 - fritzboxdampf             Signal: -83 dBm, Encryption WPA_WPA2_PSK,
D: End of list
D: Slow SPI, Testing VS1053 read/write registers...
D: VS1053 not properly installed!
D: Start CH376
`

I did upload the init ino with wifi credentials.
Then it shows me:
"ESP32_radio_init completed..."

Then I uploaded the main file and I got this output. I have no display so I set it to dummy.
The ESP does not appear in the list of DHCP devices at my router.

Any Ideas?

Closed 2018-01-06.

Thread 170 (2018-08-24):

Some oddities using a  2.8"TFT

JeanRenier, 2018-08-24:
Hi,

Let me first thank you for sharing this really amazing piece of software engineering.

I made a little PCB combining the ESP32 VROOM, the VS1053 module, a 2.8"TFT module based on the ILI9341 chip and a few other bits to make the whole work.  It seems to work quite all right.
I modified your software a very little bit (starting from the August 6 release) in order to accommodate the XTP2046 touch screen hardware, just a few simple things for now: setting the volume and up/down preset.   I also enlarged the text size and the bargraphs for the volume and the battery charge, to improve the visibility.

A few oddities were noted, all of them have to do with the ILI9341 (or so I believe):
- whenever a file is selected from the SD card the TFT screen becomes blank (and stays also even if an Internet station is selected afterwards) until a hard reset, note that the back light is still working.
- the right part of the bargraph for the battery charge (the one that is written last I think) seems to be gradually (in less than 1s) overwritten by random pixels, as if the TFT would not haven been deselected.
Temporarily eliminating the touch screen lines in the code do no seem to change anything.  Any thoughts on this to help me further would be greatly appreciated.

Many thanks and all the best,  Jean Renier.

Edzelf, 2018-08-24:
It looks like the display is not deselected correctly.  This problem is reported more than once.  I was not able to reproduce it however.  Sometimes it helps if CS of the display was connected to a different GPIO pin.

JeanRenier, 2018-08-29:
Hi,
Back home now and having had the opportunity to put an oscilloscope probe to the tft_cs_pin (GPIO15).
This issue is very much the same as reported in issue 100.  The tft_cs_pin is driven low for very much all the time, leaving the TFT wide open.  Every second the TOD, battery level, ... updates will end by drive the pin high as it should, but after a short while (anything from 1ms ...200ms) the pin will be driven low again without apparent reason.  The phenomenon starts about immediately after the message with the IP address is displayed, i.e. there is no problems until an IP connection exists.  This points indeed to some obscure issue in Espressif's WiFi / IP handling software (ancient remains of a debugging aid ?).
Contrary as was reported, upgrading to the newest version of the ESP32 board manager (1.0.0) in the Arduino IDE didn't solve the problem for me.  I have included a write rectangle routine of just one pixel in a corner, this seems to eliminate at least the visual effect of this issue.  I may change the assignment of the tft_cs_pin in future, but this is not an easy thing on a PCB.
Since this issue has nothing to do with the ESP32-Radio software I propose to close it.
Many thanks all the best,  JeanRenier

Closed 2018-08-29.

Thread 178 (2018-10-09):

Wrong semicolon in Esp32_radio.ino?

xaziwb, 2018-10-09:
Function claimSPI
Line: while ( xSemaphoreTake ( SPIsem, ctry ) != pdTRUE ) ; // Claim SPI bus
Is the semicolon OK?

Edzelf, 2018-10-09:
You are right.  Fixed.

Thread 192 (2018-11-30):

Rotary encoder question.

paysan18, 2018-11-30:
My rotary encoder does not work. However the push button works.
I can see the action of the push button in the debug serial output.
But when I rotate the encoder nothing comes out in the trace.

I tried a little standalone prog and all looks ok with this encoder. Same pins used.
By looking at the code I have some questions.

1. Pins are not defined in the Esp-radio-init sketch. Why not?

2. If I press the config button I see  them configured as pin 25, 26 and 27. So this looks good.
    Where does this come from? From the progpin_struct?

3. What do the different fields mean in the struct progpin_struct?

Rainer-G, 2018-11-30:
Do you still have the interrupts occuring without moving the encoder ?
I had the same problem and found that if the interrupts come very fast, a rotation will not be detected.
I put this :
      tftset( 3, dbgprint( "Timer %5d %3d", enc_inactivity, rotationcount  )) ;

at the start of chk_enc for a test and found that enc_inactivity never was above 3 or 4 so it was reset by the interrupt routine         

Gesendet von Mail für Windows 10

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

paysan18, 2018-11-30:
Rainer, the interrupts did not come from the rotary encoder pins but from the pushbutton pin. I solderred a capacitor to GND on this pin and all works fine now.
But the rotary is still dead.
Wim

Rainer-G, 2018-11-30:
Wim,
for my information :
when you do a double or triple click and then no further action, will the display return to the text it was before the clicks ?
If it does, no unexpected interrupts ocurr on enc data and clock.
Rainer

Gesendet von Mail für Windows 10

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

paysan18, 2018-11-30:
Rainer, I have no display attached. But the messages came in the serial debug trace without I touched anything. But like I told you, just from the switch.
The rotary is still dead.
During the bootup trace I see the line Rotary encoder enabled.

Rainer-G, 2018-11-30:
Hello Wim,

the trace show a single click even on very short clicks, that’s you can see random interrupts without any action.
Rotary counts are only shown at stable situations ( debouncing, look at the interrupt routine ) so spurious interrupts may not be seen.

Just for a test, try

      dbgprint( "Timer %5d ", enc_inactivity  ) ;  in chk_enc, this works without display using the serial monitor.

If the counter goes above 40, there are definitely no interrupts on data and clock!
Or, if not done so far, add capacitors similar to the enc sw!

Cheers, Rainer

Gesendet von Mail für Windows 10

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

paysan18, 2018-11-30:
Rainer, I placed the line just after the curly bracket "{" in the chk_enc.
Now when I watch the debug output I see the counter increasing. When I turn the knob the counter resets and starts from zero. This means at least that the rotary is working. But is your line at the right place?

paysan18, 2018-11-30:
It’s strange that the counter reacts to the rotation of the encoder but the program does not.
Indication in the trace file and no in or decrease of the volume.

When the button is pressed 3 times the system hangs because the SD card will be opened. This does not work. The only way to get out of this is a reboot.

Groeten, Wim

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

Edzelf, 2018-11-30:
Maybe you should use Rainer's PCB....

paysan18, 2018-11-30:
Yes, good idea!

Groeten, Wim

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

paysan18, 2018-11-30:
Rainer, can I see a picture of your print for this radio please?

Rainer-G, 2018-12-01:
Here it is, Wim!

It uses different boards, I selected these for my tests as they were breadboard friendly!

Rainer

Gesendet von Mail für Windows 10

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

Rainer-G, 2018-12-01:
Here is a picture of the PCB

Gesendet von Mail für Windows 10

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

paysan18, 2018-12-01:
Problem found and case can be closed.

Problem was a solder bridge between the clk pin and ground of the rotary encoder.
Found it by looking at the bootup debug trace. GPIO-25 was LOW and remark was possible no pullup.

paysan18, 2018-12-01:
> Here is a picture of the PCB Gesendet von Mail für Windows 10 Von: Willem Nijntjes Gesendet: Freitag, 30. November 2018 23:38 An: Edzelf/ESP32-Radio Cc: Rainer-G; Comment Betreff: Re: [Edzelf/ESP32-Radio] Rotary encoder question. (#192) Rainer, can I see a picture of your print for this radio please? — You are receiving this because you commented. Reply to this email directly, view it on GitHub, or mute the thread.

Rainer, I don't buy your PCB. I have a different type of ESP32 and VS1053.

paysan18, 2018-12-01:
> Here is a picture of the PCB Gesendet von Mail für Windows 10 Von: Willem Nijntjes Gesendet: Freitag, 30. November 2018 23:38 An: Edzelf/ESP32-Radio Cc: Rainer-G; Comment Betreff: Re: [Edzelf/ESP32-Radio] Rotary encoder question. (#192) Rainer, can I see a picture of your print for this radio please? — You are receiving this because you commented. Reply to this email directly, view it on GitHub, or mute the thread.

I don’t see any picture. Is this the same pcb as sold by Naked Ninja in Roterdam?

paysan18, 2018-12-01:
> Rainer, can I see a picture of your print for this radio please?

Is this the pcb as mentioned in issue #181 ?

Closed 2018-12-01.

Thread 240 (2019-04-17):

VS1053 with SD card on board not working

boerti71, 2019-04-17:
Hi
when I'm using by ESp32 and VS1053 wihtout SD card, everything is working.
when I put in the SD card, I get
VS1053 SPI error. SB:71AC R1:71E0 R2:0000

Do I have to use an additional SD card reader to get this functionality?
Thanks for your help

boerti71, 2019-04-24:
problem solved with workaround -> I buyed a SD card reader and it's working now

Closed 2019-04-24.

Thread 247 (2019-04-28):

Permanent reboot

Milka-Cow, 2019-04-28:
Hi,
my radio works fine since 2 month or so now.
It will start and reboot permanetly.
My son programmed the ESP in the past. He said he could not find any problems.
Also the different SSD are seen if he connect it to his PC.

Starting...
Version January 05 19
Connect to Wifi
Then 192.168.4.1
Starting...

Any idea what I can do?

Edzelf, 2019-04-29:
Reboot is often caused by weak powersupply.
Please try to run the radio with a different powersupply.

Milka-Cow, 2019-04-29:
Hi
before I had a 1A psu, same problem with a quality 2A psu.
Both show 5V with voltmeter, also wiring on pcb is tick enough.

emiklen, 2019-04-29:
i had the same problem, and in my case the cause was the preset station, may be some offending icy metadata, changed preset to another station  and the reboot stopped.

Milka-Cow, 2019-05-03:
@emiklen: The solution do not helped.
My son had time now and he re programmed the chip. Then it worked fine.
So no idea what happend.

Closed 2019-05-03.

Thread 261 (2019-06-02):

LCD1602 communication error

ido1990, 2019-06-02:
Hi,
Thank you for your project!
Just got my parts and started to assemble it.
I'm using small LCD display that is working with Arduino over I2C.
The chip is ST7066 (HD44780 compatible) so it should work like 1602...
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

The LCD is working with this code:
```
/* I2C LCD 16x2 Arduino Tutorial
 * More info http://www.ardumotive.com/i2clcd(en).html
 * Dev: Michalis Vasilakis Date: 19/11/2016 Ver. 1.0 */

//Libraries
#include <Wire.h>
#include <LiquidCrystal_I2C.h>

LiquidCrystal_I2C lcd(0x27, 2, 1, 0, 4, 5, 6, 7, 3, POSITIVE);  // Set the LCD I2C address, if it's not working try 0x27.

void setup(){
  lcd.begin(16,2);   // iInit the LCD for 16 chars 2 lines
  lcd.backlight();   // Turn on the backligt (try lcd.noBaklight() to turn it off)
  lcd.setCursor(0,0); //First line
  lcd.print("Hi!");

}

void loop(){
}
```

But when I connect it to the ESP32 I get an error:
```
E (22037) i2c: /Users/ficeto/Desktop/ESP32/ESP32/esp-idf-public/components/driver/i2c.c:1244 (i2c_master_cmd_begin):i2c driver not installed
D: LCD1602 communication error!
```
And then it crashes:

```

D: LCD1602 communication error!
E (1692) i2c: /Users/ficeto/Desktop/ESP32/ESP32/esp-idf-public/components/driver/i2c.c:1244 (i2c_master_cmd_begin):i2c driver not installed
D: LCD1602 communication error!
E (1707) i2c: /Users/ficeto/Desktop/ESP32/ESP32/esp-idf-public/components/driver/i2c.c:1244 (i2c_master_cmd_begin):i2c driver not installed
D: LCD1602 communication error!
E (1722) i2c: /Users/ficeto/Desktop/ESP32/ESP32/esp-idf-public/components/driver/i2c.c:1244 (i2c_master_cmd_begin):i2c driver not installed
D: LCD1602 communication error!
E (1737) i2c: /Users/ficeto/Desktop/ESP32/ESP32/esp-idf-public/components/driver/i2c.c:1244 (i2c_master_cmd_begin):i2c driver not installed
D: LCD1602 communication error!
E (1752) i2c: /Users/ficeto/Desktop/ESP32/ESP32/esp-idf-public/components/driver/i2c.c:1244 (i2c_master_cmd_begin):i2c driver not installed
D: LCD1602 communication error!
E (1767) i2c: /Users/ficeto/Desktop/ESP32/ESP32/esp-idf-public/components/driver/i2c.c:1244 (i2c_master_cmd_begin):i2c driver not installed
D: LCD1602 communication error!
E (1782) i2c: /Users/ficeto/Desktop/ESP32/ESP32/esp-idf-public/components/driver/i2c.c:1244 (i2c_master_cmd_begin):i2c driver not installed
D: LCD1602 communication error!
E (1797) i2c: /Users/ficeto/Desktop/ESP32/ESP32/esp-idf-public/components/driver/i2c.c:1244 (i2c_master_cmd_begin):i2c driver not installed
D: LCD1602 communication error!
E (23820) i2c: /Users/ficeto/Desktop/ESP32/ESP32/esp-idf-public/components/driver/i2c.c:1244 (i2c_master_cmd_begin):i2c driver not installed
D: LCD1602 communication error!
E (23836) i2c: /Users/ficeto/Desktop/ESP32/ESP32/esp-idf-public/components/driver/i2c.c:1244 (i2c_master_cmd_begin):i2c driver not installed
D: LCD1602 communication error!
Guru Meditation Error: Core  1 panic'ed (Unhandled debug exception)
Debug exception reason: Stack canary watchpoint triggered (Spftask)
Core 1 register dump:
PC      : 0x4008d537  PS      : 0x00060636  A0      : 0x40082bc4  A1      : 0x3ffd4b00
A2      : 0x00000000  A3      : 0x00060623  A4      : 0x00060620  A5      : 0x00000001
A6      : 0x00060423  A7      : 0x00000000  A8      : 0x3ffd5344  A9      : 0x0000abab
A10     : 0x00000000  A11     : 0x4015d9e4  A12     : 0x3ffb8678  A13     : 0x00000080
A14     : 0x00000000  A15     : 0x00000003  SAR     : 0x00000004  EXCCAUSE: 0x00000001
EXCVADDR: 0x00000000  LBEG    : 0x400014fd  LEND    : 0x4000150d  LCOUNT  : 0xfffffff9

Backtrace: 0x4008d537:0x3ffd4b00 0x40082bc1:0x3ffd4bd0 0x4008b43b:0x3ffd4bf0 0x4008b4f9:0x3ffd4c30 0x40081cf9:0x3ffd4c50 0x40081ded:0x3ffd4c80 0x4015da04:0x3ffd4ca0 0x400f4e0b:0x3ffd4cc0 0x4000bd83:0x3ffd4ce0 0x4000117d:0x3ffd4d00 0x400592fe:0x3ffd4d20 0x4005937a:0x3ffd4d40 0x40058b69:0x3ffd4d60 0x40102e31:0x3ffd4d90 0x401085ce:0x3ffd4dc0 0x4010875d:0x3ffd50d0 0x40085eba:0x3ffd5100 0x400ea496:0x3ffd5150 0x400d2c58:0x3ffd5190 0x400d2c86:0x3ffd51b0 0x400d2cb3:0x3ffd51d0 0x400d2cc4:0x3ffd51f0 0x400d2de5:0x3ffd5210 0x400d2ef5:0x3ffd5240 0x400d4abe:0x3ffd5270 0x400d4b42:0x3ffd5290 0x4008a775:0x3ffd52b0

Rebooting...
ets Jun  8 2016 00:22:57

rst:0xc (SW_CPU_RESET),boot:0x13 (SPI_FAST_FLASH_BOOT)
configsip: 0, SPIWP:0xee
clk_drv:0x00,q_drv:0x00,d_drv:0x00,cs0_drv:0x00,hd_drv:0x00,wp_drv:0x00
mode:DIO, clock div:1
load:0x3fff0018,len:4
load:0x3fff001c,len:1100
load:0x40078000,len:9232
load:0x40080400,len:6400
entry 0x400806a8
```
(had to cut lines from the output, it was too long to paste here)

Looking for clues to debug this issue...
Any help would be appreciated :)
Thank you!

Edzelf, 2019-06-02:
The I2C address of your display interface is 0x27, so change the value in line 22 of lcd1602.h from 0x3f to 0x27.

ido1990, 2019-06-02:
>
>
> The I2C address of your display interface is 0x27, so change the value in line 22 of lcd1602.h from 0x3f to 0x27.

Hi Ed!
Already changed it there...

Edzelf, 2019-06-02:
Are the gpio pins correctly set in your preferences?

Edzelf, 2019-06-02:
The i2c adress is shifted one place to the left before it is ised, so try 0x13 and 0x1f.

ido1990, 2019-06-02:
>
>
> Are the gpio pins correctly set in your preferences?

Yes.
This is my config:
```
pin_enc_clk = -1                                     # GPIO Pin number for rotary encoder "CLK"
pin_enc_dt = -1                                     # GPIO Pin number for rotary encoder "DT"
pin_enc_sw = -1                                      # GPIO Pin number for rotary encoder "SW"
pin_ir = 35                                          # GPIO Pin number for IR receiver VS1838B
pin_sd_cs = 21                                       # GPIO Pin number for SD card "CS"
pin_tft_cs = 15                                      # GPIO Pin number for TFT "CS"
pin_tft_dc = 2                                       # GPIO Pin number for TFT "DC"
pin_tft_scl = 33 # GPIO Pin number for SCL
pin_tft_sda = 34 # GPIO Pin number for SDA
pin_vs_cs = 5                                        # GPIO Pin number for VS1053 "CS"
pin_vs_dcs = 32                                      # GPIO Pin number for VS1053 "DCS"
pin_vs_dreq = 4                                      # GPIO Pin number for VS1053 "DREQ"
```
(disabled the rotary encoder for now)

>
>
> The i2c adress is shifted one place to the left before it is ised, so try 0x13 and 0x1f.

Tried now.
Same error.

ido1990, 2019-06-02:
I just noticed that pins 34-36 and 39 are input only.
Changed to 25 and 26.
Now getting this:
```
D: LCD1602 communication error!
D: LCD1602 communication error!
D: LCD1602 communication error!
D: LCD1602 communication error!
D: LCD1602 communication error!
D: LCD1602 communication error!
D: LCD1602 communication error!
D: LCD1602 communication error!
D: LCD1602 communication error!
D: LCD1602 communication error!
D: LCD1602 communication error!
D: LCD1602 communication error!
D: LCD1602 communication error!
D: LCD1602 communication error!
D: LCD1602 communication error!
D: LCD1602 communication error!
D: LCD1602 communication error!
D: LCD1602 communication error!
D: LCD1602 communication error!
D: LCD1602 communication error!
D: LCD1602 communication error!
D: LCD1602 communication error!
D: LCD1602 communication error!
D: LCD1602 communication error!
D: LCD1602 communication error!

```

Edzelf, 2019-06-02:
Try to runthe i2c scan sample project.

ido1990, 2019-06-02:
Ok, so the pins are 22 and 21.
Can't use other pins.
And I had to change the address to 0x27
Thank you so much!

BTW, is there any way to change the text on the screen to the preset name?
Some of my streams doesn't have title...

Edzelf, 2019-06-03:
It would not be so hard to change the screen texts.  It is a good opportunity to learn programming.

ido1990, 2019-06-03:
>
>
> It would not be so hard to change the screen texts. It is a good opportunity to learn programming.

I'll dig into it.
Thank you!

Thoky81, 2020-02-16:
Hi,

can you please post your working code? I am not able to figure out why the lcd is not working even if I dont get any errors.
Thanks

ido1990, 2020-02-16:
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

Hi,
I recommend you to open new issue, yours might be different from what I had.

DanDimnet, 2024-04-07:
Píše mi to stejnou chybu a nevím proč i když mám piny nastavený 21, a 22.

Closed 2019-06-03.

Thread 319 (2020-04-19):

Wifi found, device crashes and device goes back to default AP - endless loop

Gulpman, 2020-04-19:
Hi, I wanted to set up the project and start with nothing connected to the ESP32, to check the general functionality but am not successful.

So when the device boots up it seems to write everything correctly into nvs, boots up again, seems to connect to my network correctly but then crashes and after that is not capable to connect to the net again.

When I do a reset on the ESP32 device, it connects to the network again, crashes and then again gets back to the default AP (ESP32Radio).

Is it neccessary to connect everything (VS1053, display) befor testing?

Here's the log file stripped down to the interesting stuff:
`
D: Command: volume with parameter 72
D: Slow SPI, Testing VS1053 read/write registers...
D: VS1053 not properly installed!
D: Connect to WiFi
D: Connected to MYGUESTNETWORK
D: IP = 192.168.178.149
D: Start server for commands
D: Network found. Starting mqtt and OTA
D: MDNS responder started
D: Rotary encoder is enabled
D: STOP requested
D: New preset/file requested (6/0) from icecast.omroep.nl:80/radio1-bb-mp3
D: Connect to new host icecast.omroep.nl:80/radio1-bb-mp3
D: Connect to icecast.omroep.nl on port 80, extension /radio1-bb-mp3
D: Connected to server
D: Duration mp3loop 1
D: Switch to HEADER
D: Headerline: Content-Type: audio/mpeg
D: audio/mpeg seen.
D: Headerline: icy-br:192
D: Headerline: ice-audio-info: samplerate=48000;channels=2;bitrate=192
D: Headerline: icy-br:192
D: Headerline: icy-genre:Talk
D: Headerline: icy-metadata:1
D: Headerline: icy-name:NPO Radio1
D: Headerline: icy-pub:0
D: Headerline: icy-url:http://www.radio1.nl
D: Headerline: Server: Icecast 2.4.0-kh13
D: Headerline: Cache-Control: no-cache, no-store
D: Headerline: Access-Control-Allow-Origin: *
D: Headerline: Access-Control-Allow-Headers: Origin, Accept, X-Requested-With, Content-Type
D: l-Allow-Headers: Origin, Accept, X-Requested-With, Content-Type seen.
D: Headerline: Access-Control-Allow-Methods: GET, OPTIONS, HEAD
D: Headerline: Connection: Close
D: Headerline: Expires: Mon, 26 Jul 1997 05:00:00 GMT
D: Headerline: icy-metaint:16000
D: Switch to DATA, bitrate is 192, metaint is 16000
D: Duration mp3loop 71
D: Song stopped correctly after 0 msec
D: Duration mp3loop 400
D: Metadata block 96 bytes
D: Streamtitle found, 82 bytes
D: StreamTitle='NPO Radio 1 - De Perstribune: Paul de Leeuw en Sarina Wiegman - MAX';
D: SPI semaphore not taken within 270 ticks by CPU 1, id hspec
D: Semaphore is claimed by chunk
D: SPI semaphore not taken within 280 ticks by CPU 1, id hspec
D: Semaphore is claimed by chunk
D: SPI semaphore not taken within 290 ticks by CPU 1, id hspec
D: Semaphore is claimed by chunk
D: SPI semaphore not taken within 300 ticks by CPU 1, id hspec
D: Semaphore is claimed by chunk
D: SPI semaphore not taken within 310 ticks by CPU 1, id hspec
D: Semaphore is claimed by chunk
[LEAVING OUT THE 10 TICKS INTERVALS UNTIL SOMETHING DIFFERENT IN THE LOG]
D: SPI semaphore not taken within 740 ticks by CPU 1, id hspec
D: Semaphore is claimed by chunk
D: SPI semaphore not taken within 750 ticks by CPU 1, id hspec
D: Semaphore is claimed by chunk
D: SPI semaphore not taken within 760 ticks by CPU 1, id hspec
D: Semaphore is claimed by chunk
D: SPI semaphore not taken within 270 ticks by CPU 1, id hspec
D: Semaphore is claimed by chunk
D: SPI semaphore not taken within 280 ticks by CPU 1, id hspec
D: Semaphore is claimed by chunk
D: SPI semaphore not taken within 290 ticks by CPU 1, id hspec
D: Semaphore is claimed by chunk
E (16610) task_wdt: Task watchdog got triggered. The following tasks did not reset the watchdog in time:
E (16610) task_wdt:  - IDLE0 (CPU 0)
E (16610) task_wdt: Tasks currently running:
E (16610) task_wdt: CPU 0: Playtask
E (16610) task_wdt: CPU 1: loopTask
E (16610) task_wdt: Aborting.
abort() was called at PC 0x400e5613 on core 0

Backtrace: 0x4008cc58:0x3ffbe170 0x4008ce89:0x3ffbe190 0x400e5613:0x3ffbe1b0 0x40084f25:0x3ffbe1d0 0x400e170a:0x3ffd80a0 0x400df619:0x3ffd80c0 0x400d24d4:0x3ffd80e0 0x40089369:0x3ffd8100

Rebooting...
ets Jun  8 2016 00:22:57

rst:0xc (SW_CPU_RESET),boot:0x13 (SPI_FAST_FLASH_BOOT)
configsip: 0, SPIWP:0xee
clk_drv:0x00,q_drv:0x00,d_drv:0x00,cs0_drv:0x00,hd_drv:0x00,wp_drv:0x00
mode:DIO, clock div:1
load:0x3fff0018,len:4
load:0x3fff001c,len:1044
load:0x40078000,len:8896
load:0x40080400,len:5816
entry 0x400806ac

D: Starting ESP32-radio running on CPU 1 at 240 MHz.  Version Mon, 25 Mar 2020 10:45:00 GMT.  Free memory 294132
D: Display type is DUMMYTFT
D: Partition nvs found, 20480 bytes
D: Read 46 keys from NVS
D: pin_ir set to 35
D: pin_enc_clk set to 25
D: pin_enc_dt set to 26
[LEAVING OUT NON INTERESTING sets]
D: gpio_14 will execute stop
D: gpio_17 will execute resume
D: gpio_34 will execute station = icecast.omroep.nl:80/radio1-bb-mp3
D: Enable pin 35 for IR
D: Start display
D: SD Card Mount Failed!
D: Create list with acceptable WiFi networks
D: Added MYGUESTNETWORK to list of networks
D: Added MYNETWORK to list of networks
D: End adding networks
D: Scan Networks
D: Scan completed
D: Number of available networks: 11
D:  1 - MYGUESTNETWORK                   Signal: -68 dBm, Encryption WPA2_PSK, Acceptable
D:  2 - XXXXXXXXXXXXXX             Signal: -77 dBm, Encryption WPA_WPA2_PSK,
D:  3 - XXXXXXXXXXXXXXXX Signal: -77 dBm, Encryption WPA_WPA2_PSK,
D:  4 - XXXXXXXXXX                Signal: -84 dBm, Encryption WPA_WPA2_PSK,
D:  5 - XXXXXXXXXXXXX       Signal: -84 dBm, Encryption ????,
D:  6 - MYREALNETWORK                   Signal: -86 dBm, Encryption WPA2_PSK, Acceptable
[...]
D: Command: tonehf with parameter 0
D: Command: tonela with parameter 0
D: Command: tonelf with parameter 0
D: Command: volume with parameter 72
D: Slow SPI, Testing VS1053 read/write registers...
D: VS1053 not properly installed!
D: Connect to WiFi
D: WiFi Failed!  Trying to setup AP with name ESP32Radio and password ESP32Radio.
D: IP = 192.168.4.1
D: Start server for commands
D: Rotary encoder is enabled
D: STOP requested
D: Song stopped correctly after 0 msec
D: Rotation count -1
D: Rotation count -1
D: Rotation count -1
D: Rotation count -1
`
And then the loop could be started from the beginning.

Just to ensure I flashed everything correctly, here's the output from flashing (from the Arduino IDE Console):
`
C:\Users\sascha\AppData\Local\Arduino15\packages\esp32\tools\esptool_py\2.6.1/esptool.exe --chip esp32 --port COM7 --baud 921600 --before default_reset --after hard_reset write_flash -z --flash_mode dio --flash_freq 80m --flash_size detect 0xe000 C:\Users\sascha\AppData\Local\Arduino15\packages\esp32\hardware\esp32\1.0.4/tools/partitions/boot_app0.bin 0x1000 C:\Users\sascha\AppData\Local\Arduino15\packages\esp32\hardware\esp32\1.0.4/tools/sdk/bin/bootloader_dio_80m.bin 0x10000 C:\Users\sascha\AppData\Local\Temp\arduino_build_147255/Esp32_radio.ino.bin 0x8000 C:\Users\sascha\AppData\Local\Temp\arduino_build_147255/Esp32_radio.ino.partitions.bin
esptool.py v2.6
Serial port COM7
Connecting........_
Chip is ESP32D0WDQ6 (revision 1)
Features: WiFi, BT, Dual Core, 240MHz, VRef calibration in efuse, Coding Scheme None
MAC: 3c:71:bf:1d:5d:84
Uploading stub...
Running stub...
Stub running...
Changing baud rate to 921600
Changed.
Configuring flash size...
Auto-detected Flash size: 4MB
Compressed 8192 bytes to 47...

Writing at 0x0000e000... (100 %)
Wrote 8192 bytes (47 compressed) at 0x0000e000 in 0.0 seconds (effective 3449.3 kbit/s)...
Hash of data verified.
Compressed 15856 bytes to 10276...

Writing at 0x00001000... (100 %)
Wrote 15856 bytes (10276 compressed) at 0x00001000 in 0.1 seconds (effective 868.8 kbit/s)...
Hash of data verified.
Compressed 878496 bytes to 493416...
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
Edzelf, 2020-04-19:
Defaultprefs.h has no effect on the wifi connection.  It is only used when choosing the default setting in the web interface.
The crash can be caused by missing hardware, but this should not effect your NVS data.

fellek, 2020-04-19:
This is the same behavior I got stuck in.
There was an issue at espressif
Containing more specific debug Logs of this crash:

https://github.com/espressif/arduino-esp32/issues/3440

Gulpman, 2020-04-20:
>
>
> Defaultprefs.h has no effect on the wifi connection. It is only used when choosing the default setting in the web interface.
Yes, I did not correctly express: I added it to Defaultprefs.h to have my credentials handy when pressing the default button to ensure there is no typo. Therefore for me it had the indirect effect on wifi settings to reduce possible error sources. :)

> The crash can be caused by missing hardware, but this should not effect your NVS data.
So I will try with he VS1053 connected.

Gulpman, 2020-04-20:
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

I wanted to downgrade the ESP32 package in the IDE but there is no single package. Any idea which package I should downgrade to test if this is the cause?
The code snipplet on the thread you are referring to seems to use Wifi and WifiMulti. I didn't find out how to downgrade those.
Or is there a better solution to the issue?
Any clue?
Thanks,
Sascha

Gulpman, 2020-04-21:
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

OK, fist tests can be run, if the VS1053 is connected (and no other hardware). Without the VS1053 (therefore only the ESP32 with the sketch) I could reproduce the issue on another ESP32 board.

So - issue is solved, however it would be helpful to add this to the documentation, as I think it is natural to test first with the ESP32 only and the compiled sketch running.

Thanks for your help!

Best, Sascha

Edzelf, 2020-04-21:
So I took the ESP32 (WROOM-32) out of the radio and powered it up.
Lots of errors, but no crash.  Web interface works.
Maybe it depends on the defined pins.
My pins:
```
pin_ir = 35                                          # GPIO Pin number for IR receiver VS1838B
pin_sd_cs = 21                                       # GPIO Pin number for SD card "CS"
pin_tft_cs = 15                                      # GPIO Pin number for TFT "CS"
pin_tft_dc = 2                                       # GPIO Pin number for TFT "DC"
pin_vs_cs = 5                                        # GPIO Pin number for VS1053 "CS"
pin_vs_dcs = 16                                      # GPIO Pin number for VS1053 "DCS"
pin_vs_dreq = 4                                      # GPIO Pin number for VS1053 "DREQ"
```

Gulpman, 2020-04-22:
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

Thanks for verifying.
The only thing I changed in the original defaul config, was adding my WLAN network.
Here's the corresponding part for the pins from my config:

`
pin_enc_clk = 25                                     # GPIO Pin number for rotary encoder "CLK"
pin_enc_dt = 26                                      # GPIO Pin number for rotary encoder "DT"
pin_enc_sw = 27                                      # GPIO Pin number for rotary encoder "SW"
pin_ir = 35                                          # GPIO Pin number for IR receiver VS1838B
pin_sd_cs = 21                                       # GPIO Pin number for SD card "CS"
pin_tft_cs = 15                                      # GPIO Pin number for TFT "CS"
pin_tft_dc = 2                                       # GPIO Pin number for TFT "DC"
pin_vs_cs = 5                                        # GPIO Pin number for VS1053 "CS"
pin_vs_dcs = 32                                      # GPIO Pin number for VS1053 "DCS"
pin_vs_dreq = 4                                      # GPIO Pin number for VS1053 "DREQ"
`
I can see in the config you posted, that you altered the pin_vs_dcs to 16 (in the original config it's 32). Apart from that our configs seem to be identically.

I'm using the latest version of Arduino IDE (1.8.12), all libraries and board definitions updated to the latest version.

Anyway, it runs fine now, (with the OLED connected) - only issue I'm having is that the display is not correctly displaying the content but this seems to be an issue with the chip (SSH1106). Will open an extra case for that. :)

Thanks again for investigating!

Best,
Sascha

Closed 2020-04-21.

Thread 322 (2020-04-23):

VS1003 support

20pyro00, 2020-04-23:
Hello,

I accidentaly bought a VS1003 board. I wired everything up, but there is no sound. I also get the error "Song stopped incorrectly!". Is the VS1003 board not working or do i have to change the code? Well if it´s not supported, i have to wait for the VS1053 board to be delivered from China :(

LOG:

ets Jun  8 2016 00:22:57

rst:0x1 (POWERON_RESET),boot:0x17 (SPI_FAST_FLASH_BOOT)
configsip: 0, SPIWP:0xee
clk_drv:0x00,q_drv:0x00,d_drv:0x00,cs0_drv:0x00,hd_drv:0x00,wp_drv:0x00
mode:DIO, clock div:1
load:0x3fff0018,len:4
load:0x3fff001c,len:1216
ho 0 tail 12 room 4
load:0x40078000,len:9720
ho 0 tail 12 room 4
load:0x40080400,len:6352
entry 0x400806b8

D: Starting ESP32-radio running on CPU 1 at 240 MHz.  Version Mon, 25 Mar 2020 10:45:00 GMT.  Free memory 294100
D: Display type is BLUETFT
D: Partition nvs found, 20480 bytes
D: Read 45 keys from NVS
D: pin_ir set to 35
D: pin_enc_clk set to 25
D: pin_enc_dt set to 26
D: pin_enc_sw set to 27
D: pin_tft_cs set to 15
D: pin_tft_dc set to 2
D: pin_tft_scl set to -1
D: pin_tft_sda set to -1
D: pin_tft_bl set to 33
D: pin_tft_blx set to -1
D: pin_sd_cs set to 21
D: pin_vs_cs set to 5
D: pin_vs_dcs set to 32
D: pin_vs_dreq set to 4
D: pin_shutdown set to -1
D: pin_shutdownx set to -1
D: pin_spi_sck set to 18
D: pin_spi_miso set to 19
D: pin_spi_mosi set to 23
D: GPIO0 is HIGH
D: GPIO2 is HIGH
D: GPIO4 is HIGH
D: GPIO5 is HIGH
D: GPIO12 is HIGH
D: GPIO13 is HIGH
D: GPIO14 is HIGH
D: GPIO15 is HIGH
D: GPIO16 is HIGH
D: GPIO17 is HIGH
D: GPIO18 is HIGH
D: GPIO19 is HIGH
D: GPIO21 is HIGH
D: GPIO22 is HIGH
D: GPIO23 is HIGH
D: GPIO25 is HIGH
D: GPIO26 is HIGH
D: GPIO27 is HIGH
D: GPIO32 is HIGH
D: GPIO33 is HIGH
D: GPIO34 is LOW, probably no PULL-UP
D: GPIO35 is LOW, probably no PULL-UP
D: GPIO39 is LOW, probably no PULL-UP
D: gpio_00 will execute uppreset = 1
D: gpio_12 will execute upvolume = 2
D: gpio_13 will execute downvolume = 2
D: gpio_14 will execute stop
D: gpio_17 will execute resume
D: gpio_34 will execute station = 212.83.149.66:8591/stream
D: Enable pin 35 for IR
D: Start display
D: SD Card Mount Failed!
D: Create list with acceptable WiFi networks
D: Added Repeater2 to list of networks
D: Added NETGEAR56 to list of networks
D: Added TOBISOnePlus6 to list of networks
D: End adding networks
D: Scan Networks
D: Scan completed
D: Number of available networks: 7
D:  1 - Repeater2                 Signal: -78 dBm, Encryption WPA2_PSK, Acceptable
D:  2 - FRITZ!Box 7560 RA         Signal: -89 dBm, Encryption WPA2_PSK,
D:  3 - Loitsche_A                Signal: -90 dBm, Encryption WPA2_PSK,
D:  4 - DIRECT-8b-HP M477 LaserJet Signal: -90 dBm, Encryption WPA2_PSK,
D:  5 - Telekom_FON               Signal: -91 dBm, Encryption OPEN,
D:  6 - HP-Print-58-Officejet 4630 Signal: -93 dBm, Encryption OPEN,
D:  7 - WLAN-NN5Y5H               Signal: -93 dBm, Encryption WPA2_PSK,
D: End of list
D: Command: clk_dst with parameter 1
D: Command: clk_offset with parameter 1
D: Command: clk_server with parameter pool.ntp.org
D: Command: gpio_00 with parameter uppreset = 1
D: Command: gpio_12 with parameter upvolume = 2
D: Command: gpio_13 with parameter downvolume = 2
D: Command: gpio_14 with parameter stop
D: Command: gpio_17 with parameter resume
D: Command: gpio_34 with parameter station = 212.83.149.66:8591/stream
D: Command: ir_40bf with parameter upvolume = 2
D: Command: ir_c03f with parameter downvolume = 2
D: Command: mqqprefix with parameter none
D: Command: mqttbroker with parameter none
D: Command: mqttpasswd with parameter *******
D: Command: mqttport with parameter 1883
D: Command: mqttuser with parameter none
D: Command: pin_enc_clk with parameter 25
D: Command: pin_enc_dt with parameter 26
D: Command: pin_enc_sw with parameter 27
D: Command: pin_ir with parameter 35
D: Command: pin_sd_cs with parameter 21
D: Command: pin_tft_cs with parameter 15
D: Command: pin_tft_dc with parameter 2
D: Command: pin_vs_cs with parameter 5
D: Command: pin_vs_dcs with parameter 32
D: Command: pin_vs_dreq with parameter 4
D: Command: preset with parameter 6
D: Command: preset_00 with parameter 149.56.151.181:9992/stream
D: Command: preset_01 with parameter 78.31.65.20:8080/dance.mp3
D: Command: preset_02 with parameter 51.89.148.171:8022/stream
D: Command: preset_03 with parameter 159.89.121.179:80/192k
D: Command: preset_04 with parameter 145.239.91.167:8010
D: Command: preset_05 with parameter 37.187.93.104:8589/deep
D: Command: preset_06 with parameter 5.39.71.159:8704/stream
D: Command: preset_07 with parameter 5.39.71.159:8243/stream
D: Command: preset_08 with parameter 212.83.149.66:8591/stream
D: Command: preset_09 with parameter 136.243.4.79:8055/stream
D: Command: toneha with parameter 0
D: Command: tonehf with parameter 0
D: Command: tonela with parameter 0
D: Command: tonelf with parameter 0
D: Command: volume with parameter 0
D: Slow SPI, Testing VS1053 read/write registers...
D: This is not a VS1053, but a VS1003 instead!
D: Connect to WiFi
D: Connected to Repeater2
D: IP = 192.168.1.10
D: Start server for commands
D: Network found. Starting mqtt and OTA
D: MDNS responder started
D: Rotary encoder is enabled
D: Sync TOD
D: Sync TOD, new value is 12:15:55
D: STOP requested
D: New preset/file requested (6/0) from 5.39.71.159:8704/stream
D: Connect to new host 5.39.71.159:8704/stream
D: Connect to 5.39.71.159 on port 8704, extension /stream
D: Connected to server
D: Duration mp3loop 1
D: Switch to HEADER
D: Headerline: Accept-Ranges:none
D: Headerline: Access-Control-Allow-Origin:*
D: Headerline: Cache-Control:no-cache,no-store,must-revalidate,max-age=0
D: Headerline: Connection:close
D: Headerline: icy-name:DI Radio Digital Impulse - Global Trance Channel
D: Headerline: icy-genre:Electronic
D: Headerline: icy-br:320
D: Headerline: icy-sr:44100
D: Headerline: icy-url:http://www.di-radio.com
D: Headerline: icy-pub:1
D: Headerline: content-type:audio/mpeg
D: audio/mpeg seen.
D: Headerline: icy-metaint:8192
D: Headerline: X-Clacks-Overhead:GNU Terry Pratchett
D: Switch to DATA, bitrate is 320, metaint is 8192
D: Duration mp3loop 46
D: Metadata block 64 bytes
D: Streamtitle found, 59 bytes
D: StreamTitle='ATLAS CORPORATION - Into The Dreamland [Roj]';
D: SPI semaphore not taken within 270 ticks by CPU 1, id hspec
D: Semaphore is claimed by stopsong
D: SPI semaphore not taken within 280 ticks by CPU 0, id hspec
D: Semaphore is claimed by stopsong
D: SPI semaphore not taken within 290 ticks by CPU 0, id hspec
D: Semaphore is claimed by stopsong
D: SPI semaphore not taken within 300 ticks by CPU 0, id hspec
D: Semaphore is claimed by stopsong
D: SPI semaphore not taken within 310 ticks by CPU 0, id hspec
D: Semaphore is claimed by stopsong
D: SPI semaphore not taken within 320 ticks by CPU 0, id hspec
D: Semaphore is claimed by stopsong
D: SPI semaphore not taken within 330 ticks by CPU 0, id hspec
D: Semaphore is claimed by stopsong
D: Song stopped incorrectly!
D: REG   Contents
D: ---   -----
D: SPI semaphore not taken within 340 ticks by CPU 1, id hspec
D: Semaphore is claimed by stopsong
D:   0 -   808
D:   1 -    33
D: SPI semaphore not taken within 350 ticks by CPU 0, id hspec
D: Semaphore is claimed by stopsong
D:   2 -     0
D:   3 -     0
D: SPI semaphore not taken within 360 ticks by CPU 0, id hspec
D: Semaphore is claimed by stopsong
D:   4 -     0
D:   5 -  1F40
D: SPI semaphore not taken within 370 ticks by CPU 0, id hspec
D: Semaphore is claimed by stopsongD:   6 -     0
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
Edzelf, 2020-04-23:
You may try to delete line 906 ( "okay = false ").  But please read other issues on using the VS1003.

20pyro00, 2020-04-23:
Oh wow! Thanks for the fast answer. And with the code changed it works! Thank you so much. But now i have a new problem. The Audio is very choppy. I think it is Network related, but i am not sure. Is there a way to increase the streanght of the signal?

Here are examples:
https://youtu.be/VBua80It10A
https://youtu.be/dXYTvYK-Dpw

When i load a 320kbps Stream, i get this:

D: Command client available
D: handlehttp started
D: Get command is: station=radiocp.from-dc.com:1290
D: Send reply for station=radiocp.from-dc.com:1290
D: Command: station with parameter radiocp.from-dc.com:1290
D: STOP requested
D: Stopping client
D: Connect to new host radiocp.from-dc.com:1290
D: Connect to radiocp.from-dc.com on port 1290, extension /
D: Connected to server
D: Switch to HEADER
D: Headerline: Accept-Ranges:none
D: Headerline: Access-Control-Allow-Origin:*
D: Headerline: Cache-Control:no-cache,no-store,must-revalidate,max-age=0
D: Headerline: Connection:close
D: Headerline: icy-name:deep wave - deep/dub/electronic/indie - https://deepwaveradio.fr/
D: Headerline: icy-genre:Electronic
D: Headerline: icy-br:320
D: Headerline: icy-sr:44100
D: Headerline: icy-url:https://www.deepwaveradio.fr
D: Headerline: icy-pub:1
D: Headerline: content-type:audio/mpeg
D: audio/mpeg seen.
D: Headerline: icy-metaint:32768
D: Headerline: X-Clacks-Overhead:GNU Terry Pratchett
D: Switch to DATA, bitrate is 320, metaint is 32768
D: SPI semaphore not taken within 270 ticks by CPU 0, id hspectft
D: Semaphore is claimed by stopsong
D: SPI semaphore not taken within 280 ticks by CPU 0, id hspectft
D: Semaphore is claimed by stopsong
D: SPI semaphore not taken within 290 ticks by CPU 0, id hspectft
D: Semaphore is claimed by stopsong
D: SPI semaphore not taken within 300 ticks by CPU 0, id hspectft
D: Semaphore is claimed by stopsong
D: SPI semaphore not taken within 310 ticks by CPU 0, id hspectft
D: Semaphore is claimed by stopsong
D: SPI semaphore not taken within 320 ticks by CPU 0, id hspectft
D: Semaphore is claimed by stopsong
D: SPI semaphore not taken within 330 ticks by CPU 0, id hspectft
D: Semaphore is claimed by stopsong
D: SPI semaphore not taken within 340 ticks by CPU 0, id hspectft
D: Semaphore is claimed by stopsong
D: SPI semaphore not taken within 350 ticks by CPU 0, id hspectft
D: Semaphore is claimed by stopsong
D: SPI semaphore not taken within 360 ticks by CPU 0, id hspectft
D: Semaphore is claimed by stopsong
D: SPI semaphore not taken within 370 ticks by CPU 0, id hspectft
D: Semaphore is claimed by stopsong
D: SPI semaphore not taken within 380 ticks by CPU 0, id hspectft
D: Semaphore is claimed by stopsong
D: SPI semaphore not taken within 390 ticks by CPU 0, id hspectft
D: Semaphore is claimed by stopsong
D: SPI semaphore not taken within 400 ticks by CPU 0, id hspectft
D: Semaphore is claimed by stopsong
D: SPI semaphore not taken within 410 ticks by CPU 0, id hspectft
D: Semaphore is claimed by stopsong
D: Song stopped incorrectly!
D: REG   Contents
D: ---   -----
D:   0 -   808
D: SPI semaphore not taken within 420 ticks by CPU 0, id hspectft
D: Semaphore is claimed by stopsongD:   1 -    33

D:   2 -     0
D:   3 -  6000
D: SPI semaphore not taken within 430 ticks by CPU 0, id hspectft
D: Semaphore is claimed by stopsong
D:   4 -   116
D:   5 -  AC44
D: SPI semaphore not taken within 440 ticks by CPU 0, id hspectft
D: Semaphore is claimed by stopsong
D:   6 -  10C2
D:   7 -  1E06
D: SPI semaphore not taken within 450 ticks by CPU 0, id hspectft
D: Semaphore is claimed by stopsongD:   8 -     0

D:   9 -     0
D:   A -     0
D: SPI semaphore not taken within 460 ticks by CPU 0, id hspectft
D: Semaphore is claimed by stopsong
D:   B -  F8F8
D:   C -     0
D: SPI semaphore not taken within 470 ticks by CPU 0, id hspectft
D: Semaphore is claimed by stopsong
D:   D -     0
D:   E -     0
D: SPI semaphore not taken within 480 ticks by CPU 0, id hspectft
D: Semaphore is claimed by stopsongD:   F -     0

What are all the semaphore-tick-things?

Thanks
Tobias

Closed 2020-04-24.

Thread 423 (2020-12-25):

White Noise

B4stl3r, 2020-12-25:
Hi,

I used the schematics from https://github.com/Edzelf/ESP32-Radio/issues/66 and also used the transistors.

I still have some "white noise" left, which might come from the ESP itself. https://electronics.stackexchange.com/questions/368867/esp32-microcontroller-generates-noise-on-microphone
You can hear it very clearly until ~30% of max volume..

I tried serveral things, from using 2 different power supplys, also both of the  VS1053 Lineout solution (which still has then the white noise issue). https://www.sparkfun.com/datasheets/Widgets/MP3Trigger/vs10XXan_output.pdf
Also tried several different amplifiers (but all class D)..

Will or want to use the PAM8610 in future.

Do you have the same isse or have any filtering solution inplace ?

Thanks in advance!

Edzelf, 2020-12-25:
It is unlikely that the noise comes from the ESP32.  The problem must be in the VS0153 or in the analog circuit.  I never noticed a significant noise.  Did you try a headphone on the VS105e output?

utw3v0, 2020-12-25:
You could try an audio transfomer like the Monacor LTR110, that should help.

Greets

⁣TypeApp for Android herunterladen

Am 25. Dez. 2020, 11:23, um 11:23, Bastler <notifications@github.com> schrieb:
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

B4stl3r, 2020-12-25:
yep, had the headset before..
unfortunately cannot remember if the issue already existed there..

removed the 3.5 connection and using pins instead right now.

B4stl3r, 2020-12-25:
@utw3v0 i've already transformers in place.

here's what it currently looks like:
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

utw3v0, 2020-12-25:
maybe a grounding problem .... theres a digital and a analog ground can you try to seperate them ? And maybe the esp is too close to the vs1053 so it might generate some em interterence ....

⁣TypeApp for Android herunterladen

Am 25. Dez. 2020, 12:22, um 12:22, Bastler <notifications@github.com> schrieb:
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

B4stl3r, 2020-12-25:
hi @utw3v0 , already read alot about it, but was not very clear, how i shoud seperate it.

also from the pcb layout of eXadra, i do not see, where the grounds are seperated.

also variated the distance between VS, ESP and SD reader with unfortunately no difference..

would love to give it a try, but don't really have a cloud, what i should do.. Maybe you could give me some further advise?

thanks!!

utw3v0, 2020-12-25:
I'll give you my schematic, it works like a charm, theres an sd - card connection a well a ch376 wired but that's optional ...

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

Greets Werner

utw3v0, 2020-12-25:
i've just seen on your picture that the vs1053 the esp and your am are hooked up to the same power source, try to separate them, at least your amp (8610) and the rest ...

B4stl3r, 2020-12-25:
Hi Werner,

thx for providing your schematic, unfortunately it's still the same background noise :(

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

I also tried it with a second powersource for the amp (and also amp + vs), but issue keeps the same..

maybe my VS1053 is broken ?

utw3v0, 2020-12-25:
I dont think that your vs is broken, i kicked out all of my breadboards, had always trouble with the cabling so i chose to solder everything, maybe you mic is activated and its amp is generating the noise ? Maybe your pam is making the noise it self ? Try a headphone without anything else except the esp ofc. Remove all unnecessary cables / modules .... my board pulls with ch chip and sd card up to 460 mA so your powersupply should deliver that on the 5 volts rail ... i use an powersupply for laboratory so its generating clean 5 volts with very low ripple try an pc speaker system to see if there is the noice too

utw3v0, 2020-12-25:
Maybe you can make a video of the problem ?

utw3v0, 2020-12-25:
Ive just seen your 5v and 12v gnd is connected via bridge, you should remove that bridge so the both grounds are not connected to each other

B4stl3r, 2020-12-25:
Hi Werner,

thats what also my plan is, already preparing my perforated board, but with that white noise, i dont want to solder it..

just tried to record a video, just have an old iphone 5, sry ..
https://youtu.be/cPeA3fRwi4I

The bridge does not matter if its going into the gnd of the 5V DC DC converter or directly..

Pam alone is absolutely silent.. just when i hook up everything together, this noise appears..

Maybe its still with the differentiated outputs of the VS1053?

found this..
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

Edzelf, 2020-12-25:
Meassure the pgnd pin, that is the common of the 2 analog outputs, with a voltmeter.  It should be half the power voltage.  If it is is 0 Volt, you are in trouble.

B4stl3r, 2020-12-25:
measure between what exactly ?

https://www.mouser.com/datasheet/2/115/PAM8610-247304.pdf

Edzelf, 2020-12-25:
Between ground of your power supply and the pgnd pin of the vs1053.

Edzelf, 2020-12-25:
Meassure with pam connected and removed.

B4stl3r, 2020-12-25:
assume between GND and VS1053 GBuf (audiojack out) ?
it's always around 1,4xx V, regardless if PAM connected or not..

Edzelf, 2020-12-25:
That's good.  So it looks like it is not a wiring problem.  Next thing to do is to replace the vs1053.

B4stl3r, 2020-12-25:
dont have another one around :(

Rainer-G, 2020-12-26:
Did you try with a larger capacitor ( 220µ or more ) on each power rail? I could not see any decoupling capacitor on your breadbord.
If I put digital and analog circuits on such a breadboard, I found it a good practice to add capacitors for decouplig.
Good luck
Rainer

B4stl3r, 2020-12-26:
Morning Rainer,

assume like this?

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

unfortunately no change.

utw3v0, 2020-12-26:
Unfortunately in your video theres no noise su i guess it's the same problem like in this video https://www.youtube.com/watch?v=4bm22sN5hWE Im going in to a preamp and then an poweramp 100Watts and its working fine i also had it hooked up directly to the poweramp no problems at all ....

B4stl3r, 2020-12-26:
Hi Werner,

you can hear the noise starting with 0:05.. its not a "loud" noise or cracking noise, its just rustling..

without the transformators its the same thing as in your posted vid but i'm using already audio transformators and still have some rustling left..

utw3v0, 2020-12-26:
Maybe its your vs then but i can't imagine the chip is very solid and stable i soldered one and made my self mp3 decoder as you can see in my schematics without any disturbing noise ... its a weird thing .... can you post your schematics ? What if the esp and the vs are all alone ? Still that noise ? Maybe shorter wires i could pickup an interference from another source around your setup ....

Rainer-G, 2020-12-26:
On your last picture, I can see that the ESP32 Board is not connected via USB to the PC, is that the case in all other testing scenarios?
I'm asking because I had problems with setup ( Adafruit HUZZA32 and Adafruit VS1053, no tranformers, connected to a Tripath amplifier ). When conneted to the PC, I had some noise when volume was zero, it disappeared when I unplugged the USB cable!
I have one VS1053 board left from my first tries before I switched to the Adafruit board.
I you want, I can give it to you free of charge if you let me know your address.
If there are no private messages possible an ED agrees, you can send him your E-Mail address and he can send it to me or pass my address to you.
Cheers
Rainer

B4stl3r, 2020-12-26:
Hi Werner,

i also cannot assume that the vs is broken right now.. currently i'm switching my schematics all the time to find the issue..
i could really think that the esp32 is creating so much noise that it will interfere with the VS and therefore i'm getting noise in my audio. dont have a oszi around to measure that..

Hi Rainer,
yes, i never connect the PC to the ESP.. code is already running, therefore no need to connect it to the pc.
thanks for your offer, will come back to you if there's no other choice!

another option i think about is to lift the VREF pin from the PAM8610 and solder the GBUF to it as mentioned in a post above..

really wired.. trying around for several weeks now, really getting annoyed why i always have bad luck and issues that no one else is facing..

B4stl3r, 2020-12-26:
maybe another idea..

i regulate the volume on the VS1053, maybe this can be the root cause?

as you also might have a poti onboard, does this poti regulate the amplifier input? or do you connect it to the ESP and regulate the volume also on the VS1053?

utw3v0, 2020-12-26:
I can regulate from both, vs and preamp doesn't make a difference .....

B4stl3r, 2020-12-26:
when you set the VS to <10% max volume and the amp to 100%, do you have then noise ?

utw3v0, 2020-12-26:
Because of the ltr110 coils i can hear a sound when the volume goes over 50% everything else is too weak but theres absolutely nothing disturbing
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
xP373Rx, 2021-02-06:
Well on init i also have some heavy noise coming out of the vs  before it is iniatlized as output. WHat i did  since i alos have a bluetoothmodule connected via relays on the output side.  I switch the relays on after init.

xP373Rx, 2021-02-06:
What yxou also could do is pin the mute pin with a 10k resitor to off state  and turn it on after init with pin that is not doing any funny stuff on esp boot

xP373Rx, 2021-05-05:
I found a solution to the spi humming in the audio if using amplifiers..

Do not use the audio GND from the jack .. use the real GND pin on the board and put  100nf or 220 nf  caps in series with the L and R channels to the input of the  amp.

B4stl3r, 2021-11-27:
Hi @xP373Rx
I don't use GND (it's GBuf) from the Headphone Jack, I just use L + R with capacitors in series to the amp input.

when playing a silent mp3 file (https://bigsoundbank.com/detail-0917-one-minute-of-silence.html) I still have lot of noise..

When music is playing, you basically cant hear and pink noise.

Maybe you can give it a try.

xP373Rx, 2021-11-27:
Gbuf seems to have some resistance  which is making it picking up some of the spi signals..   better to connect to GND and  put 2  ceramic caps on L and R.

xP373Rx, 2021-11-27:
the noise is on the Gbuf not in the channel
 try GND to input and  LR with ceramics

B4stl3r, 2021-11-27:
Hi, here's a quick drawing of my connections:
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

xP373Rx, 2021-11-27:
Can you run the esp32  from the 3.3 v VS rail??
Because i belive that is where the  stuff commes from 2 different 3.2 step down  converter

B4stl3r, 2021-11-27:
The VS1053 has a 3.3V Rail ? Thought it requires 5V to run?

Or do you think about grabbing the convertet 3.3V after the "onboard" regulator from the VS Board?

Can it handle the additional Load from the ESP ?

xP373Rx, 2021-11-27:
Esp it self runs on 3.3v  if u connect 3.3v to the 3.3v pin of the board it will run

B4stl3r, 2021-11-27:
sure the esp will run on 3.3, but what you had in mind with the 3.3v rail of the VS ?

Regulator is a ams1117 t33 f16lc
http://www.advanced-monolithic.com/pdf/ds1117.pdf
should be safe to handle the esp in addition, as output is 1A.. correct?

how did you power esp and vs ?

clear-sky, 2023-02-12:
high all
i am 99% sure using Isolated DC/DC Converters like B0505S will kill this noise please see
https://www.youtube.com/watch?v=n_b_0BWP0mI
i am looking to find this converter in market

Edzelf, 2023-02-12:
Yes, but they are usually only 1 Watt.  If you can find a 3 Watt type it will certainly work.

B4stl3r, 2023-02-12:
just use 600:600 transformers.. what works totally fine!

no need for a B0503S, but could indeed also work.

clear-sky, 2023-02-12:
is that possible to use it in digital side?  (esp + vs1053 + tft)

B4stl3r, 2023-02-12:
what? the transformers or the DC/DC ?

I use a 12V Powersupply with a Stepdown for ESP + VS, the Audio between VS and the Amp are isolated with the transformers.

Using a TFT shouldn't make any difference.

clear-sky, 2023-02-12:
dc/dc
in my previous project i made a fm radio and clock with tft-when using radio with showing clock on tft can hear noise when second or minute or every thing  else make changes on tft

Closed 2022-09-28.

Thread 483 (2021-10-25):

Hanging on starting

ilioSS53, 2021-10-25:
Hi Ed,
At the moment I started to build a new radio with the naked ninja pcb.
Programming with performio succeded. Lots of errors but the code is uploaded.
The startup is stopped at starting...
Only the display is connected.
Do I need to remove the not used rotary encoder, sdcard etc.lines?
It is not possible to reach the page 192.168.4.1 or ESP32Radio?
Also my old ssid was loaded?? This is an old problem which can be solved by entrring the new ssid via the webpage correct?
Like to hear.
Kind regards
ilioSS

ilioSS53, 2021-11-01:
Hi Ed,

The latest esp32 radio with search function is a  piece from a next level. Realy amazing. With a smile all kind of music at hand. I enjoy it.
Regards ilioSS

Outlook voor Android<https://aka.ms/AAb9ysg> downloaden

ilioSS53, 2021-11-02:
Hello Ed,
After one night printing here my new ESP32 radio.
Greetz ilioSS

Outlook voor Android<https://aka.ms/AAb9ysg> downloaden

Edzelf, 2021-11-02:
Where?
And please remove Outlook advertisement.

ilioSS53, 2021-11-02:
Hi Ed,
Sorry ads. Switched off.
Photo didnot come with the e-mail?
Here it is.
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
Regards ilioSS

ilioSS53, 2021-11-17:
Hi Ed,

I,am a bit confused.
The "old" version appeared to have lost his SD card function?
During start-up SD card not displayed.
In the menu it is mentioned?

Already some test done no sigh of recognition of the SD card.

Is the SD card no longer in the system?

Like to hear ilioSS

Note: the new radio 3D printed last for just a couple of weeks. For a better sound I filled the casing with demping material. After al a bad ideer. The ESP32 is burn-out.

Closed 2021-11-02.

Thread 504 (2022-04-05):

Audio lag, large delay on playback

tsctrl, 2022-04-05:
hi Ed!

i had issue where audio is lagging. it is 2s playback and then 10s silence and playback again for 2s then silence back.

i have use the provided pcb and check the connection. i am using usb to power the esp and did not attach the 220uf and 470uf caps for now to test.

i am on master branch. compiled and flash successfully to the original esp32 devkit. the internet radio link just play nicely on web browser.

the rotary encoder dail is not working as expected, i am using a 3x 10k ohm rotary encoder. only able to mute and unmute. 2 or 3 press will display channel selection but turning the knob does not change the channel on display.

thanks!

tsctrl, 2022-04-05:
update,
i have use V2 with the same result.

1. checkout v2
2. reset and upload config and data
3. connect to ESP32-Radio wifi
4. reset config to default
5. enter my wifi uname and password
6. restart and listen to NPO Radio1

result: large delay on playback as above.

Edzelf, 2022-04-05:
Can you disconnect the rotary switch.  Maybe this is causing the trouble.

tsctrl, 2022-04-06:
i have disconnected the rotary encoder. ir sensor, lcd and only retain the vs1053.restarted the device
i still having the same issue.

Edzelf, 2022-04-06:
With the "test" command in the serial interface you can see some stream info.  If there is a low number of bytes in the stream, you have a network problem.  Try a different network.

tsctrl, 2022-04-06:
hi @Edzelf, how low is low? i am streaming the url directly in web browser using the same network as the esp32 is connected and it play smoothly in browser.

wondering if there is any variable or settings i could change to tweak or play around to get the optimal stream. other than that what else i could do to check?

thanks!

tsctrl, 2022-04-06:
could you point the code part where the stream was transfered to the spi? any way i could increase the buffer?

tsctrl, 2022-04-06:
Here some console logs:

D: Connect to new host 109.206.96.34:8100
D: Connect to 109.206.96.34 on port 8100, extension /
D: Connected to server
D: Switch to HEADER
D: Headerline: icy-name:NAXI LOVE RADIO (NAXI,Belgrade,Serbia, NAXI,Beograd,Srbija) - 128k
D: Headerline: icy-genre:Love and Romance
D: Headerline: icy-url:http://www.naxi.rs
D: Headerline: content-type:audio/mpeg
D: audio/mpeg seen.
D: Headerline: icy-pub:0
D: Headerline: icy-metaint:8192
D: Headerline: icy-br:128
D: Switch to DATA, bitrate is 128, metaint is 8192
D: Duration mp3loop 35
D: Metadata block 48 bytes
D: Streamtitle found, 47 bytes
D: StreamTitle='Ja biram sta slusam';StreamUrl='';
D: Command client available
D: handlehttp started
D: Get command is: status
D: Send reply for status
D: Command: status with parameter 0
D: Command client available
D: handlehttp started
D: Get command is: status
D: Send reply for status

D: Command: test with parameter 0
D: Stack maintask is 6008
D: Stack playtask is 92
D: Stack spftask  is 600
D: ADC reading is 0
D: scaniocount is 10
D: Max. mp3_loop duration is 35
D: 0 IR interrupts seen
D: Free memory is 218192, chunks in queue 97, stream 0, bitrate 3435518 kbps
D: Duration mp3loop 1
D: Duration mp3loop 4
D: Duration mp3loop 6
D: Command client available
D: handlehttp started
D: Get command is: status
D: Send reply for status
D: Command: status with parameter 0
D: Duration mp3loop 7

tsctrl, 2022-04-06:
tested most of the preset and radio in the search list with the same results

Edzelf, 2022-04-06:
As you can see, there is no input in the stream.  So try a different network.
`D: Free memory is 218192, chunks in queue 97, stream 0, bitrate 3435518 kbps`

Edzelf, 2022-04-06:
Try a different network.

tsctrl, 2022-04-07:
i have tried to place the module just beside the internet router to get the strongest signal and tried with other wifi network too. mobile hotspot and different fibre internet with the same lag.

Rainer-G, 2022-04-07:
<!--
/* Font Definitions */
@font-face
	{font-family:"Cambria Math";
	panose-1:2 4 5 3 5 4 6 3 2 4;}
@font-face
	{font-family:Calibri;
	panose-1:2 15 5 2 2 2 4 3 2 4;}
/* Style Definitions */
p.MsoNormal, li.MsoNormal, div.MsoNormal
	{margin:0cm;
	font-size:11.0pt;
	font-family:"Calibri",sans-serif;}
a:link, span.MsoHyperlink
	{mso-style-priority:99;
	color:blue;
	text-decoration:underline;}
.MsoChpDefault
	{mso-style-type:export-only;}
@page WordSection1
	{size:612.0pt 792.0pt;
	margin:70.85pt 70.85pt 2.0cm 70.85pt;}
div.WordSection1
	{page:WordSection1;}
-->Hi when you disconnected the Encoder, did you also set the Encoder Pins data and cklock in the config web page to -1, this will disable Interrupts caused by open Input Pins. Rainer Gesendet von Mail für Windows Von: tsctrlGesendet: Donnerstag, 7. April 2022 12:31An: Edzelf/ESP32-RadioCc: SubscribedBetreff: Re: [Edzelf/ESP32-Radio] Audio lag, large delay on playback (Issue #504) i have tried to place the module just beside the internet router to get the strongest signal and tried with other wifi network too. mobile hotspot and different fibre internet with the same lag.—Reply to this email directly, view it on GitHub, or unsubscribe.You are receiving this because you are subscribed to this thread.Message ID: ***@***.***> 

tsctrl, 2022-04-09:
Hi @Rainer-G ,

thank you and appreciate your reply. i updated pin definition in config to -1 as below:
D: Command: pin_enc_clk with parameter -1
D: Command: pin_enc_dt with parameter -1
D: Command: pin_enc_sw with parameter -1

and pull the rotary decoder off but still have the same issue.
I also tried with open hotspot from my pc connected to gbit lan, the esp is very close to the pc hotspot but still having the same lag issue.

probably my vs chip is fake? or i guess this is something related to the how the wifi connection is fetching the stream and how the stream is feed to the vs1053. probably require some logic where how many byte was in buff and how it is transferred to the vs1053. i also have tweaks esp hardware related wifi configuration to enable more rx buffer, speed optimization, enable features like ampdu tx and also set the esp signal strength to the max but still with the same issue.

tsctrl, 2022-04-09:
Hi @Edzelf

below is my startup logs:
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
Rainer-G, 2022-04-10:
<!--
/* Font Definitions */
@font-face
	{font-family:"Cambria Math";
	panose-1:2 4 5 3 5 4 6 3 2 4;}
@font-face
	{font-family:Calibri;
	panose-1:2 15 5 2 2 2 4 3 2 4;}
/* Style Definitions */
p.MsoNormal, li.MsoNormal, div.MsoNormal
	{margin:0cm;
	font-size:11.0pt;
	font-family:"Calibri",sans-serif;}
a:link, span.MsoHyperlink
	{mso-style-priority:99;
	color:blue;
	text-decoration:underline;}
.MsoChpDefault
	{mso-style-type:export-only;}
@page WordSection1
	{size:612.0pt 792.0pt;
	margin:70.85pt 70.85pt 2.0cm 70.85pt;}
div.WordSection1
	{page:WordSection1;}
-->One more: are you sure that the power supply below is isolated? I cannot see any transformer to isolate the input from the output???If there is no isolation you will definitely need the audio transformers. Rainer Gesendet von Mail für Windows Von: tsctrlGesendet: Sonntag, 10. April 2022 16:37An: Edzelf/ESP32-RadioCc: Rainer-G; MentionBetreff: Re: [Edzelf/ESP32-Radio] Audio lag, large delay on playback (Issue #504) hi @Rainer-G , thank you for the tips, look like couldnt avoid to use the 3.5mm jack interface to the pam. it looks improper to connect both component (vs-pam) using the 3.5mm jack and crimping 3.5jack with wire are so frustrating. thats one of the reason i hopefully does not have to use any 3.5mm audio jack on my setup. any way of using isolated power or a transformer couldnt help me to solve the 3.5mm jack setup. where i am wondering the picture i shared previously install pam transformer and vs in a single board without require 3.5mm jack or ot is actually required but not installed by @Edzelf in the dic image.i have bought a isolated psu 5-15v recomended by Ed in the doc as this one to try but it havent arrive yetalso a audio transformer too:would like to see how it goes. hope i did not have to use any of this component and could accept the audio quality without it. so far i am satisfied with direct external amp output from vs. i havent use speakers with pam. i guess using pam could be the cause of the audio quality issue mentioned. i still have lots to try to decide.would like to know what kind of isolated 12v power u are using. thanks again!—Reply to this email directly, view it on GitHub, or unsubscribe.You are receiving this because you were mentioned.Message ID: ***@***.***> 

tsctrl, 2022-04-10:
thanks @Rainer-G, will add the isolation as seems it is required. i will check the option how it is done in VS1053 Feather board too.

closing this issue as resolved.

Closed 2022-04-10.

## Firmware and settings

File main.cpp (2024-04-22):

//***************************************************************************************************
//*  ESP32_Radio V2 -- Webradio receiver for ESP32, VS1053 MP3 module and optional display.         *
//*                    By Ed Smallenburg.                                                           *
//***************************************************************************************************
// ESP32 libraries used:  See platformio.ini
// A library for the VS1053 (for ESP32) is not available (or not easy to find).  Therefore
// a class for this module is derived from the maniacbug library and integrated in this sketch.
// The Helix codecs for MP3 and AAC are taken from Wolle (schreibfaul1), see:
// https://github.com/schreibfaul1/ESP32-audioI2S
//
// See http://www.internet-radio.com for suitable stations.  Add the stations of your choice
// to the preferences through the webinterface.
// You may also use the "search" page of the webinterface to find stations.
//
// Brief description of the program:
// First a suitable WiFi network is found and a connection is made.
// Then a connection will be made to a shoutcast server.  The server starts with some
// info in the header in readable ascii, ending with a double CRLF, like:
//  icy-name:Classic Rock Florida - SHE Radio
//  icy-genre:Classic Rock 60s 70s 80s Oldies Miami South Florida
//  icy-url:http://www.ClassicRockFLorida.com
//  content-type:audio/mpeg
//  icy-pub:1
//  icy-metaint:32768          - Metadata after 32768 bytes of MP3-data
//  icy-br:128                 - in kb/sec (for Ogg this is like "icy-br=Quality 2"
//
// After de double CRLF is received, the server starts sending mp3- or Ogg-data.  For mp3, this
// data may contain metadata (non mp3) after every "metaint" mp3 bytes.
// The metadata is empty in most cases, but if any is available the content will be
// presented on the TFT.
// Pushing an input button causes the player to execute a programmable command.
//
// The display used is a Chinese 1.8 color TFT module 128 x 160 pixels.
// Now there is room for 26 characters per line and 16 lines.
// Software will work without installing the display.
// Other displays are also supported. See documentation.
// For configuration of the WiFi network(s): see the global data section further on.
//
// The VSPI interface is used for VS1053, TFT and SD.
//
// Wiring. Note that this is just an example.  Pins (except 18, 19 and 23 of the SPI interface)
// can be configured in the config page of the web interface.
//
// ESP32dev Signal  Wired to LCD        Wired to VS1053      AI Audio board    Wired to the rest
// -------- ------  --------------      -------------------  ---------------   ------------------------
// GPIO32           -                   pin 1 XDCS           I2C Clock
// GPIO33           -                   -                    I2C Data
// GPIO5            -                   pin 2 XCS            KEY 6             -
// GPIO4            -                   pin 4 DREQ           AMPLIFIER_ENABLE  -
// GPIO2            pin 3 D/C or A0     -                    SPI_MISO          -
// GPIO16   RXD2    -                   -                                      TX of NEXTION (if in use)
// GPIO17   TXD2    -                   -                                      RX of NEXTION (if in use)
// GPIO18   SCK     pin 5 CLK or SCK    pin 5 SCK            KEY 5             -
// GPIO19   MISO    -                   pin 7 MISO           KEY 3             -
// GPIO23   MOSI    pin 4 DIN or SDA    pin 6 MOSI           KEY 4             -
// GPIO15           pin 2 CS            -                    SPI_MOSI          -
// GPIO3    RXD0    -                   -                                      Reserved serial input
// GPIO1    TXD0    -                   -                                      Reserved serial output
// GPIO34   -       -                   -                    SD detect         Optional pull-up resistor
// GPIO35   -       -                   -                                      Infrared receiver VS1838B
// GPIO25   -       -                   -                    I2S DSIN          Rotary encoder CLK
// GPIO26   -       -                   -                    I2S LRC           Rotary encoder DT
// GPIO27   -       -                   -                    I2S BCLK          Rotary encoder SW
// GPIO13   -       -                   -                    SD card CS        -
// GPIO14   -       -                   -                    SPI_SCK           -
// GPIO36   -       -                   -                    KEY 1             -
// GPIO13   -       -                   -                    KEY 2             -
// GPIO19   -       -                   -                    KEY 3             -
// GPIO23   -       -                   -                    KEY 4             -
// GPIO18   -       -                   -                    KEY 5             -
// GPIO05   -       -                   -                    KEY 6             -
// -------  ------  ---------------     -------------------                    ----------------
// GND      -       pin 8 GND           pin 8 GND                              Power supply GND
// VCC 5 V  -       pin 7 BL            -                                      Power supply
// VCC 5 V  -       pin 6 VCC           pin 9 5V                               Power supply
// EN       -       pin 1 RST           pin 3 XRST                             -
//
//  History:
//   Date     Author        Remarks
// ----------  --  ------------------------------------------------------------------
// 06-08-2021, ES: Copy from version 1.
// 06-08-2021, ES: Use SPIFFS and Async webserver.
// 23-08-2021, ES: Version with software MP3/AAC decoders.
// 05-10-2021, ES: Fixed internal DAC output, fixed OTA update.
// 06-10-2021, ES: Fixed AP mode.
// 10-02-2022, ES: Included ST7789 display.
// 11-02-2022, ES: SD card implementation.
// 26-03-2022, ES: Fixed NEXTION bug.
// 12-04-2022, ES: Fixed dataqueue bug (NEXT function).
// 13-04-2022, ES: Fixed redirect bug (preset was reset), fixed playlist.
// 14-04-2022, ES: Added posibility for a fixed WiFi network.
// 15-04-2022, ES: Redesigned station selection.
// 25-04-2022, ES: Support for WT32-ETH01 (wired Ethernet).
// 13-05-2022, ES: Correction I2S settings.
// 15-05-2022, ES: Correction mp3 list for web interface.
// 17-11-2022, ES: Support of AI Audio kit V2.1.
// 22-11-2022, ES: Fixed memory leak.
// 28-04-2023, ES: Correct "Request station:port failed!"
// 10-05-2023, ES: SD card files stored on the SDcard.
// 19-05-2023, ES: Mute and unmute with 2 buttons or commands.
// 22-05-2023, ES: Use internal mutex for SPI bus.
// 16-06-2023, ES: Add sleep commmeand.
// 09-10-2023, ES: Reduce GPIO errors by checking GPIO pins.
// 14-12-2023, ES: Add mqtt trigger to refresh all items.
// 16-01-2024, ES: Disable brownout.
// 16-02-2024, ES: SPDIFF output (experimental).
// 19-02-2024, ES: Fixed mono stream, correct handling of reset command.

//
// Define the version number, the format used is the HTTP standard.
#define VERSION     "Wed, 06 Mar 2024 16:00:00 GMT"
//
#include <Arduino.h>                                      // Standard include for Platformio Arduino projects
#include "soc/soc.h"                                      // For brown-out detector setting
#include "soc/rtc_cntl_reg.h"                             // For brown-out detector settingtest
//#include <esp_log.h>
#include <WiFi.h>
#include "config.h"                                       // Specify display type, decoder type
#include <nvs.h>                                          // Access to NVS
#include <PubSubClient.h>                                 // MTTQ access
#ifdef ETHERNET
  #include <ETH.h>                                        // Definitions for Ethernet controller
  //#include <AsyncWebServer_WT32_ETH01.h>
  #define ETH_CLK_MODE    ETH_CLOCK_GPIO0_IN              // External clock from crystal oscillator
  #define ETH_TYPE        ETH_PHY_LAN8720                 // Type of controller
  #define ETH_ADDR        1                               // I2C address of Ethernet PHY
#else
  #include <WiFiMulti.h>                                  // Handle multiple WiFi networks
  WiFiMulti wifiMulti ;                                   // Object for WiFiMulti
#endif
#include <ESPAsyncWebServer.h>                            // For Async Web server
#include <ESPmDNS.h>                                      // For multicast DNS
#include <time.h>                                         // Time functions
#include <SPI.h>                                          // For SPI handling
#ifdef ENABLEOTA
  #include <ArduinoOTA.h>                                 // Over the air updates
#endif
#include <freertos/queue.h>                               // FreeRtos queue support
#include <freertos/task.h>                                // FreeRtos task handling
#include <esp_task_wdt.h>
#include <driver/adc.h>
#include <base64.h>                                       // For Basic authentication
#include <SPIFFS.h>                                       // Filesystem
#include "utils.h"                                        // Some handy utilities
#if defined(DEC_HELIX_SPDIF) || defined(DEC_HELIX_INT) || defined(DEC_HELIX_AI)
  #define DEC_HELIX
#endif
#if defined(DEC_HELIX_AI)                                 // AI Audio kit board?
  #include <AC101.h>
  #define GPIO_PA_EN 21                                   // GPIO for enabling amplifier
  AC101 dac ;                                             // AC101 controls
#endif
#if defined(DEC_HELIX)
  #include <driver/i2s.h>                                 // Driver for I2S output
  #include "mp3_decoder.h"                                // Yes, include libhelix_HMP3DECODER
  #include "aac_decoder.h"                                // and libhelix_HAACDECODER
  #include "helixfuncs.h"                                 // Helix functions
#else
  #include "VS1053.h"                                     // Driver for VS1053
#endif
#define MAXKEYS           200                             // Max. number of NVS keys in table
#define FSIF              true                            // Format SPIFFS if not existing
#define QSIZ              400                             // Number of entries in the MP3 stream queue
#define NVSBUFSIZE        150                             // Max size of a string in NVS
// Access point name if connection to WiFi network fails.  Also the hostname for WiFi and OTA.
// Note that the password of an AP must be at least as long as 8 characters.
// Also used for other naming.
#ifndef NAME                                              // Name may be defined in config.h
  #define NAME            "ESP32-Radio"
#endif
#define MAXPRESETS        200                             // Max number of presets in preferences
#define MAXMQTTCONNECTS   5                               // Maximum number of MQTT reconnects before give-up
#define METASIZ           1024                            // Size of metaline buffer
#define BL_TIME           45                              // Time-out [sec] for blanking TFT display (BL pin)
//
// Subscription topics for MQTT.  The topic will be pefixed by "PREFIX/", where PREFIX is replaced
// by the the mqttprefix in the preferences.  The next definition will yield the topic
// "ESP32Radio/command" if mqttprefix is "ESP32Radio".
#define MQTT_SUBTOPIC     "command"                      // Command to receive from MQTT
//
#define heapspace heap_caps_get_largest_free_block ( MALLOC_CAP_8BIT )

//**************************************************************************************************
// Forward declaration and prototypes of various functions.                                        *
//**************************************************************************************************
void        tftlog ( const char *str, bool newline = false ) ;
bool        showstreamtitle ( const char* ml, bool full = false ) ;
void        handlebyte_ch ( uint8_t b ) ;
void        handleCmd()  ;
const char* analyzeCmd ( const char* str ) ;
const char* analyzeCmd ( const char* par, const char* val ) ;
void        chomp ( String &str ) ;
String      nvsgetstr ( const char* key ) ;
bool        nvssearch ( const char* key ) ;
void        sdfuncs() ;
void        stop_mp3client () ;
void        tftset ( uint16_t inx, const char *str ) ;
void        tftset ( uint16_t inx, String& str ) ;
void        playtask ( void* parameter ) ;                 // Task to play the stream on VS1053 or HELIX decoder
void        displayinfo ( uint16_t inx ) ;
void        gettime() ;
void        reservepin ( int8_t rpinnr ) ;
uint32_t    ssconv ( const uint8_t* bytes ) ;
void        scan_content_length ( const char* metalinebf ) ;
void        handle_notfound  ( AsyncWebServerRequest *request ) ;
void        handle_getprefs  ( AsyncWebServerRequest *request ) ;
void        handle_saveprefs ( AsyncWebServerRequest *request ) ;
void        handle_getdefs   ( AsyncWebServerRequest *request ) ;
void        handle_settings  ( AsyncWebServerRequest *request ) ;
void        handle_mp3list   ( AsyncWebServerRequest *request ) ;
void        handle_reset     ( AsyncWebServerRequest *request ) ;
bool        readhostfrompref ( int16_t preset, String* host, String* hsym = NULL ) ;



//**************************************************************************************************
// Several structs and enums.                                                                      *
//**************************************************************************************************
//

enum qdata_type { QDATA, QSTARTSONG, QSTOPSONG,       // datatyp in qdata_struct,
                  QSTOPTASK } ;
struct qdata_struct                                   // Data in queue for playtask (dataqueue)
{
  qdata_type                          datatyp ;       // Identifier
  __attribute__((aligned(4))) uint8_t buf[32] ;       // Buffer for chunk of mp3 data
} ;
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
void loop()
{
  if ( resetreq )                                   // Reset requested?
  {
    vTaskDelay ( 1000 / portTICK_PERIOD_MS ) ;      // Yes, wait some time
    timerDetachInterrupt ( timer ) ;
    timerEnd ( timer ) ;
    ESP.restart() ;                                 // Reboot
  }
  if ( sleepreq )                                   // Request for deep sleep?
  {
    if ( dsp_ok )                                   // TFT configured?
    {
      dsp_erase() ;                                 // Yes, clear screen
      dsp_update ( true ) ;                         // To physical screen
    }
    esp_deep_sleep_start() ;                        // Yes, sleep until reset
    // No return here...
  }
  scanserial() ;                                    // Handle serial input
  scanserial2() ;                                   // Handle serial input from NEXTION (if active)
  scandigital() ;                                   // Scan digital inputs
  scanIR() ;                                        // See if IR input
  #ifdef ENABLEOTA
    ArduinoOTA.handle() ;                           // Check for OTA
  #endif
  if ( mqtt_on )                                    // Need to handle MQTT?
  {
    mqttclient.loop() ;                             // Handling of MQTT connection
  }
  handleSaveReq() ;                                 // See if time to save settings
  handleIpPub() ;                                   // See if time to publish IP
  handleVolPub() ;                                  // See if time to publish volume
  chk_enc() ;                                       // Check rotary encoder functions
  radiofuncs() ;                                    // Handle start/stop commands for icecast
  spfuncs() ;                                       // Handle special functions
  sdfuncs() ;                                       // Do SD card related functions
  if ( testreq )
  {
    const char* sformat = "Stack %-8s is %4d\n" ;
    testreq = false ;
    // heap_caps_print_heap_info ( MALLOC_CAP_8BIT ) ;
    log_printf ( sformat, pcTaskGetTaskName ( maintask ),
                 uxTaskGetStackHighWaterMark ( maintask ) ) ;
    log_printf ( sformat, pcTaskGetTaskName ( xplaytask ),
                 uxTaskGetStackHighWaterMark ( xplaytask ) ) ;
    #ifdef SDCARD
      log_printf ( sformat, pcTaskGetTaskName ( xsdtask ),
                 uxTaskGetStackHighWaterMark ( xsdtask ) ) ;
    #endif
    log_printf ( "ADC reading is %d, filtered %d\n", adcvalraw, adcval ) ;
    log_printf ( "%d IR interrupts seen\n", ir_intcount ) ;
    if ( pin_exists ( ini_block.sd_detect_pin ) )
    {
      if ( digitalRead ( ini_block.sd_detect_pin ) == LOW )
      {
        log_printf ( "SD card detected\n" ) ;
      }
    }
  }
  delay ( 10 ) ;
}


//**************************************************************************************************
//                             D E C O D E _ S P E C _ C H A R S                                   *
//**************************************************************************************************
// Decode special characters like "&#39;".                                                         *
//**************************************************************************************************
String decode_spec_chars ( String str )
{
  int    inx, inx2 ;                                // Indexes in string
  char   c ;                                        // Character from string
  char   val ;                                      // Converted character
  String res = str ;

  while ( ( inx = res.indexOf ( "&#" ) ) >= 0 )     // Start sequence in string?
  {
    inx2 = res.indexOf ( ";", inx ) ;               // Yes, search for stop character
    if ( inx2 < 0 )                                 // Stop character found
    {
      break ;                                       // Malformed string
    }
    res = str.substring ( 0, inx ) ;                // First part
    inx += 2 ;                                      // skip over start sequence
    val = 0 ;                                       // Init result of 
    while ( ( c = str[inx++] ) != ';' )             // Convert character
    {
      val = val * 10 + c - '0' ;
    }
    res += ( String ( val ) +                       // Add special char to string
             str.substring ( ++inx2 ) ) ;           // Add rest of string
  }
  return res ;
}


//**************************************************************************************************
//                                    C H K H D R L I N E                                          *
//**************************************************************************************************
// Check if a line in the header is a reasonable headerline.                                       *
// Normally it should contain something like "icy-xxxx:abcdef".                                    *
//**************************************************************************************************
bool chkhdrline ( const char* str )
{
  char    b ;                                         // Byte examined
  int     len = 0 ;                                   // Lengte van de string

  while ( ( b = *str++ ) )                            // Search to end of string
  {
    len++ ;                                           // Update string length
    if ( ! isalpha ( b ) )                            // Alpha (a-z, A-Z)
    {
      if ( b != '-' )                                 // Minus sign is allowed
      {
        if ( b == ':' )                               // Found a colon?
        {
          return ( ( len > 5 ) && ( len < 70 ) ) ;    // Yes, okay if length is okay
        }
        else
        {
          return false ;                              // Not a legal character
        }
      }
    }
  }
  return false ;                                      // End of string without colon
}


//**************************************************************************************************
//                            S C A N _ C O N T E N T _ L E N G T H                                *
//**************************************************************************************************
// If the line contains content-length information: set clength (content length counter).          *
//**************************************************************************************************
void scan_content_length ( const char* metalinebf )
{
  if ( strstr ( metalinebf, "Content-Length" ) )        // Line contains content length
  {
    clength = atoi ( metalinebf + 15 ) ;                // Yes, set clength
    ESP_LOGI ( TAG, "Content-Length is %d", clength ) ; // Show for debugging purposes
  }
}
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

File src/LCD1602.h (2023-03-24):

//***************************************************************************************************
//*  LCD1602.h -- Driver for LCD 1602 display with I2C backpack.                                    *
//***************************************************************************************************
// The backpack communicates with the I2C bus and converts the serial data to parallel for the      *
// 1602 board.  In the serial data, the 8 bits are assigned as follows:                             *
// Bit   Destination  Description                                                                   *
// ---   -----------  ------------------------------------                                          *
//  0    RS           H=data, L=command                                                             *
//  1    RW           H=read, L=write.  Only write is used.                                         *
//  2    E            Enable                                                                        *
//  3    BL           Backlight, H=on, L=off.  Always on.                                           *
//  4    D4           Data bit 4                                                                    *
//  5    D5           Data bit 5                                                                    *
//  6    D6           Data bit 6                                                                    *
//  7    D7           Data bit 7                                                                    *
//***************************************************************************************************
//
// Note that the display function are limited due to the minimal available space.

#include <driver/i2c.h>

#define I2C_ADDRESS 0x3F                                     // Adjust for your display
#define ACKENA      true                                     // Enable ACK for I2C communication
// Color definitions for the TFT screen (if used)
#define BLACK   0
#define BLUE    1
#define RED     1
#define GREEN   0
#define CYAN    GREEN | BLUE
#define MAGENTA RED | BLUE
#define YELLOW  RED | GREEN
#define WHITE   RED | GREEN | BLUE

#define DELAY_ENABLE_PULSE_SETTLE    50      // Command requires > 37us to settle
#define FLAG_BACKLIGHT_ON    0b00001000      // Bit 3, backlight enabled (disabled if clear)
#define FLAG_ENABLE          0b00000100      // Bit 2, Enable
#define FLAG_RS_DATA         0b00000001      // Bit 0, RS=data (command if clear)
#define FLAG_RS_COMMAND      0b00000000      // Command

#define COMMAND_CLEAR_DISPLAY               0x01
#define COMMAND_RETURN_HOME                 0x02
#define COMMAND_ENTRY_MODE_SET              0x04
#define COMMAND_DISPLAY_CONTROL             0x08
#define COMMAND_FUNCTION_SET                0x20
#define COMMAND_SET_DDRAM_ADDR              0x80
//
#define FLAG_DISPLAY_CONTROL_DISPLAY_ON     0x04
#define FLAG_DISPLAY_CONTROL_CURSOR_ON      0x02
//
#define FLAG_FUNCTION_SET_MODE_4BIT         0x00
#define FLAG_FUNCTION_SET_LINES_2           0x08
#define FLAG_FUNCTION_SET_DOTS_5X8          0x00
//
#define FLAG_ENTRY_MODE_SET_ENTRY_INCREMENT 0x02
#define FLAG_ENTRY_MODE_SET_ENTRY_SHIFT_ON  0x01
//
// Various macro's to mimic the ST7735 version of display functions
#define dsp_setRotation()                                          // Use standard landscape format
#define dsp_print(a)                                               // Print a string 
#define dsp_println(a)                                             // Print string plus newline
#define dsp_fillRect(a,b,c,d,e)                                    // Fill a rectange
#define dsp_setTextSize(a)                                         // Set the text size
#define dsp_setTextColor(a)                              
#define dsp_setCursor(a,b)                                         // Position the cursor
#define dsp_erase()         tft->sclear()                          // Clear the screen
#define dsp_getwidth()      16                                     // Get width of screen
#define dsp_getheight()     2                                      // Get height of screen
#define dsp_usesSPI()       false                                  // Does not use SPI

#define TFTSECS 4                                           // 4 sections, only 2 used
scrseg_struct     tftdata[TFTSECS] =                        // Screen divided in 4 segments
{
  { false, WHITE,   0,  0, "" },                            // 1 top line (dummy)
  { false, WHITE,   0,  0, "" },                            // 8 lines in the middle
  { false, WHITE,   0,  0, "" },                            // 4 lines at the bottom
  { false, WHITE,   0,  0, "" }                             // 4 lines at the bottom for rotary encoder
} ;

class LCD1602
{
  public:
                     LCD1602 ( uint8_t sda, uint8_t scl ) ; // Constructor
    void             print ( char c ) ;                     // Send 1 char
    void             reset() ;                              // Perform reset
    void             sclear() ;                             // Clear the screen
    void             shome() ;                              // Go to home position
    void             scursor ( uint8_t col, uint8_t row ) ; // Position the cursor
    void             scroll ( bool son ) ;                  // Set scroll on/off
  private:
    i2c_config_t     i2c_config ;                           // I2C configuration
    i2c_cmd_handle_t hnd ;                                  // Handle for driver
    void             scommand ( uint8_t cmd ) ;
    void             strobe ( uint8_t cmd ) ;
    void             swrite ( uint8_t val, uint8_t rs ) ;
    void             write_cmd ( uint8_t val ) ;
    void             write_data ( uint8_t val ) ;
    uint8_t          bl  = FLAG_BACKLIGHT_ON ;              // Backlight in every command
    uint8_t          xchar = 0 ;                            // Current cursor position (text)
    uint8_t          ychar = 0 ;                            // Current cursor position (text)
} ;

LCD1602* tft = NULL ;

bool dsp_begin()
{
  dbgprint ( "Init LCD1602, I2C pins %d,%d", ini_block.tft_sda_pin,
             ini_block.tft_scl_pin ) ;
  if ( ( ini_block.tft_sda_pin >= 0 ) &&
       ( ini_block.tft_scl_pin >= 0 ) )
  {
    tft = new LCD1602 ( ini_block.tft_sda_pin,
                        ini_block.tft_scl_pin ) ;           // Create an instance for TFT
  }
  else
  {
    dbgprint ( "Init LCD1602 failed!" ) ;
  }
  return ( tft != NULL ) ;
}
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

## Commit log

2017-11-27 archive/Esp32_radio_1.ino
    Version 13-nov-2017
2018-04-24 Move sketch to appropriately named subfolder
    The Arduino IDE requires that a sketch be located in a folder of the same name. Although the name of the repository does match the sketch name, when GitHub's popular Clone or download > Download ZIP 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
    When opening a file that does not meet this sketch/folder name matching requirement the Arduino IDE presents a dialog:
    The file "Esp32_radio.ino" needs to be inside a sketch folder named "Esp32_radio".
    Create this folder, move the file, and continue?
    After clicking "OK" the Arduino IDE currently moves only the file Esp32_radio.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
2021-02-25 Correction OLED driver.
2021-04-25 Add files via upload
    Fixed playlist bug
    [main.cpp]
2022-04-25 Add files via upload
    Added WT32-ETH0 support (wired network)
2023-03-22 Add files via upload
    Clean-up code, correct Nextion pins conjfiguration.
    [example config.ed.txt, example config.txt]
2023-03-22 Update README.md
    Correct Nextion pin configuration
2023-03-22 Update example config.ed.txt
    [example config.ed.txt]
2023-03-22 Delete ESP32-radio.pdf
    Moved to doc directory
2023-03-24 Repair last upload
    [example config.ed.txt]
